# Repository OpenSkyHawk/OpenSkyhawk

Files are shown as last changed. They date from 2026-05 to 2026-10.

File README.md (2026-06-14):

```
  ____                ______        __ __            __  
 / __ \___  ___ ___  / __/ /____ __/ // /__ __    __/ /__
/ /_/ / _ \/ -_) _ \_\ \/  '_/ // / _  / _ `/ |/|/ /  '_/
\____/ .__/\__/_//_/___/_/\_\\_, /_//_/\_,_/|__,__/_/\_\ 
    /_/                     /___/                        
          ── DCS A-4E Skyhawk Home Cockpit ──
```

Physical DCS A-4E Skyhawk home cockpit — 3D-printed panels, custom PCBs, and STM32 firmware for the [DCS A-4E Community Mod](https://github.com/Community-A-4E/community-a4e-c). Controllers communicate over CAN bus.

## Repository Structure

```
OpenSkyhawk/
├── CAD/                        # Fusion 360 source files (.f3d); STLs gitignored
│   ├── Center_Console/
│   ├── Left_Console/
│   ├── Right_Console/
│   └── Shared/                 # Common brackets, mounting fixtures
│
├── PCB/                        # KiCad projects, one folder per board
│   ├── Center_Console/
│   │   └── Center_Armament/
│   │       ├── Armament_MCU/   # Main STM32 board
│   │       ├── AWRS_Panel/     # Breakout board
│   │       └── Misc_Switch_Panel/
│   ├── Left_Console/
│   ├── Right_Console/
│   └── Libraries/              # Shared KiCad symbols and footprints
│
├── Firmware/                   # PlatformIO projects, one folder per STM32 controller
│   ├── Center_Armament/
│   └── Libraries/              # Shared firmware code
│
└── docs/
    ├── References/             # Cockpit photos, manuals, screenshots
    ├── Datasheets/             # Component datasheets
    └── claude/                 # AI-readable architecture and standards docs
```

## Architecture

Each physical panel group is driven by one **STM32F103CBT6** MCU board. Boards communicate over **CAN bus** via Molex Mini-Fit Jr connectors. Panel breakout boards connect to their MCU board via 6- or 8-pin JST-XH harnesses. Firmware is built with **PlatformIO**.

DCS communication: DCS-BIOS cockpit state flows PC → USB CDC → RP2040 bridge (Tiny2040) → UART → STM32 CAN master → CAN bus → all avionics nodes. STM32 native USB CDC is not used — it crashes under sustained DCS-BIOS load.

## Console Layout

| Console | Panels |
|---|---|
| Center Console | Armament, AWRS, Misc Switches, main flight instruments |
| Left Console | ECM, fuel, electrical systems |
| Right Console | Radios, nav |

## Hardware Notes

### Screw Standards

| Size | Use |
|---|-----|
| M2 | PCB mounts, small standoffs |
| M3 | Placards, light rings, small brackets |
| M4 | Instrument bezels, gauge mounting — clearance Ø4.3–4.5 mm |
| M5 | Panel-to-subpanel, corner mounts — clearance Ø5.3–5.5 mm |

### Switch Sizing

- Toggle switches: 12 mm (standard panels), ~6 mm (ECM modules)

### Gauges

- LOX gauge: 2-5/8″ (~67 mm total)
- Radar Altimeter: 3-1/8″ (~100 mm total with bezel)

## Licensing

Copyright (c) 2026 OpenSkyHawk.

| Layer | License |
|---|---|
| CAD, PCB, Docs | CC BY-NC-SA 4.0 — root [LICENSE](./LICENSE) |
| Firmware | GPL v2 (DCS-BIOS dependency) — [Firmware/LICENSE](./Firmware/LICENSE) |

GitHub's repo-level badge reflects the root `LICENSE` (CC BY-NC-SA 4.0); the
firmware is GPL v2 under `Firmware/LICENSE`.

## References

- [Open Hornet Hardware](https://github.com/jrsteensen/OpenHornet)
- [Open Hornet Software](https://github.com/jrsteensen/OpenHornet-Software)
- [The Warthog Project](https://thewarthogproject.com/)
- [Viperpits](https://www.viperpits.org/smf/index.php)
- [The Skyhawk Association — Cockpit](https://skyhawk.org/page/skyhawk-cockpit)

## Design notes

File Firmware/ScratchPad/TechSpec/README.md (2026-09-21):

# TechSpec — Technical Specifications

## Purpose

This directory contains per-library and per-class technical specifications for the OpenSkyhawk
firmware. Each file defines the *how* — public API, class structure, method signatures, file
layout, and implementation notes.

**FirmwarePlan/** defines the *what* (contracts, data flows, design decisions).
**TechSpec/** defines the *how* (concrete code structure, ready for implementation).

---

## Relationship to FirmwarePlan

Every TechSpec file references one or more FirmwarePlan documents. The FirmwarePlan is the
authority on behaviour — if there is a conflict between a TechSpec and FirmwarePlan, the
FirmwarePlan wins and the TechSpec must be updated.

FirmwarePlan files live at:
`Firmware/ScratchPad/FirmwarePlan/`

---

## How to Write a TechSpec

Each file follows this structure:

```markdown
# <ClassName> — Technical Specification

**Status:** Not started | In progress | Ready for implementation | Done
**FirmwarePlan ref:** <path to relevant FirmwarePlan file(s) and section>
**Depends on:** <list of other TechSpec files that must be implemented first>

---

## Responsibility
One paragraph — what this class does and what it does NOT do.

## File Layout
Header and source file names, directory location in the repo.

## Public API
Full class declaration with all public methods, constructors, and constants.
Include parameter types, return types, and a one-line description per method.

## Key Data Structures
Any structs, enums, or typedefs owned by this class.

## Implementation Notes
Non-obvious details: timing, ISR constraints, register sequences, library quirks.

## Dependencies
External libraries, other OpenSkyhawk classes, platform requirements.
```

Testing is continuous throughout implementation — not a separate phase or document.
Each class should be exercisable in isolation before integration. Build test sketches
alongside the library as you go.

---

## Timing Standard

Each class that needs timing calls `millis()` directly and maintains its own `uint32_t`
timestamp. There is no shared clock or centralized `now` on STM32Board.

`millis()` on STM32 reads a 32-bit hardware counter — effectively free. Multiple calls
within one loop iteration return values microseconds apart, which is irrelevant at the
timing granularity used here (debounce ~20 ms, blink 250 ms+, heartbeat 500 ms).

This keeps each class fully self-contained. A Switch2Pos has no dependency on STM32Board
just to debounce a pin.

---

## Code Documentation — Docblock Standard

All header files use **Doxygen-style docblocks**. This applies to every public class, method,
enum, and non-obvious constant. Private members use plain `//` comments.

### Format

```cpp
/**
 * @brief One-line summary of what this does.
 *
 * Optional longer description for non-obvious behaviour, constraints, or side effects.
 * Omit if the brief is sufficient.
 *
 * @param name     Description of the parameter.
 * @param other    Description of another parameter.
 * @return         What the function returns, and what values mean.
 * @note           Non-obvious constraint or timing requirement.
 */
```

### Rules

- **Every public method gets a `@brief`** — even if it seems obvious.
- **`@param` for every parameter** — include units where relevant (ms, Hz, steps).
- **`@return` when the return value is non-trivial** — omit for `void`.
- **`@note` for ISR/timing/threading constraints** — e.g. "must not be called from ISR".
- **Enums:** document the enum with a `/** @brief */` block; document each value with `///< inline`.
- **Constants:** one-line `///` or `///<` inline comment is sufficient.

### Example

```cpp
/** @brief CAN bus health states reported to STM32Board via onCanStatus(). */
enum class CanStatus {
    STARTING,   ///< CAN peripheral configured but not yet started
    NORMAL,     ///< Bus active, no errors
    TX_ERROR,   ///< TEC > 0 — transmit errors accumulating
    BUS_OFF,    ///< CAN controller halted — bus-off condition
};

class CANProtocol {
public:
    /**
     * @brief Start the CAN peripheral and enable receive filters.
     *
     * Must be called after STM32Board::begin(). Sets status to NORMAL on success
     * and fires the registered onStatusChange callback.
     */
    static void start();

    /**
     * @brief Register a callback invoked whenever CAN bus status changes.
     * @param cb Function pointer called with the new CanStatus value.
     * @note Callback is called from the CAN RX interrupt — keep it short.
     */
    static void onStatusChange(void (*cb)(CanStatus));
};
```

---

## Status Tracking

Each file has a **Status** field in its header. Valid values:

| Status | Meaning |
|---|---|
| `Not started` | Placeholder only — spec not yet written |
| `In progress` | Spec being written |
| `Ready for implementation` | Spec complete — can be handed off for coding |
| `Implementing` | Code being written |
| `Done` | Implemented and tested |

---

## Implementation Order

Dependencies flow downward — implement in this order:

```
HIDControls         (no dependencies — platform-agnostic header; shared by STM32 and RP2040)
A4EC                (no dependencies — generated by running tools/gen_a4ec/gen_a4ec.py)
CANProtocol         (depends on HIDControls — includes HIDControls.h)
STM32Board          (depends on CANProtocol for the CanStatus event type)
  ↑ implement HIDControls first; then A4EC and CANProtocol (either order); then STM32Board
PanelBridge         (depends on CANProtocol, STM32Board, A4EC)
SimGateway          (depends on HIDControls — CTRL_* constants used in sketch declarations)
  ↑ build the bridge/gateway backbone before the large PanelGroup surface
  └── PanelGroup/
        ├── PinRef              (no dependencies)
        ├── PanelGroup          (depends on PinRef, CANProtocol, STM32Board;
        │                         owns MCP23017 integration via external library)
        ├── Inputs/
        │     ├── Switch2Pos              (depends on PinRef, PanelGroup)
        │     ├── Switch3Pos              (depends on PinRef, PanelGroup)
        │     ├── SwitchMultiPos          (depends on PinRef, PanelGroup)
        │     ├── AnalogMultiPos          (depends on PinRef, PanelGroup)
        │     ├── ActionButton            (depends on PinRef, PanelGroup)
        │     ├── SwitchWithCover2Pos     (depends on Switch2Pos — protected emit() hook)
        │     ├── RotaryEncoder           (depends on PinRef, PanelGroup)
        │     ├── RotaryAcceleratedEncoder (depends on RotaryEncoder — family member, D16)
        │     ├── AnalogInput             (depends on PinRef, PanelGroup)
        │     └── AngleSensorInput        (depends on AnalogInput, PinRef)
        │         (AngleSensor = future PinRef backend for a digital I²C read — see AngleSensor.md)
        │     (RotarySwitch dropped — D16)
        ├── Drivers/
              │     ├── MotorDriver       (abstract base — depends on PanelGroup)
              │     └── StepperMotor      (depends on MotorDriver, PinRef, PanelGroup)
        └── Outputs/
              ├── LED                     (depends on PinRef, PanelGroup)
              ├── AnalogOutput            (abstract family base — depends on PanelGroup; D16)
              │     ├── Dimmer            (depends on AnalogOutput, PinRef — PWM backlight)
              │     └── IntegerOutput     (depends on AnalogOutput — user callback)
              └── NeedleGauge             (depends on PanelGroup, Drivers/MotorDriver + StepperMotor;
                                           supersedes SwitecX25Output / AccelStepperOutput / ServoOutput)

Note: PanelGroup sketches (per-panel main.cpp files) depend on both the PanelGroup
library and A4EC (for DCSIN_* constants). The PanelGroup library itself does not.
```

---

## Library and Test Project Structure

### Library layout

Every STM32 library lives under `Firmware/Libraries/<LibraryName>/` and must include
a `library.json` so PlatformIO can resolve it as a local dependency:

```
Firmware/Libraries/<LibraryName>/
├── <LibraryName>.h
├── <LibraryName>.cpp
└── library.json
```

Minimal `library.json`:
```json
{
  "name": "<LibraryName>",
  "version": "0.1.0",
  "frameworks": "arduino",
  "platforms": "ststm32"
}
```

### Test project layout

Each library has a companion test project at `Firmware/Tests/<LibraryName>/`. The test
project is a standalone PlatformIO project that references the library as a local dependency.
Each test scenario is a separate `.cpp` file in its own subdirectory under `tests/`:

```
Firmware/Tests/<LibraryName>/
├── platformio.ini
└── tests/
    ├── <scenario_a>/
    │   └── <scenario_a>.cpp
    ├── <scenario_b>/
    │   └── <scenario_b>.cpp
    └── <scenario_c>/
        └── <scenario_c>.cpp
```

### `platformio.ini` template

`src_dir` is a project-level setting — it goes in `[platformio]`, not `[env:]`.
`build_src_filter` patterns are relative to `src_dir`. `[env_base]` is a custom section;
environments inherit from it via `extends = env_base`.

```ini
[platformio]
src_dir = tests

[env_base]
platform = ststm32@^20.0.0
board = genericSTM32F103C8
framework = arduino
build_flags = -DNODE_ID=1
lib_extra_dirs = ${PROJECT_DIR}/../../Libraries
lib_deps = <LibraryName>

[env:test_<scenario_a>]
extends = env_base
build_src_filter = -<*> +<<scenario_a>/<scenario_a>.cpp>

[env:test_<scenario_b>]
extends = env_base
build_src_filter = -<*> +<<scenario_b>/<scenario_b>.cpp>
```

`-<*>` drops the default `src/` folder; `+<tests/foo.cpp>` adds only that file as the
entry point. Switch environments from the VSCode status bar or with
`pio run -e test_<scenario> -t upload` on the CLI.

---

## Referencing FirmwarePlan

When writing a TechSpec, always link to the specific FirmwarePlan section that defines the
behaviour. Use this format in the **FirmwarePlan ref** field:

```
FirmwarePlan/05-panelgroup-api.md#switch2pos
FirmwarePlan/02-can-protocol.md#controlpacket-wire-format
```

If the spec contradicts FirmwarePlan, raise it as a conflict — do not silently diverge.

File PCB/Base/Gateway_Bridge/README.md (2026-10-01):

# Gateway_Bridge — Gateway/Bridge board (SimGateway + PanelBridge)

**Status: In progress** — not released yet.

A board is released only once it has been built, brought up, and verified: it is then listed in `PCB/manifest.yaml` and ships in the next hardware release (`hardware-vX.Y.Z`, see the repository's Releases). The model is design decision D10; the release standard is the *Releases* section of `docs/_source/hardware-standards.md`.

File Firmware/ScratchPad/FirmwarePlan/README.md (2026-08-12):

# OpenSkyhawk Firmware Plan

This directory contains the firmware specification for the OpenSkyhawk physical DCS A-4E
Skyhawk cockpit. Documents are split by contract boundary — each file owns one stable interface
and references others rather than repeating them.

## System Topology

```
PC
 ↕ USB HID          (joystick axes + buttons — flight controls only)
 ↕ USB CDC @ 250000 (DCS-BIOS full-state stream, raw bytes both directions)
RP2040 — SimGateway  [one per cockpit]
 ↕ UART @ 250000   (DCS-BIOS stream + HID frames, bidirectional)
STM32F103 — PanelBridge  [one per cockpit — runs DCS-BIOS library]
 ↕ CAN bus @ 500 kbps
 ├── PanelGroup #1   (e.g. Center_Armament)
 ├── PanelGroup #2   (e.g. Left_ECM)
 └── PanelGroup #N   (up to ~20 nodes)
```

## Document Map

| File | Owns |
|---|---|
| `00-decisions.md` | Architecture decision records — *why* each choice was made |
| `01-system-overview.md` | Project goal, topology, library roles, data flow narrative |
| `02-can-protocol.md` | CAN frame IDs, `NODE_ID`, `ControlPacket` struct, TX queue policy |
| `03-uart-usb-hid-protocol.md` | UART multiplexing, HID frame wire format, parser resync, USB identity, CDC calibration protocol |
| `04-dcs-bios-integration.md` | `controlId` address space, `DCSIN_*` rationale, `DcsBiosInputEntry` struct, generator rules |
| `05-panelgroup-api.md` | `PinRef`, MCP23017 management, all input classes, all output classes |
| `06-panelbridge-api.md` | Node tracking, `ExportStreamListener`, input dispatch, SYNC_REQ triggers |
| `07-simgateway-api.md` | `HIDAxis`, `HIDButton`, relay contract, HID dispatch logic |
| `08-hardware-firmware-contracts.md` | STM32 pin assignments, DRV8833 ~SLEEP contract, ADS1115 assumptions |
| `09-startup-resync-diagnostics.md` | Boot sequences (all three nodes), SYNC_REQ/READY handshake, DIAG frames |
| `10-implementation-plan.md` | Phased task list (Phases 1–6) |
| `11-open-issues.md` | Deferred decisions, conditional revisit items, cross-document discrepancies |
| `examples/panelgroup-center-armament.md` | Full PanelGroup sketch with data flow |
| `examples/panelbridge.md` | Full PanelBridge sketch |
| `examples/simgateway.md` | Full SimGateway sketch with data flow |

## How to Use These Documents

**Reading order for new contributors:**
1. `00-decisions.md` — understand the *why* before the *what*
2. `01-system-overview.md` — get the big picture
3. The contract file for the layer you are working on (02–09)
4. Relevant example in `examples/`

**When adding a feature:**
- Identify which contract file owns the interface you are changing.
- Update that file first; update cross-references in other files if the interface changes.
- Do not duplicate constants or behaviour — add a "See `xx-filename.md#section`" cross-reference.

**CAN IDs are defined only in `02-can-protocol.md`.** Other files reference them with
"See `02-can-protocol.md#frame-type-table`" rather than restating values.

## Source of Truth

This directory is the authoritative firmware specification. `CLAUDE.md` and
`docs/_source/architecture.md` link here and defer to this directory for all firmware
decisions. If there is ever a conflict between a `docs/_source/` file and a FirmwarePlan
document, the FirmwarePlan wins.

`Firmware/ScratchPad/REQUIREMENTS.md` is the original monolithic PRD this directory was split
from. It is superseded by the files here.

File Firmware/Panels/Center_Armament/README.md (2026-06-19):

# Center_Armament Firmware

STM32F103CBT6 CAN avionics controller for the Armament Panel (host) + AWRS
Panel and Misc Switch Panel (breakouts). Communicates with the rest of the
cockpit exclusively over CAN bus — it does not run DCS-BIOS and has no direct
connection to the PC or the RP2040 gateway.

For pinout, I²C addresses, and DCS-BIOS mappings see
`docs/_source/controllers/Center_Armament.md`.

## Development Notes

When prototyping with a **Chinese Blue Pill clone** (STM32F103C8T6), ST-Link
may refuse to connect because the clone reports JTAG ID `0x2ba01477` instead
of the standard `0x1ba01477`. Override it in `platformio.ini`:

```ini
upload_flags =
    -c
    set CPUTAPID 0x2ba01477
debug_extra_cmds = set CPUTAPID 0x2ba01477
```

Full debug session notes (DCS-BIOS, USB CDC issues, UART bridge) are in
`docs/_source/dcsbios-stm32-debug.md` — those findings apply to the STM32 CAN
master node, not to this panel node.

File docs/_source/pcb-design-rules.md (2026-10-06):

# PCB Design Rules

Fabricator: **JLCPCB**, standard 2-layer service.

All KiCad projects are scaffolded with these constraints pre-loaded via `/new-kicad-project`.
The custom DRC rule file is at `PCB/Libraries/design-rules/jlcpcb-standard.kicad_dru`.

---

## Minimum Design Rules (JLCPCB Standard 2-Layer)

| Constraint | Value | Notes |
|---|---|---|
| Min trace width | **0.2 mm** | JLCPCB floor is 0.127mm; bumped to match Default class — DRC violations are always meaningful |
| Min trace spacing / clearance | **0.2 mm** | JLCPCB floor is 0.127mm; bumped — all IC packages in this build are compatible (see note below) |
| Min via drill | **0.3 mm** | Smaller (0.2mm) requires advanced service |
| Min via annular ring | **0.13 mm** | Pad = drill + 2 × ring → 0.3 + 0.26 = **0.56 mm** min pad |
| Min PTH drill-to-copper | **0.254 mm** | Clearance from PTH edge to nearest copper |
| Min hole-to-hole (edge to edge) | **0.5 mm** | Between any two drilled holes |
| Min copper-to-board-edge | **0.3 mm** | Copper must stay ≥ 0.3mm inside board outline |
| Min silkscreen stroke | **0.153 mm** | Use 0.15mm in KiCad (rounds up at fabrication) |
| Min silkscreen text height | **0.8 mm** | 1.0mm recommended for legibility |
| Board outline line width | **0.05 mm** | Edge.Cuts layer — thinner = more accurate |
| Copper weight | **1 oz** | Standard; heavier copper adds cost |

---

## Predefined Sizes in KiCad Template

These are pre-loaded in `template.kicad_pro` and appear in the "Interactive Router Settings" dropdowns.

### Track widths

| Width | Use |
|---|---|
| 0.2 mm | Signal traces (default) — comfortably above 0.127mm minimum |
| 0.3 mm | LED string feeds — required per hardware-standards.md; ~0.75A capacity |
| 0.5 mm | 5V / 3.3V power traces — ~1.2A capacity |
| 1.0 mm | 12V main power — ~2.5A capacity; covers full 1.8A LED load with margin |

Current capacity estimates at 1oz copper, 10°C temperature rise (IPC-2221B).

**Package compatibility note:** LQFP48 (STM32) and HTSSOP-16 (DRV8833PW) have pad gaps of 0.28mm and 0.35mm respectively — too narrow to route between pads at 0.2mm clearance regardless. Use pad-end escape routing for both (best practice anyway). SOIC-8/28 (1.27mm pitch, 0.67mm gap) routes comfortably between pads at 0.2mm clearance.

### Via sizes

| Drill | Pad | Use |
|---|---|---|
| 0.3 mm | 0.6 mm | Standard via — signal and low-current power; minimum JLCPCB spec |
| 0.4 mm | 0.8 mm | Power / stitching vias — 12V and GND planes |

---

## Default KiCad Text Settings (Silkscreen)

| Setting | Value |
|---|---|
| Text height | 1.0 mm |
| Text stroke | 0.15 mm |
| Fab / copper text height | 1.0 mm |
| Fab / copper text stroke | 0.15 mm |

---

## JLCPCB Ordering Settings (Cost-Optimised)

These settings minimise cost on every order. Select them in the JLCPCB order page under **High-Spec Options**.

| Option | Setting | Notes |
|---|---|---|
| Outer Copper Weight | **1 oz** | Standard; sufficient for all current loads in this build |
| Via Covering | **Tented** | Soldermask over via pads; cheapest; no "via-in-pad" issues |
| Via Plating Method | **Not Specified** | No preference — cheapest default |
| Min Via Hole / Diameter | **0.3mm / (0.4/0.45mm)** | Matches template minimum; standard tier |
| Board Outline Tolerance | **±0.2mm (Regular)** | Sufficient for panel fit; precision adds cost |
| Confirm Production File | **No** | Skip manual review; reduces lead time |
| Mark on PCB | **Remove Mark** | No JLCPCB branding mark on board |
| Electrical Test | **Flying Probe Fully Test** | Included at standard tier; catches open/short faults |
| Gold Fingers | **No** | |
| Castellated Holes | **No** | |
| Edge Plating | **No** | |
| Blind Slots | **No** | |
| UL Marking | **No** | |
| Humidity Indicator Card | **No** | |

---

## KiCad Layer Stackup

Standard 2-layer assignment:

| Layer | Use |
|---|---|
| F.Cu | Component-side copper |
| B.Cu | Back copper |
| F.Paste | Front solder paste (SMD) |
| B.Paste | Back solder paste (SMD) |
| F.Silkscreen | Component labels, reference designators |
| B.Silkscreen | Revision line only (`REVISION x.y.z \| BOARD NAME` — `hardware-standards.md`, *Silkscreen*); otherwise keep clear for inspection |
| F.Courtyard | Component keep-out areas |
| B.Courtyard | Component keep-out areas (back) |
| Edge.Cuts | Board outline — 0.05mm line width |

---

## Component Placement Rules

- **Front face:** LEDs only
- **Back face:** all other components (ICs, passives, connectors, MOSFETs)
- Connectors: through-hole, vertical — accessible from the panel side
- PTH components extend through to front face — ensure no silk or copper conflict with LED pads

---

## Net Classes

Four net classes are pre-loaded in `template.kicad_pro`. Pattern-matched nets are assigned automatically; `LED_String` requires manual assignment in the PCB editor.

| Class | Track | Clearance | Via drill/pad | Assignment |
|---|---|---|---|---|
| `Default` | 0.2 mm | 0.127 mm | 0.3/0.6 mm | All nets not listed below |
| `LED_Trunk` | 0.5 mm | 0.127 mm | 0.4/0.8 mm | Auto: `+12V_BACKLIGHT`, `BACKLIGHT_SW_RETURN` |
| `LED_String` | 0.3 mm | 0.127 mm | 0.3/0.6 mm | Manual — per-string traces (resistor → 5× LEDs) |
| `CAN` | 0.2 mm | 0.2 mm | 0.3/0.6 mm | Auto: `CANH`, `CANL`; route as diff pair (0.2 mm gap) |

**LED_Trunk sizing rationale:** zone trunk carries all strings in parallel. At 18 mA/string, 0.5 mm handles up to 30 strings (540 mA) with 2.2× margin at 1oz copper.

**LED_String manual assignment:** per-string nets between resistor and LED chain are unnamed in KiCad (auto-named `Net-(Rx-Pad2)`); pattern matching cannot reach them. Select 0.3 mm from the predefined widths dropdown when routing these traces.

### Deferred — Power net classes

Power net classes (`Power_12V`, `Power_LV`) are **not yet defined**. They depend on actuator architecture (servos, solenoids, large steppers) that is not yet finalised. Revisit when the first actuator board is designed.

**Established boundary:** logic + LED boards must stay ≤ 500 mA total 12V input. Actuator boards are sized to their specific loads with no general limit — those boards require separate design review (see Actuator Boards section below).

---

## Board Power Budget

### Logic + LED boards (MCU and breakout)

Target: **≤ 500 mA at 12V input per board.**

| Rail | Typical load | Max expected |
|---|---|---|
| 12V → LEDs | 54–180 mA (3–10 strings) | ~360 mA (20 strings, large panel) |
| 12V → AP63205 input | ~100 mA | ~150 mA |
| **Total 12V per board** | ~160–280 mA | ~510 mA (large panel edge case) |
| 5V (DRV8833 stepper VM) | 15–30 mA | 50 mA |
| 3.3V (STM32 + MCP23017 + CAN) | ~125 mA | ~175 mA |

**System total (full cockpit ~20 boards):** ~2.3 A at 12V. PC ATX 500–600W supply provides 35–40A on 12V — <7% utilisation.

### Actuator boards (solenoids, servos, large steppers)

**Not yet designed.** Each actuator board requires its own power budget analysis before PCB work begins. Minimum considerations:

- [ ] Solenoid / electromagnetic switch: confirm coil resistance, voltage, duty cycle, and whether flyback protection is needed (it almost certainly is — add TVS or flyback diode)
- [ ] Servo: confirm supply voltage (5V or dedicated), stall current, and whether a separate high-current supply rail is needed
- [ ] Large stepper (NEMA 14/17): confirm driver IC (the DRV8833 gauge driver is **not** suitable — max ~1.5A/phase; use DRV8825, TMC2209, or similar), current per phase, and microstepping requirements
- [ ] Decide: high-current actuator load on same board as logic, or dedicated driver board with separate power connector?

---

## Custom DRC Rules

`PCB/Libraries/design-rules/jlcpcb-standard.kicad_dru` is copied into each new project by `/new-kicad-project`.

To activate in an existing project: open the PCB editor → **File → Board Setup → Design Rules → Custom Rules** → paste the file contents (or browse to the file).

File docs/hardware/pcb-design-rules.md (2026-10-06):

# PCB Design Rules

Every OpenSkyhawk board is fabbed at **JLCPCB, standard 2-layer service**. These rules are
pre-loaded into each new KiCad project by the `/new-kicad-project` scaffold — you shouldn't have
to set them by hand. This page is the reference.

## Minimum design rules

| Constraint | Value | Notes |
|---|---|---|
| Min trace width | **0.2 mm** | JLCPCB floor is 0.127 mm; bumped so DRC violations are meaningful |
| Min spacing / clearance | **0.2 mm** | all IC packages in this build route fine at 0.2 mm |
| Min via drill | **0.3 mm** | smaller needs advanced service |
| Min via annular ring | **0.13 mm** | → 0.56 mm min pad |
| Min PTH drill-to-copper | **0.254 mm** | |
| Min hole-to-hole | **0.5 mm** | edge to edge |
| Min copper-to-edge | **0.3 mm** | |
| Min silk stroke | **0.153 mm** | use 0.15 mm in KiCad |
| Min silk text height | **0.8 mm** | 1.0 mm recommended |
| Board outline width | **0.05 mm** | Edge.Cuts |
| Copper weight | **1 oz** | standard |

!!! note "Routing between IC pads"
    LQFP48 and HTSSOP pad gaps are too narrow to route between at 0.2 mm clearance regardless —
    use pad-end escape routing (best practice anyway). SOIC-8/28 (1.27 mm pitch) routes
    comfortably between pads.

## Net classes

Four classes are pre-loaded; pattern-matched nets are assigned automatically.

| Class | Track | Via | Assignment |
|---|---|-----|---|
| `Default` | 0.2 mm | 0.3/0.6 mm | everything not below |
| `LED_Trunk` | 0.5 mm | 0.4/0.8 mm | auto: `+12V_BACKLIGHT`, `BACKLIGHT_SW_RETURN` |
| `LED_String` | 0.3 mm | 0.3/0.6 mm | **manual** — per-string traces (resistor → 5 LEDs) |
| `CAN` | 0.2 mm | 0.3/0.6 mm | auto: `CANH`, `CANL` — route as a diff pair (0.2 mm gap) |

`LED_String` nets are auto-named by KiCad, so pattern matching can't reach them — pick 0.3 mm
from the predefined widths when routing those traces.

## Predefined track widths

| Width | Use |
|---|-----|
| 0.2 mm | signal (default) |
| 0.3 mm | LED string feeds (~0.75 A) |
| 0.5 mm | 5 V / 3.3 V power (~1.2 A) |
| 1.0 mm | 12 V main power (~2.5 A) |

## Placement

- **Front face: LEDs only.** Back face: ICs, passives, connectors, MOSFETs.
- Connectors: through-hole, vertical, accessible from the panel side.
- PTH parts extend through to the front — keep silk and copper clear of LED pads.

## Layer stackup

Standard 2-layer: F.Cu / B.Cu, F/B.Paste, F.Silkscreen, F/B.Courtyard, Edge.Cuts at 0.05 mm.
B.Silkscreen carries only the revision line (`REVISION x.y.z | BOARD NAME`) and is otherwise
kept clear for inspection — see [Silkscreen](standards.md#silkscreen).

## Board power budget

Logic + LED boards target **≤ 500 mA at 12 V input**. Full breakdown, plus the actuator-board
caveat, is on the [Power Architecture](../architecture/power.md) page.

## JLCPCB ordering (cost-optimised)

1 oz outer copper, tented vias, 0.3 mm min via, ±0.2 mm outline tolerance, flying-probe test,
remove JLCPCB mark, no gold fingers / castellation / edge plating. Skip manual file
confirmation to cut lead time.

## Custom DRC file

`PCB/Libraries/design-rules/jlcpcb-standard.kicad_dru` holds these as enforceable rules; it's
copied into each new project by the scaffold. To add to an existing project: **Board Setup →
Design Rules → Custom Rules** and paste it in.

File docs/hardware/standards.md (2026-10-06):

# Hardware Standards

The rules every OpenSkyhawk board follows. These aren't preferences — they're the constraints
that keep boards buildable, inspectable, and interchangeable across the cockpit. This page is
the hub; the detail lives on the pages it links.

## Component packages — must be inspectable

**Every package must be visually inspectable after reflow.** A T962 reflow oven handles the
soldering; the limit is *inspection*, not soldering. So bottom-terminated parts are out.

| Acceptable | Not acceptable |
|---|---|
| SOIC, SSOP, TSSOP, HTSSOP | QFN, DFN, WSON |
| LQFP | BGA, LGA |
| SOT-23, SOT-223 | any fully bottom-terminated package |
| Through-hole | |

HTSSOP is fine — its side leads are the critical joints; the exposed thermal pad is verified by
continuity check.

## MCU

- **CAN nodes: STM32F103** (LQFP48). All boards default to the **`STM32F103C8`** (64 KB) —
  both PanelGroup nodes and **PanelBridge** (which carries the DCS-BIOS input map but still
  compiles to ~26 KB flash). The **`STM32F103CB`** (128 KB) is a drop-in fallback on the same
  footprint, needed by no board currently.
- Requires an **external 8 MHz crystal** — the internal RC oscillator isn't accurate enough for
  500 kbps CAN.
- **PA11/PA12** are shared between USB and CAN; pick one at init (CAN, in production).
- **HID controls: RP2040** off-the-shelf modules (flight stick, throttle, pedals, button boxes).
  No custom PCB.

## Power

A PC ATX supply distributes **12 V and 5 V** on the main bus; **each board makes its own 3.3 V**
locally with an AMS1117-3.3. Local decoupling (100 nF + 10 µF per rail) is required on every
board. Full detail — rails, budgets, the switching buck for high-current boards — is on the
[Power Architecture](../architecture/power.md) page.

## CAN transceiver

**SN65HVD230** (SOIC-8, 3.3 V), one per STM32 board, on PA11 (RX) / PA12 (TX). 120 Ω
termination across CANH/CANL at the **two end nodes only**. See
[CAN Bus Protocol](../architecture/can-bus.md) for the protocol side.

## LED backlighting

Confirmed by bench testing: **5-LED series strings**, MOSFET-switched per zone, one
current-limiting resistor per string.

- 5 × 5050 red LEDs in series per string (~10 V at 12 V supply, ~2 V resistor headroom)
- One resistor per string — **120 Ω default** (≈18 mA); 100 Ω for bright panels, 180 Ω for
  dim/night zones. (47 Ω was rejected — the resistor overheated.)
- One **AO3400A** N-channel MOSFET per zone (SOT-23, 30 V — needed for margin over the 19.9 V
  SMBJ12A clamp on the 12 V rail; IRLML2502's 20 V sits too close), low-side, gate driven directly
  by STM32 3.3 V PWM (no gate driver). PWM duty sets average brightness.
- **LEDs on the front face; resistors, MOSFETs, and everything else on the back.**

## Shift-register I/O — 74HC165 / 74HC595 (ShiftBus)

The SPI shift-register backend for sub-panel I/O, bench-decided against the MCP23017
(see [D9](../architecture/design-decisions.md)). Panels are **I²C-class or SPI-class by
their connector**, chosen by physics: rotary encoders or fast gauges (≳150 °/s) → SPI-class;
everything else is fine on I²C-class. Key rules:

- **74HC165 inputs:** bussed 10 k resistor array to 3V3 on **all 8 inputs of every chip**,
  used or not; switch/encoder commons to GND (active-low).
- **74HC595 outputs:** indicator LEDs ≤4 mA drive directly with a series resistor; anything
  above ~6 mA, any 5 V/12 V rail load, or a chip total nearing 70 mA gets a 2N7002 MOSFET.
- **DRV8833 motor supply is 5 V — never the 12 V rail** (10.8 V absolute maximum).
  Servos take 12 V through a panel-local buck, never a 5 V rail.
- **The SPI bus is dedicated** — a '165's data output never tristates, so the bus is the
  shift chains' alone. Chains daisy without limit; capacity never needs a second bus.
- **Standard pins:** SCK=PB3 · MISO=PB4 · MOSI=PB5 · LOAD=PB8 · LATCH=PB9 — one contiguous
  header run with I²C1. I²C interrupt pins are assigned around it; see the reference below.

Full rules, the measured numbers, and chip-placement guidance:
`docs/_source/hardware-standards.md` (Shift-Register I/O section). Harness pinouts:
the [Connector & Harness Guide](connectors.md).

## Silkscreen

Checked on every board **before gerber export** — a silk error is only found after fab. Key rules:

- **Every power and bus connector pin is labelled with its signal** — `12V`, `5V`, `CANH`,
  `CANL`, `GND` beside each pad of the Mini-Fit Jr bus connectors. A reversed harness destroys
  the board, so here silk is a safety feature. Off-board headers (I²C, ShiftBus, SWD) get the
  same treatment.
- **Label the signal, not the net** — a pin behind a series resistor is `SDA`, not its
  auto-generated `Net-(J2-Pin_1)` name.
- **Legends are free silk text, never a footprint `Value` override** — an override breaks
  schematic parity and is silently deleted by the next *Update PCB from Schematic*.
- **Revision line on the back silk:** `REVISION 0.2.0 | BOARD NAME`, bumped in the same change
  as the board revision. Identify a board revision as `0.2.0` everywhere — "Rev 2" names a round
  of work, never the hardware.

Full rules, the text format, and the four-point pre-gerber gate:
`docs/_source/hardware-standards.md` (*Silkscreen*).

## Releases

Hardware releases work like firmware's: commits under `PCB/` keep a draft **release hardware
X.Y.Z** pull request up to date, and **merging it is the release** (`hardware-vX.Y.Z`). A release
means **the boards in it are ready** — built, brought up, and verified — and which boards those are
is listed in `PCB/manifest.yaml`. The release notes list each board and what changed in it. Every
board folder's `README.md` says whether it is **Released**, **In progress**, or **Deprecated**.
The model is [design decision D10](../architecture/design-decisions.md#d10-versioning-firmware-and-hardware-release-separately);
the standard and release checklist are in `docs/_source/hardware-standards.md` (*Releases*).

## The other reference pages

- **[Mechanical Standards](mechanical-standards.md)** — screws, gauges, switch sizes, panel dims
- **[PCB Design Rules](pcb-design-rules.md)** — JLCPCB constraints, net classes, stackup
- **[Connector & Harness Guide](connectors.md)** — Molex Mini-Fit Jr, JST-XH, wire gauge
- **[Component Library](components.md)** — the selected parts and their KiCad symbols
- **[KiCad Workflow](kicad-workflow.md)** — shared libraries, design rules, the CLI

!!! warning "MCP23017 GPA7 / GPB7 — output only"
    A confirmed silicon bug means **GPA7 and GPB7 must never be configured as inputs** — the SDA
    signal can be corrupted if the pin voltage changes mid-transmission. That leaves **14 input
    pins per chip** (GPA0–GPA6, GPB0–GPB6). GPA7/GPB7 may drive LEDs or other outputs freely.

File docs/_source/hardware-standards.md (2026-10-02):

# Hardware Standards

## Component Package Rules

**Constraint: all packages must be visually inspectable after reflow.** T962 reflow oven is available; the limitation is inspection, not soldering.

| Acceptable | Not acceptable |
|---|---|
| SOIC, SSOP, TSSOP, HTSSOP | DFN, WSON (true no-lead) |
| LQFP | BGA, LGA |
| SOT-23, SOT-223 | Any *fully* bottom-terminated package |
| Through-hole, QFN *(case-by-case — see below)* | |

HTSSOP (exposed thermal pad on underside) is acceptable — side leads are the critical joints; the GND pad is verified by continuity check.

**QFN — case-by-case, not a blanket ban.** A QFN whose perimeter leads are side-accessible (a solder fillet climbs the castellated edge) with only a GND center pad — e.g. the **RP2040 QFN-56** — is judged like HTSSOP: the side fillets are the inspectable critical joints; the center pad is GND (continuity-checked). It reflows on the T962 with a stencil, a reduced center-pad aperture (~50–70 %), and a proper profile. Only *fully* bottom-terminated packages — BGA, LGA, true no-lead DFN/WSON — are out, because there is no side joint to inspect.

## MCU

**Selected: STM32F103C8T6** — LQFP48, 64 KB flash, 20 KB RAM. Default for every board (PanelGroup and PanelBridge alike; PanelBridge's DCS-BIOS input map still compiles to ~26 KB). The **STM32F103CBT6** (128 KB flash) is a drop-in fallback on the identical LQFP48 footprint for any future build that exceeds 64 KB — no board currently needs it.

- Requires **external 8 MHz crystal** for reliable CAN bus timing (internal RC oscillator is not accurate enough for CAN bit-rate lock)
- **PA11/PA12** are shared between USB and CAN — the two peripherals cannot be used simultaneously; pick one at firmware init
- CAN bus is the primary inter-board protocol; USB used only for initial flashing/debug
- Use the bare die (not Blue Pill module) on MCU boards — fewer passive conflicts, smaller footprint

### Internal die-temperature telemetry (firmware-only)

Every STM32 CAN node reports its own MCU **internal die temperature** (ADC ch16) as cheap
health telemetry. This is a **firmware convention with no schematic or BOM impact** — the sensor
is on-die, needs no external parts, and applies to every existing and future STM32 board
unchanged. (Vrefint, ch17, is read on-node to reference the reading to Vdd, but Vdd itself is
not transmitted — per-node rail voltage is the PDU's job, not generic node health.)

- Sent on a dedicated **HEALTH_n CAN frame** (`0x140+n`), 1 s cadence, default-on. PanelBridge
  caches each node's value and forwards it to the host client. Firmware detail lives in the
  `firmware` skill / FirmwarePlan `02-can-protocol.md`.
- **The reading is UNCALIBRATED.** The STM32F103 temperature sensor has no factory trim, so
  absolute accuracy is only ~±few °C. It measures **die** temperature (not ambient) and carries
  a self-heat offset. Use it for **relative trend and a per-node overheat flag**, never as a
  precise ambient or hot-spot measurement.
- **Boards that need accurate hot-spot temperatures still use external NTCs** — e.g. the PDU's
  shunt/fuse zones. The internal sensor complements, does not replace, dedicated sensing.
- One reading per STM32 node. On a board that carries both an STM32 and an RP2040 (the shared
  Bridge/Gateway PCB), the STM32's HEALTH frame represents that board's thermal zone; the RP2040
  is not separately instrumented.

## RP2040 HID Controllers

**Role:** USB HID devices connecting directly to the PC — flight stick, throttle, rudder pedals, button boxes. No custom PCB; use off-the-shelf modules.

### Module Selection

| Module | Notes |
|---|---|
| Raspberry Pi Pico 2 | RP2350; preferred for new builds |
| Raspberry Pi Pico | RP2040; proven, widely available |
| Tiny2040 (Pimoroni) | Compact; USB-C; good for tight enclosures |
| RP2040 Zero (Waveshare) | Smallest footprint |

Choose by mechanical fit. All are equivalent for HID use.

### ADC Inputs

- 4 usable ADC channels (GPIO26–29); GPIO29 is used for VSYS monitoring on Pico modules — prefer GPIO26–28 for axes
- 12-bit ADC, 0–3.3V range
- Apply same RC input filter as STM32: 1 kΩ series + 100 nF to GND per axis input

**Analog expansion via ADS1115 (worth prototyping):** When more than 3 axes are needed, add ADS1115 breakout(s) over I²C — the same part already used on STM32 breakout boards.

**Selected: ADS1115IDGSR (TI)** — 16-bit ADC, VSSOP-10. **LCSC: C37593** _(note: LCSC description erroneously says QFN-10; IDGSR suffix = VSSOP-10 with gull-wing leads — inspectable)_

- 4 channels per chip, 16-bit, I²C
- Up to 4 chips per bus (addresses 0x48–0x4B via ADDR pin) = 16 channels per I²C bus
- RP2040 has two I²C buses; effectively unlimited axes in practice
- Library: Adafruit ADS1X15 (same as STM32 side — no new dependency)
- Use same RC filter (1 kΩ + 100 nF) on each ADS1115 input
- Prototype note: verify latency vs. onboard ADC for axis polling at HID report rate (~1 ms)

### UART (Gateway Role Only)

The RP2040 in the flight stick also bridges USB CDC serial to the CAN gateway STM32 via UART. See "Dual-MCU Architecture" in `architecture.md` for pin assignments and packet format. Non-gateway RP2040 boards (throttle, rudder, button boxes) do not use UART.

### Power

Bus-powered from USB. No 12V supply needed. If co-located with STM32 CAN hardware, share GND only — do not share 3.3V rails between the RP2040 module and STM32 board.

### Toolchain

PlatformIO with `earlephilhower/arduino-pico` platform (preferred) or Arduino IDE with Arduino-Pico core. TinyUSB is bundled with Arduino-Pico; use it for USB HID + CDC composite.

## Power Supply

**Architecture: PC ATX PSU distributes 12 V and 5 V on the main bus. Each board generates 3.3 V locally.**

| Stage | Part | Package | Notes |
|---|---|---|---|
| Main bus | PC ATX PSU | — | 12 V and 5 V distributed via Molex Mini-Fit Jr bus connectors |
| 5 V → 3.3 V | AMS1117-3.3 | SOT-223 | LDO on every MCU and breakout board; 5→3.3 V drop (1.7 V) acceptable at ≤175 mA load |
| 5 V rail | also feeds | — | DRV8833 VM (stepper driver motor supply) |
| 12 V → 5 V | AP63205WU | SOT-23-6 | **Only on high-5V-current boards** (future actuator/high-power boards). Not used on standard MCU or breakout boards. Typical BOM: C_in 10 µF, C_bypass 100 nF, L 4.7 µH, C_out 2×22 µF |

Local decoupling required on every board: 100 nF + 10 µF per rail, placed close to each IC. Never use a linear regulator for 12 V → 5 V conversion.

### Input-Rail Transient Protection (TVS)

**Fleet standard: every CAN-node board carries a unidirectional TVS from each input power rail to GND, at the input connector.** Cheap (~$0.10 ea) insurance against PSU power-on overshoot and hot-plug transients on the distributed 12 V / 5 V bus. Not strictly required indoors on a clean ATX PSU, but adopted fleet-wide because the transceiver's bus ESD does nothing for the power rails.

| Rail | Part | Package | LCSC | Symbol | Standoff | Clamp @ Ipp |
|---|---|---|---|---|---|---|
| +12 V input | **SMBJ12A** (unidir.) | SMB / DO-214AA | C42368008 | `OpenSkyhawk:SMBJ12A` | 12 V | 19.9 V @ 30.2 A |
| +5 V input | **SMBJ6.0A** (unidir.) | SMB / DO-214AA | C5331096 | `OpenSkyhawk:SMBJ6.0A` | 6.0 V | 10.3 V @ 58.3 A |

- **Placement:** at the input / injection connector, **cathode → rail, anode → GND**, before the fuse and bulk caps. Short, wide anode→GND path (low-inductance clamp reference). Reference designators are per-board (e.g. PDU: D1 = 12 V, D2 = 5 V).
- **Standoff sits above the rail (no knee operation):** the standoff (max continuous) voltage must exceed the rail's +5 % worst case — 12.6 V on the 12 V rail, 5.25 V on the 5 V rail. SMBJ12A (12 V standoff) leaks only 5 µA at the knee → fine as-is. On the 5 V rail, **SMBJ6.0A (6.0 V standoff) is chosen over SMBJ5.0A**: 5.0 V standoff sits *at* nominal and leaks up to 800 µA near the +5 % corner, whereas 6.0 V clears 5.25 V cleanly → leakage ~0 in normal operation. The 6.0 V part costs only ~1 V more clamp (10.3 V vs 9.2 V), still well under downstream limits.
- **Clamp headroom:** 12 V clamp 19.9 V < AP63205 abs-max 40 V and 25 V bulk caps; 5 V clamp 10.3 V < AMS1117 abs-max 15 V and DRV8833 VM abs-max 11.8 V.
- **12 V rail bulk cap ≥ 25 V.** The clamp voltage passes through the fuse onto the downstream bulk cap during a transient, so the cap must be rated above the clamp — a 16 V part would be over-stressed by the 19.9 V clamp on a hot-plug. (This is also why the 12 V rail stays on **SMBJ12A**, not SMBJ13A: 13A's 21.5 V clamp squeezes the margin for no leakage benefit.) **Fleet standard: use a 35 V part** (10 µF 0805 35V, LCSC `C49010152`) — 25 V is the hard minimum; 35 V gives comfortable derating over the 19.9 V clamp at negligible cost.

**CAN-bus TVS is deliberately excluded.** The SN65HVD230 transceiver already carries ±16 kV HBM built-in bus ESD, which covers the realistic indoor threat (handling ESD). An external CAN TVS (e.g. PESD1CAN) only buys industrial surge / EFT margin that an indoor cockpit with short CAN runs will never see. Do not populate CAN-bus TVS — optionally leave a DNP footprint on the CAN pair only.

> **Status: adopted.** Part selection is a paper decision (catalog TVS, spec-guaranteed clamp) — the SMBJ6.0A choice designs out the 5 V leakage concern, so no dedicated bench campaign is required. First fabricated on the PDU board (#202); confirm at the PDU's normal power-on (rails read normal, TVS parts cool). Roll-in to `PanelGroup_Base` / `Gateway_Bridge` (drop-in — identical DO-214AA footprint) and extraction into the #201 `Power` design block ride the boards' next revision.

## Stepper Driver

**Selected: DRV8833PWPR (TI)** — dual H-bridge, TSSOP-16-EP. **LCSC: C50506**

DRV8835 was considered but is only available in WSON-12 (fully bottom-terminated, not inspectable after reflow). DRV8833PW is the same electrical capability in an inspectable HTSSOP-16 package.

- Drives one X27.589 Switec stepper (bipolar, **~945 partial steps/315°** = 1/3°/step, 1080 steps/full-rev; 180–300 Ω coils, ~15–30 mA at 5 V)
- VM supply: 2–10.8 V (use 5 V); VINT: 3.3 V output (bypass with 100 nF to GND — do not drive with external supply)
- VCP (charge pump): 100 nF cap to VM — required for internal charge pump
- **~SLEEP pin (active LOW) — sim-gated, not held HIGH.** The driver **sleeps** (~SLEEP LOW) until the sim connects; on connect the firmware drives ~SLEEP HIGH, runs the homing sequence, then **syncs the gauge to the current DCS value**; on disconnect it returns ~SLEEP LOW. This de-energises the coils when idle (no holding current / heat — important for the heavier servos) and gives free power-up anti-twitch (coils off until there is something to display). ~SLEEP must be a **controlled GPIO** — STM32 GPIO on host boards, an **MCP23017 output on sub-panels** — with a **10 kΩ pull-down to GND** so it defaults LOW (asleep) before the MCU/MCP configures it. **Never tie ~SLEEP to +3V3.**
- AISEN / BISEN: current sense inputs — tie to GND (no current regulation needed; X27.589 coil resistance limits current naturally at 5 V)
- ~FAULT: open-drain fault output — leave NC in this revision
- No current-regulation passives needed; X27.589 coil resistance limits current naturally at 5 V
- Firmware: **`StepperMotor`** (SwitecX25 accel ported in-tree; STALL & SENSOR homing) — see *Stepper drive* below
- KiCad symbol: `Driver_Motor:DRV8833PW` (built-in)

### Stepper drive — resolution, homing, and I²C-expander limits

**Resolution (X27.589 / VID-29 / BKA-30 air-core family).** `StepperMotor` drives the datasheet **partial step = 1/3°/step** (1080 steps/full-rev) via the 6-state air-core sequence. Full step = 1°; micro step = 1/12° (PWM current control) is **not used** — the DRV8833 has no indexer and the firmware drives plain digital coil states. 1/3° (~960 positions over a 320° gauge) is ample; microstepping is a deferred option (see #122).

**Homing (STALL).** `StepperConfig.rangeSteps` is the **mechanical stop-to-stop travel** (~945 for an X27.589 315°, ~960 for a 320° BKA-30) — distinct from `stepsPerRev` (the full 360° revolution, used for degree↔step and `wrap`). STALL home drives `rangeSteps` (+ a 1/8 margin), **not** a full revolution: over-driving a stop-limited gauge by the rev−range difference grinds the seated rotor and desyncs it, so the zero wanders between homes. The seek runs at `homeStepUs` (default 2000 µs ≈ 500 steps/s), which **must stay under the air-core start-stop speed** (~774 steps/s ≈ 1290 µs/step) — the former 800 µs (1250 steps/s) sat at that edge and caused the "home left, then home right" band-swap.

**Coil drive path & speed envelope** (bench-measured 2026-06-21, BKA-30 on DRV8833 @ 5 V):

| Path | Step rate | ≈ °/s | Notes |
|---|---|---|---|
| Native STM32 GPIO | ~1667 steps/s | ~600 | motor-limited (datasheet max with accel) |
| MCP23017 @ 400 kHz | ~490 steps/s | ~163 | batched port write; I²C-overhead-limited |
| MCP23017 @ 100 kHz | ~260 steps/s | ~87 | for long / loaded buses |

- **STM32F103 I²C ceiling = 400 kHz** (no fast-mode-plus on the F1 peripheral).
- **Batched port write:** `StepperMotor` writes all four coils in **one** `writePort()` per step (`PanelGroup::flushExpanderWrites()`), not four per-pin read-modify-writes — fewer I²C transactions, lower bus occupancy, and an **atomic coil transition** (no mixed-coil intermediate state). **Caveat: the batched write rewrites the whole 8-bit port from cache, so stepper coils must OWN their MCP23017 port** — do not place unrelated I/O on the other pins of that port. `StepperMotor::configure()` enforces the placement half of this: four coils split across two ports, or two chips, are refused and logged, and the motor stays idle rather than stepping on a half-applied pattern.
- **Rule of thumb:** a gauge needing fast slews → coils on **native GPIO**; a slow / remote gauge → MCP expander (≈163 °/s, fine for gradual gauges like APN-153 DRIFT). The expander is a *reach* tool, not a speed tool.

**12-inch remote I²C bus.** At ~12" the bus capacitance (cable + device pins, ~150–250 pF) limits speed:

- **400 kHz** needs SCL rise < 300 ns → use **~1.5 kΩ pull-ups** (sink ~2.2 mA, within MCP23017 / STM32 limits). 4.7 kΩ at that capacitance rises in ~1 µs and **fails** 400 kHz.
- **100 kHz** tolerates **4.7 kΩ** at 12" (1 µs rise is within spec) — reliable but slower.
- Or an **active I²C buffer** (P82B715 / PCA9600 / LTC4311) to hold 400 kHz over 12–18".
- Verify on a scope (SCL rise time) with the **fully populated** bus (MCP + OLED + ADS) for realistic capacitance.

## Shift-Register I/O — 74HC165 / 74HC595 (ShiftBus)

The SPI shift-register backend (#197/#133, bench-decided 2026-07-02; firmware
`ShiftBus` — TechSpec `Firmware/ScratchPad/TechSpec/PanelGroup/Helpers/ShiftBus.md`).
One shared SPI bus per node: a '165 chain (inputs, MISO) + a '595 chain (outputs, MOSI)
on one SCK, coordinated by full-duplex full-frame transfers bounded by the LOAD ('165
SH/LD̄) and LATCH ('595 STCP) strobes.

### Interface-class selection (which backend a panel gets)

The standard lives at the **connector, not the chip**: sub-panels are I²C-class or
SPI-class devices, chosen by physics:

| Panel profile | Backend | Basis (bench, #197 gates) |
|---|---|---|
| Rotary encoders, any count | **SPI-class** ('165 + `SHIFTBUS_ISR_HZ=1000`) | loop-poll captured ~34 % of fast-spin detents under a 25 ms loop stall; 1 kHz ISR captured 100 % |
| Fast gauges (≳150 °/s slew demand) | **SPI-class** ('595 → DRV8833) | '595 path measured 1,137 steps/s sweep-avg (motor-limited) vs 490 on MCP@400 kHz (bus-limited) |
| Mixed I/O + steppers | SPI-class only if a row above applies | slow needles (≈163 °/s on MCP) are fine on I²C-class |
| Switches / lamps / slow needle / OLED | **I²C-class** (MCP23017 / direct) | no fidelity or speed pressure; MCP stays fully supported |

An I²C-class panel with same-address devices (multiple 0x3C OLEDs) muxes them behind a
**panel-local TCA9548A**; same-address devices may never sit on a trunk that also carries
them behind a mux (address shadowing while a channel is open).

### Design rules

| Rule | Detail |
|---|---|
| **'165 input bias — bussed 10 k array on ALL 8 inputs, every chip** | Common pin → 3V3, used or not. Zero static cost on unpopulated inputs, uniform layout, and every spare stays wire-and-go (no respin for a hard-grounded spare). Switch/encoder commons → GND (active-low). |
| **'595 output drive** | ≤4 mA indicator LED → direct drive + series R (push-pull, ~6 mA/pin recommended, 70 mA/chip total). >6 mA, any 5 V/12 V rail load, or chip total nearing 70 mA → 2N7002 + 100 k gate pulldown. DRV8833 inputs are µA logic — never count against the budget. |
| **DRV8833 VM ≤ 10.8 V — steppers NEVER on 12 V** | Absolute maximum. Stepper supply = 5 V (bench-validated). Servos = 12 V + panel-local buck (never a 5 V rail). |
| **SPI bus is dedicated** | The '165 QH output never tristates — MISO cannot be shared with any other SPI reader. Chains daisy without limit; capacity never forces a second bus. |
| **Standard pins** | SCK=PB3 · MISO=PB4 · MOSI=PB5 (SPI1-remap; firmware releases JTAG, SWD unaffected) · LOAD=PB8 · LATCH=PB9. With I2C1 that is one contiguous header run PB9..PB3. **I²C interrupts:** I2C1 INT_A/INT_B on **PB12/PB13**, I2C2 INT_A/INT_B on **PA8/PA15** (PanelGroup base 0.2.0). Pick INT pins whose EXTI line (the pin *number*, shared across ports) is not already an interrupt elsewhere. |
| **Remote legs** | 33 Ω series on SCK/LOAD/LATCH; ~1 MHz SPI tolerates ~12" harness. |

### Chip placement (guidance, per-controller call at B2)

- *Hot-swappable / serviceable peripherals* (gauge clusters): chips on the **hub board**,
  star wiring — unplugging a peripheral leaves the chain intact, inputs held by their bias.
- *Fixed remote sub-panels* (ARC-51-style): chips on the **sub-panel**, bus wiring via the
  J_SR leg.
- Chips-on-peripheral chains break when a link is unplugged (downstream latches noise) —
  fine for planned reconfiguration, wrong for casual unplugging.

### Co-residency note (bench-simulated, #197)

A blocked loop stalls same-node stepper slews **regardless of coil backend** (step timing
runs in `update()`): a simulated 25 ms display flush stretched a slew +35 % with visible
jitter. Real-flush arithmetic: 128×64 OLED ≈ 23 ms @400 kHz, ≈90 ms @100 kHz. Weigh
OLED + fast-gauge co-residency at grouping time; slow rare slews (APN-153 DRIFT) are
accepted. Real measurement lands with E2E (#137).

## Screws

| Screw | Use |
|---|---|
| M2 | PCB mounts, small standoffs |
| M3 | Placards, light rings, small brackets |
| M4 | Instrument bezels, gauge mounts — clearance Ø4.3–4.5 mm |
| M5 | Panel-to-subpanel, corner mounts — clearance Ø5.3–5.5 mm |

## Connectors

| Series | Pitch | Use | Tooling |
|---|---|---|---|
| Molex Mini-Fit Jr | 4.2 mm | Main bus (CAN + power between controller groups) **and** LED power connectors on all boards | JRready ST6490-ACT |
| JST-XH | 2.54 mm | Signal/logic harnesses — MCU ↔ breakout (I²C, interrupts, analog) and switch wiring | Engineer PA-09 |

**Minimum pitch: 2.54 mm.** Nothing smaller is used anywhere in the build.
**Two families only — no new connector families / crimp toolsets are ever introduced**
(Micro-Fit et al. rejected on tooling grounds).

### Harness interface classes (the connector IS the standard)

Every **inter-board harness** belongs to one class; unique pin count per family =
mechanical mis-mate protection **among interface-class connectors** (generic intra-panel
switch harnesses are excluded from the guarantee — they stay on 4/6-pin JST-XH, leaving
7/8-pin reserved for the interface legs; both ends of a switch harness live on one
assembly, so location disambiguates them). **Wires are not color-coded — pin position is the only identification**;
build-time reference = the connector diagrams on the published Connector & Harness Guide.
Pinouts below are the fabbed 0.1.0 truth (J_BUS / J_BL / J_I2C), the 0.2.0 design truth
(`J_SR` — pin order and footprint verified against the JST B7B-XH-A drawing, boards not yet
fabricated), or the adopted proposal (dual-BL).

| Class | Pins | Pinout | Family |
|---|---|---|---|
| CAN trunk + power (`J_BUS_IN/OUT`, hosts only, daisy) | 8 (2×4) | 1,2=+12V · 3=+5V · 4,7,8=GND · 5=CANH · 6=CANL | Mini-Fit Jr |
| Backlight single-zone (`J_BL`) | 2 (1×2) | 1=+12V · 2=SW_RETURN | Mini-Fit Jr |
| Backlight dual-zone + utility 5 V (gauge panels) | 4 (2×2) | 1=BL1_RET · 2=+12V · 3=BL2_RET · 4=+5V | Mini-Fit Jr |
| I²C leg (`J_I2C1/2`) | 8 | 1=SDA · 2=SCL · 3,4=GND · 5=+3V3 · 6=INT_A · 7=INT_B · **8=flex** (+5V / analog / spare) — **1–5 fixed, 6–8 repurposable per panel** (swap-in-place) | JST-XH |
| SPI leg (`J_SR`, end-of-chain, one per host chain) | 7 | 1=SCK · 2=MOSI · 3=MISO · 4=GND · 5=+3V3 · 6=LOAD · 7=LATCH | JST-XH |

- **Backlight pin-1 convention differs by connector type** (matches the fabbed boards): single-zone `J_BL` = **+12V on pin 1** (per PanelGroup_Base `J_BL1/2`); the 2×2 dual-zone = **RET on pin 1**. Not interchangeable — keep the two keyed/labeled distinct so a cable can't cross-plug.
- **Layer scope:** trunk terminates at host boards only; a sub-panel's full interface =
  one signal leg + a backlight cable. Hosts may carry multiple parallel connectors of a
  class (several `J_BL` on a zone, several `J_I2C` on a bus) — sized at B2. Exception:
  SPI chains are series — one end-node leg per host chain (chain-through connectors =
  future class, specified with the first gauge-cluster controller).
- **Dual-zone rule:** gauge-bearing panels carry two dimming zones (legend + instrument,
  the aircraft's dimmer split). Utility +5 V on that cable = small loads only (≲50 mA,
  return via the signal-cable GND); **servos never** — 12 V + panel-local buck.
- **SPI chain-role principle (adopted):** connector classes map to chain roles
  (chain-through vs end-node), not device types; one host chain composes them freely.

**Wire gauge:** 16–18 AWG silicone on the **main bus** (power + CAN daisy-chain); 24 AWG on
signal/logic harnesses (I²C, interrupts, switches). Match the Mini-Fit Jr crimp terminal to the
bus wire: 18 AWG → standard 5556 (18–24 AWG); 16 AWG → HCS / 16 AWG-rated terminal (5556 won't crimp 16 AWG).

### Molex Mini-Fit Jr (main bus + LED power)

- **PCB footprint:** Through-hole, single-row vertical for LED connectors (1×2); dual-row vertical for main bus
- Main bus: CAN bus signals and power distribution between controller groups
- LED power: 2-pin (1×2) per lighting zone on every MCU and breakout board — carries `+12V_BACKLIGHT` and `BACKLIGHT_SW_RETURN`
- Polarized housing — one insertion orientation only
- Rated up to **9 A/pin** (gauge/terminal-dependent; derate when all pins energized). Power split across pins (2×+12V, 3×GND) gives large margin over the ~2.3 A system load — current is never the limit, pour continuity at the pads is

**Main bus connector: 2×4 (8-pin), `Connector_Molex:Molex_Mini-Fit_Jr_5566-08A2_2x04_P4.20mm_Vertical`** (5566 = vertical PCB header; 5557 is the mating wire-side receptacle housing)

Two identical connectors per MCU board (J_BUS_IN + J_BUS_OUT) — same nets, bus passes through.

| Pin | Signal | Notes |
|---|---|---|
| 1 | +12V | Always-on 12V from PSU |
| 2 | +12V | Parallel — reduces connector resistance for LED backlight current |
| 3 | +5V | From PSU — 3.3V generated locally via AMS1117 |
| 4 | GND | |
| 5 | CANH | Differential pair with pin 6 |
| 6 | CANL | Differential pair with pin 5 |
| 7 | GND | |
| 8 | GND | |

Pins 1/2 both connect to +12V net. Pins 4/7/8 all connect to GND plane. CANH/CANL on pins 5/6 (same row) for clean differential pair routing.

#### Mini-Fit Jr — ordering parts (internal)

Spec is genuine **Molex**: `5566` header, `5557` cable housing, `5556` terminal (18–24 AWG).
The fleet *buys* chxunda's XD clones of the same series — they mate the genuine parts and
share the pin geometry, but a substitute is not automatically equivalent.

| Role | Spec (Molex) | Fleet part | LCSC |
|---|---|---|---|
| Board header 2×4 (`J_BUS_IN`/`J_BUS_OUT`) | 5566, 8 circuit, THT vertical | `XD-5566-2*4A` | `C20608116` |
| Board header 2×2 (dual-zone backlight) | 5566, 4 circuit | `XD-5566-2*2A` | `C20608114` |
| Board header 2×1 (`J_BL`) | 5566, 2 circuit | `XD-5566-2*1A` | `C20608113` |
| Cable housing 2×4 | 5557, 8 circuit | `XD-5557-2*4Y` | `C19193339` |
| Cable housing 2×2 | 5557, 4 circuit | `XD-5557-2*2Y` | `C19193337` |
| Cable housing 2×1 | 5557, 2 circuit | `XD-5557-2*1Y` | `C19193336` |
| Crimp terminal, female | **5556, 18–24 AWG** | `XD-5557-T` (**20–28 AWG**) | `C19193346` |

**Known deviation — crimp terminal gauge.** The spec is 18–24 AWG, which covers the 18 AWG
trunk. The `XD-5557-T` we stock is **20–28 AWG** and will not accept 18 AWG. Either fit a
genuine 5556 on the trunk, or build that harness in 20 AWG. Check the datasheet of the
terminal actually in hand before crimping.

Cable-side parts sit on no PCB BOM, so a BOM-driven shortfall cannot see them — the same
blind spot that let `CONN-XHP-7P` reach zero unnoticed. Count them by hand when ordering.

### JST-XH (intra-group harnesses + switch wiring)

- **PCB footprint:** Through-hole, single-row, vertical
- **Standard sizes:** 4-pin, 6-pin for generic intra-panel switch harnesses; **7-pin and
  8-pin are reserved for the interface-class legs** (J_SR = 7, J_I2C = 8) so a generic
  harness can never mate an interface socket. Choose by pin count, leave no pins empty.
- Rated 3A per pin — sufficient for 12V LED lines and all signal/power within a controller group
- **J_I2C pin order is fixed fleet-wide (swap-in-place):** `1 SDA · 2 SCL · 3 GND · 4 GND · 5 +3V3 · 6 INT_A · 7 INT_B · 8 [+5V or analog]`. Per panel, **swap only the unused pin in place, never reorder** — every J_I2C crimp map stays identical. **Pin 8 is the flex slot:** `+5V` for a board that needs it (e.g. a stepper's DRV8833 VM), `analog` (pot/ladder wiper) for one that doesn't. A single-MCP panel can **wire-OR INTA/INTB** (IOCON MIRROR + open-drain) → one INT on pin 6, freeing pin 7 for a 2nd analog. Series R on the leg: 33Ω on SDA/SCL, 100Ω on INT.
- Polarized housing — one insertion orientation only
- Switches share a common GND within each connector group; one GND pin per connector

Standard intra-group signal harness (6-pin JST-XH):

| Pin | Signal |
|---|---|
| 1 | SDA |
| 2 | SCL |
| 3 | GND |
| 4 | GND |
| 5 | 3.3 V (chip power) |
| 6 | spare |

Breakout boards with analog outputs or interrupts use an 8-pin variant with additional signals on pins 6–8.

LED power is carried on a **separate 2-pin Mini-Fit Jr connector** (not the signal harness):

| Pin | Signal |
|---|---|
| 1 | +12V_BACKLIGHT (always-on 12V supply to LED string tops) |
| 2 | BACKLIGHT_SW_RETURN (MOSFET drain — near GND when LEDs on) |

## Silkscreen

Checked on every board **before gerber export** — a silk error is only discoverable after fab,
and a mislabelled power connector destroys hardware.

### Connector pin labels

Every connector gets a label per pin, naming the **signal**, placed beside its own pad:

- **Power and bus connectors are mandatory.** `12V`, `5V`, `CANH`, `CANL`, `GND` on the Mini-Fit
  Jr bus connectors. These are unkeyed in practice and often sit side by side, so a reversed
  harness is a destroyed board — this is the one place silk is a safety feature, not a courtesy.
- **Label the signal, not the net.** A pin whose net is auto-named because it passes through a
  series resistor (`Net-(J2-Pin_1)`) is labelled by what it *is* — trace through the resistor and
  use `SDA`, not the generated name.
- **Match the connector's own function.** A UART debug header is `RX` / `TX` / `GND`, never an
  I²C label set copied from a neighbouring connector.
- Off-board-facing headers (I²C, ShiftBus, SWD, diagnostics) get the same treatment.

### Function legends — free text, never the Value field

A jumper or block legend (`CAN TERM`, `POWER`, `PANEL`, `STATUS`) is a **free silk text item**.

**Do not create one by overriding the footprint's `Value` field on the board.** It looks
identical on the rendered silk and is wrong twice over: it raises a `footprint_symbol_mismatch`
schematic-parity error, and the next *Update PCB from Schematic* resets the field and silently
deletes the legend. It also pollutes the BOM's Value column with a legend string instead of the
part's value.

### Revision text

Back silk, uppercase, one line:

```
REVISION <x.y.z> | <BOARD NAME>
```

`layer B.SilkS` · `size 1 x 1` · `thickness 0.15` · `justify left bottom mirror` · `rotation 0`

**Write a board revision as `0.2.0` everywhere** — silkscreen, InvenTree, BOM, docs and commit messages. It is the identifier a reader matches against the board in their hand. "Rev 2" is acceptable only for a *round of work* ("the Rev 2 order", "Rev 1 bench checks"), never to identify hardware.

**Bump it in the same change that bumps the board revision.** A board fabbed carrying the
previous revision's text is indistinguishable from the older batch on the bench.

### The gate

Before exporting gerbers, confirm:

1. ERC 0, DRC 0 violations, 0 unconnected, **0 schematic parity**
2. Every connector pin has its signal label within a few mm of the pad
3. Revision text present, correct revision, correct format and stroke
4. No legend implemented via a footprint `Value` override

## Releases

A hardware release means **the boards in it are ready** — built, brought up, and verified. It
works like a firmware release: **merging the release PR is the release**. Tags are created only
for releases, by release-please — never by hand, never per board. The model and its reasons are
design decision D10 ([Design Decisions](../architecture/design-decisions.md)).

### How it works

- release-please watches **commits under `PCB/`** and keeps a draft **`release hardware X.Y.Z`**
  pull request up to date: the next version, `PCB/CHANGELOG.md`, and `release:` in
  `PCB/manifest.yaml`. A commit that also touches `Firmware/` counts for both releases.
- The commit **type** decides the effect: `feat` → Features, `fix` → Bug Fixes, **`!`** → ⚠ Breaking
  changes. Mark a hardware break with `!` — a connector pinout, harness, mounting, or minimum-firmware
  change, e.g. `feat(pcb)!: move CAN to pins 3/4`. `docs`, `chore`, `ci`, `test` neither appear nor
  bump. Before 1.0 a break bumps the minor version, anything else the patch.
- Merging the release PR tags **`hardware-vX.Y.Z`** and publishes the GitHub Release. A follow-up job
  adds the **boards**: minimum firmware, a table of every board (new / unchanged / moved since the
  previous release), and per board its order ID, errata, the commit it was made from, and what
  changed in it.
- In-progress boards' commits appear in the changelog too; the board table says what is released.

### The manifest — `PCB/manifest.yaml`

Lists the boards a release contains. release-please owns `release:`; the rest is edited by hand.
A board is listed **only once bring-up passes**:

```yaml
min_firmware: firmware-v0.1.0
boards:
  - board: PanelGroup_Base            # KiCad project folder name
    path: PCB/Base/PanelGroup_Base
    version: 0.2.0                    # matches its title block at `fabricated`
    fabricated: a4e75ff9              # commit the boards were made from
    order: JLC W2026093021050394
    errata: ""                        # rework needed to pass bring-up, if any
```

- **`fabricated`** is the commit whose files were sent to fab; the board's title-block revision there
  must equal `version`, or the notes job fails. If the design has moved on since, the notes say so
  and point to `fabricated` for this revision's files.
- **Passed only with rework** (a cut trace, a bodge wire): list it anyway and describe the rework in
  `errata`. The next revision folds the fix in.
- A revision that fails bring-up is never listed — the next revision supersedes it.

### Board status

Every board folder carries a short `README.md` stating its status: **Released**, **In progress**, or
**Deprecated**. A release captures the whole repository, in-progress boards included, so the README
is how a reader browsing a release tells them apart; the manifest is the authoritative list of what a
release contains. Name the status only, never a version — the README then changes only when the
status does.

### Release checklist

1. Bring-up passes for every board going into the release.
2. One PR: list the boards in `PCB/manifest.yaml` (and set `min_firmware`), flip their READMEs to
   **Released**. Preview the notes with `python tools/hardware-release/release_notes.py --preview`.
   Merge it.
3. On the draft **`release hardware X.Y.Z`** PR: mark it ready, check the version and changelog,
   merge it. The release publishes itself; the board table follows a minute later.
4. Check the release notes, and that **Latest** still points at the firmware release.
5. **After the first hardware release only:** remove `"release-as": "0.1.0"` from the `PCB` package in
   `release-please-config.json`, or every later release stays at 0.1.0.

## Switches & Controls

- Toggle switches: 12 mm (standard), ~6 mm (ECM modules)

### Rotary switches (multi-position selectors)

- Three standard variants, distinguished by **detent angle**: **12-position (30°)**, **8-position (45°)**,
  **6-position (60°)** — positions in 360° = 360° ÷ angle. Pick the variant whose detent angle matches
  the real selector.
- Use **fewer positions** than the variant's max where needed, and limit travel with a **CAD turn-limiter
  in the bezel** (preferred — repeatable across prints) rather than the switch's adjustable stop washer.
  Example: a 5-position selector at 30° detent = the **12-position variant, CAD-limited to 5** (≈120° throw).
- Wire as `SwitchMultiPos`: **one GPIO per used position**, common → **GND** (MCP23017 or STM32 breakout).
  Prefer this over a resistor-ladder (`AnalogMultiPos`) when GPIO is plentiful — no ladder tolerance or
  ADC-threshold calibration; reserve the ladder for when GPIO/ADC-routing is tight.
- **Selector vs encoder is decided by whether the knob has a marked position**, not by its count. A
  selector with a pointer reports its absolute position, so the sim syncs to it at startup:
  `SwitchMultiPos` up to 12 positions, a resistor-ladder **`AnalogMultiPos`** on one analog pin above
  that. A knob with no marked position can only report up/down steps — nothing to sync at startup —
  so it uses a **`RotaryEncoder`** (DIR mode).
- **Resistor-ladder wiring (`AnalogMultiPos`):** equal **1 kΩ 1 %** resistors between adjacent position
  contacts, ladder ends to 3V3 and GND, wiper (common) to one analog pin, plus a **100 nF** capacitor
  from that pin to GND — the wiper connects nothing for an instant between detents, and the cap holds
  the reading steady across the gap (the base board has no ADC filter).

### Rotary encoders (EC11 / bare quadrature)

- A and B → two GPIO, each with a **10 kΩ pull-up to 3V3**. The `RotaryEncoder` class sets a plain
  `INPUT` (no internal pull-up), so an open contact floats without the external resistor. Common → GND.
- The integral push-switch on a 5-pin EC11 is a separate SPST — wire it as its own `Switch2Pos`, or
  leave the two switch pins unconnected if out of scope.
- Reverse the sensed direction by swapping the A/B pins — no firmware change.

### Potentiometers (analog)

- A pot is already a divider: wiper → an **ADC pin**, the two ends → `+3V3` and `GND`. No added
  resistors.
- **High end → 3V3, never 5 V.** The STM32F103 ADC pins (PA0–PA7, PB0, PB1) are **not 5 V-tolerant**;
  5 V damages them. Reverse the travel by swapping the end terminals.

### Freeing the JTAG pins for breakout GPIO

`PA15` (JTDI), `PB3` (JTDO), `PB4` (NJTRST) power up as the JTAG-DP. On the **PanelGroup base** they
are exposed as breakout pins. `STM32Board::begin()` remaps SWJ to SWD-only at boot (#299), so they
are ordinary GPIO with no sketch code; SWD (PA13/PA14) stays live and ST-Link still flashes.

The Gateway/Bridge base leaves these NC — it has enough clean breakout pins not to bother (see
[base boards](base-boards.md)).

## CAN Transceiver

**Selected: SN65HVD230** — SOIC-8, 3.3V logic.

- One per MCU board; connects STM32F103 CAN controller (PA11/PA12) to the physical bus
- Runs directly from 3.3V rail — no level shifter required
- CANH/CANL route to Molex Mini-Fit Jr main bus connector
- **Bus termination:** 120Ω resistor across CANH/CANL on each end node; omit on intermediate nodes
- Compatible 3.3V clones (e.g. VP230) acceptable for JLCPCB assembly

## LED Backlighting

**Architecture: 5-LED series strings, MOSFET-switched per zone, resistor current limiting.**

Confirmed from bench testing. Estimated ~500 LEDs total across full cockpit (~100 strings of 5).

### String design

- 5 × 5050 SMD red LEDs in series per string
- Measured Vf: 1.95–2.1 V per LED → ~10 V total per string at 12 V supply → ~2 V headroom for resistor
- One current-limiting resistor per string (back face of PCB)

### Resistor values (bench-tested)

| Resistor | Measured current | Use |
|---|---|---|
| 47Ω | 34–42 mA | **Rejected** — resistor overheated |
| 100Ω | 19–23 mA | Bright panels / gauges |
| 120Ω | ~17–20 mA | **Balanced default** |
| 150Ω | 14–17 mA | Standard |
| 180Ω | ~11–13 mA | Low brightness / night-friendly |
| 200Ω | 10–12 mA | Dimmest |

**Default: 120Ω.** Choose at assembly time per zone; 100Ω for bright panels, 180Ω for dimmer zones.

**Resistor package:** 0805 minimum, 1206 preferred where board space allows. Dissipation ≈ 39 mW at 120Ω/18 mA — either package is thermally fine; 1206 is easier to hand-solder and rework.

### Zone dimming (MOSFET)

- One **AO3400A** N-channel MOSFET per panel/lighting zone (SOT-23, **30V**, 5.7A, Vgs(th) 0.65–1.45V) — **low-side switch**. **AO3400A (30V) is required over IRLML2502 (20V):** the LED strings run on the **12V rail**, whose **SMBJ12A TVS clamps at 19.9V** on a hot-plug transient — the FET drain sees that clamp, and 19.9V is far too close to IRLML2502's 20V V(DS)max. The 30V AO3400A gives proper margin; 3.3V PWM still fully drives it for the sub-amp backlight load.
- Gate driven directly by STM32 3.3V PWM — no gate driver required (Vgs = 3.3V, well within ±12V Vgs(max))
- Drain → BACKLIGHT_SW_RETURN (Mini-Fit Jr pin 2); source → GND
- LED strings: +12V_BACKLIGHT (Mini-Fit Jr pin 1) → resistor → 5× LEDs → BACKLIGHT_SW_RETURN
- Resistors set per-string current at full on; PWM duty cycle controls average brightness across the zone

### Other

- Placement: LEDs on PCB front face; resistors, MOSFETs, and all other components on back face
- PCB trace width: 0.3 mm minimum for LED string feeds
- 5-LED strings preferred over 3-LED: fewer parallel paths, lower wiring current (1.8A total at 120Ω vs ~3A for 3-LED strings across same ~500 LEDs)

## Gauges

- LOX gauge: 2-5/8″ (~67 mm total)
- Radar Altimeter gauge: 3-1/8″ (~100 mm with bezel)
- Cabin Pressure gauge: driven by X27.589 Switec stepper (shaft-through-PCB mount)

---

## Component Pin Assignment Rules

Hard design rules that apply at schematic capture time. These are not layout preferences —
violating them causes functional failures that cannot be fixed after fabrication.

| Chip | Affected pins | Rule | Reason |
|---|---|---|---|
| MCP23017 | GPA7, GPB7 | **Output only — never configure as inputs** | Silicon bug confirmed by Microchip (datasheet Rev D, June 2022): SDA signal is corrupted if pin voltage changes during an I2C bit transmission, causing bus malfunction. The IODIR register physically allows input mode but it is unsafe. |
| 74HC165 | all 8 D inputs | **Bussed 10 k array to 3V3 on all 8, used or not** | CMOS inputs float otherwise (noise, oscillation, phantom reads); array costs nothing on unpopulated inputs and keeps spares wire-and-go. |
| 74HC165/595 | VCC | **3V3 only when signaled by a 3V3 host** | Plain 74HC at VCC=5 V sets VIH=3.5 V — above the STM32's 3.3 V drive (marginal, lot/temperature-dependent). Remote modules without 3V3: local SOT-23 LDO from 5 V. |
| DRV8833 | VM | **≤ 10.8 V absolute — never the 12 V rail** | Datasheet absolute maximum; stepper supply is 5 V (bench-validated). |

**MCP23017 input capacity: 14 pins per chip** (GPA0–GPA6 + GPB0–GPB6).  
GPA7 and GPB7 may drive LEDs, enables, or any other output load without restriction.  
Source: Microchip support article *"GPA7 & GPB7 Cannot Be Used as Inputs In MCP23017"*

**Firmware consequence — GPINTEN must exclude bit 7 on both ports.**
`chip.interrupt(port, CHANGE)` (blemasle library) enables GPINTEN for all 8 bits. Do not use it directly. Instead, read IODIR after `configure()` and write it masked (`& 0x7F`) to GPINTEN:
```cpp
uint8_t gpintenA = chip.readRegister(MCP23017Register::IODIR_A) & 0x7Fu;
uint8_t gpintenB = chip.readRegister(MCP23017Register::IODIR_B) & 0x7Fu;
chip.writeRegister(MCP23017Register::GPINTEN_A, gpintenA);
chip.writeRegister(MCP23017Register::GPINTEN_B, gpintenB);
```
This also ensures interrupts are never enabled on output pins — redundant per datasheet (output pins cannot fire GPINTEN), but explicit.

---

## Standard Circuit Blocks (Design Library)

These subcircuits repeat on every MCU board and are candidates for KiCad hierarchical sheet templates (`PCB/Libraries/sheets/`).

### LED Zone Switch (per lighting zone)

```
+12V_BACKLIGHT ── R (120 Ω) ──┬── LED1 A
                               └── LED2 A  (one resistor per string, each string 5 LEDs in series)
                                   ...
                               LED_n K → BACKLIGHT_SW_RETURN
                                              │
                                        AO3400A drain
                                        AO3400A source → GND
                                        AO3400A gate ← STM32 PWM (3.3V direct)
```

- Default off (gate at 0V, Vgs = 0V → MOSFET off)
- STM32 HIGH (3.3V) → Vgs = 3.3V → N-ch fully enhanced → BACKLIGHT_SW_RETURN pulled to GND → LED strings conduct
- STM32 LOW → Vgs = 0V → MOSFET off → no current path → LEDs off
- No gate pull-up or driver required: AO3400A Vgs(th) = 0.65–1.45V (on by ~2.5V); 3.3V is well within Vgs(max) = ±12V
- LED power arrives on a **separate 2-pin Mini-Fit Jr connector** — not the signal harness

### MCP23017 Instance

**Selected: MCP23017-E/SS (Microchip)** — 16-bit I/O expander, SSOP-28. **LCSC: C506653**

> **Silicon bug — GPA7 and GPB7 must not be used as inputs.**  
> Confirmed by Microchip in datasheet Revision D (June 2022) and support article
> "GPA7 & GPB7 Cannot Be Used as Inputs In MCP23017": the SDA signal can be corrupted
> if the pin voltage changes during an I2C bit transmission, potentially causing bus host
> malfunction. The register bits allow direction to be changed to input, but doing so is
> unsafe. **Route switches and other inputs to GPA0–GPA6 and GPB0–GPB6 only (14 input
> pins per chip). GPA7 and GPB7 may be used as outputs (LEDs, enables, etc.).**

Per chip on each MCU board:

| Component | Value | Notes |
|---|---|---|
| C_decoupling | 100 nF, 0805 | VDD → GND, placed adjacent to chip |
| C_bulk | 10 µF, 0805 | VDD → GND, one per board |
| R_RESET | 10 kΩ, 1206 | RESET → +3V3 pull-up |
| R_A1 (if addr bit = HIGH) | 10 kΩ, 1206 | Address pin → +3V3 |
| R_SDA, R_SCL | 33 Ω, 0805 | Series on SDA/SCL between harness and chip — damps ringing on off-board wiring |
| R_INTA, R_INTB | 100 Ω, 0805 | Series on interrupt outputs before harness connector — ESD/transient protection |

I2C pull-ups (4.7 kΩ) placed **on MCU board only** — one set per bus, not on breakout boards.

Switch inputs are active-low by project convention: the net is held HIGH and the switch
closes to GND. Prefer a 10 kΩ external pull-up to +3V3 on the board that owns the switch
net. MCP23017 GPPU pull-ups are weak (~100 kΩ) and available only in the pull-up direction;
do not use them as the standard bias for OpenSkyhawk switch nets unless a specific schematic
intentionally documents that choice.

### ADC Input Filter (per analog input)

Placed on MCU board, close to STM32 ADC pin:

```
pot wiper (via harness) → 1 kΩ → STM32 ADC pin → 100 nF → GND
```

- 1 kΩ: protects ADC pin during faults/transients, forms RC with 100 nF
- 100 nF: low-pass filter, reduces noise/jitter on ADC reading
- RC corner frequency: ~1.6 kHz — well above polling rate, no signal distortion

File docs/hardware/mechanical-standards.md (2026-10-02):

# Mechanical Standards

The mechanical conventions for panels and mounts. Some of this is settled (screws, gauge sizes);
panel-level dimensions are still being worked out and are marked TBD — don't invent them.

## Screws

| Screw | Use | Clearance |
|---|-----|---|
| M2 | PCB mounts, small standoffs | — |
| M3 | Placards, light rings, small brackets | — |
| M4 | Instrument bezels, gauge mounts | Ø4.3–4.5 mm |
| M5 | Panel-to-subpanel, corner mounts | Ø5.3–5.5 mm |

## Gauges

| Gauge | Size | Drive |
|---|---|---|
| LOX gauge | 2-5/8″ (~67 mm) | — |
| Radar altimeter | 3-1/8″ (~100 mm with bezel) | — |
| Cabin pressure | — | X27.589 Switec stepper, shaft-through-PCB mount |

## Switches & controls

- Toggle switches: **12 mm** standard; **~6 mm** on the ECM modules.

## Panel dimensions, cutouts, bezels, light rings

### Dzus rail mounting — MIL-F-25173A

Left/right console panels mount on standard **Dzus rails** (MIL-F-25173A — see
[`docs/References/`](../References/index.md)). The width and mounting pattern are now settled:

| Dimension | Value |
|---|---|
| **Panel width** — global default for L/R console panels | **146.05 mm** (5¾″) |
| **Mounting-stud centers**, left ↔ right | **136.525 mm** (5⅜″) — 4.7625 mm (3⁄16″) inboard of each edge |
| **Vertical fastener pitch** (rail receptacle grid) | **9.525 mm** (3⁄8″); ≥ 2 studs/side |
| **Panel height** | N × 9.525 mm ("Dzus units"), per panel |
| **Stud rows**, from the panel's own top edge | outermost at **1.5 × pitch**; every row at a **half-integer** multiple |
| **Panel thickness** | 1.59 mm (1⁄16″) aluminum |

Work from the exact inch fractions, not the rounded millimetres: the inset is exactly half a
pitch, so the stud span is `panel width − pitch` = 146.05 − 9.525 = **136.525 mm**. Rounding the
inset to 4.76 does not close against a 146.05 panel.

### Where the stud rows go

The outermost stud sits **1.5 pitch units** from each end of the panel (`e = 1.5`) — the
convention these panels are built to, verified against the A-4's Doppler panel, which has an
independent height. So a panel of N units carries its outer studs `(N − 3) × 9.525 mm` apart.

Because `e` is a half-integer and panel heights are whole units, **every stud in a stack lands at
`(k + 0.5) × 9.525 mm` from the top of the stack**. Any additional row must therefore also be at a
half-integer position (2.5, 4.5, 6.5 …); a row at a whole unit misses the rail by half a pitch.
Across a joint the spacing is always `(N − 1.5) → (N + 1.5)` = **3 pitch = 28.575 mm**, whatever
the two panels' heights, and panels butt with no gap.

Worked example — a 6-unit panel (57.15 mm): rows at 1.5 and 4.5, i.e. **14.2875** and
**42.8625 mm** from the top edge, both rails at x = **4.7625** and **141.2875 mm**. That is the
`136.525 × 28.575 mm` pattern the APN-153 panel uses.

**Fastener** — quarter-turn stud + receptacle strip:

- **Stud:** head Ø **.375″ (9.53 mm)** · body Ø **.257″ (6.53 mm)** · panel hole **~.26″ (6.6 mm)** ·
  .050″ screwdriver slot · 1⁄16″-panel grip · quarter-turn lock (85–135°). Detail design per
  MIL-F-25173A Fig 2 — **no single mandated stud P/N**; use any conforming quarter-turn stud
  (Dzus / Southco / Skybolt), chosen by head style + grip.
- **Receptacle strip (the rail):** Dzus **`PR 3½-L`** (or equal), cut to length · .051″ music-wire
  spring · aluminum · cadmium plated.

**Exceptions** (non-standard width — measured individually): throttle quadrant, lighting panel, and
any panel not on the standard Dzus rail.

### Per-panel cutouts / bezels / light rings

!!! note "TBD — driven by the CAD models"
    Switch/gauge cutout templates, bezel profiles, and light-ring geometry come from the
    Fusion/FreeCAD panel models, which are early-stage. These are documented per panel as they
    are modelled. CAD tooling is still under evaluation — see [CAD Workflow](cad-workflow.md).

## Board-level placement

Mechanical placement on the PCB itself — LEDs on the front face, everything else on the back,
through-hole connectors accessible from the panel side — is part of the
[PCB Design Rules](pcb-design-rules.md).

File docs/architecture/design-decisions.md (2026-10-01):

# Design Decisions

The OpenSkyhawk architecture is the way it is for concrete reasons — most of them learned
the hard way on the bench. This page records those decisions with their failure modes and
the data behind them, so they don't get re-litigated. If you're about to argue "why not just
use the STM32's USB directly?" or "why is auto-retransmission off?", the answer is here.

Each decision lists the call that was made and the reasoning. Where a decision came from a
specific bench test, the empirical data is included.

---

## D1 — SimGateway exists because STM32 USB can't take the load

**Decision:** A dedicated RP2040 (the **SimGateway**) owns the USB connection to the PC and
acts as a pure byte relay. PanelBridge (STM32) runs the DCS-BIOS library but never touches
USB at runtime.

**The original approach:** Drive USB CDC directly from the STM32 — one MCU, DCS-BIOS library
and USB on the same chip. Simpler on paper.

**The failure mode:** Under sustained DCS-BIOS traffic the STM32 native USB CDC stack
**overflowed and crashed**. The port became unusable until a physical replug (`socat` exits
with "Permission denied"; the device falls off the bus). This is not a tuning problem — the
STM32F103 USB peripheral cannot reliably carry the full-state DCS-BIOS stream.

**Why RP2040 solves it:** The RP2040 has a native USB stack that handles the 250 kbps
DCS-BIOS stream without issue, and — critically — it has **no shared-peripheral conflict**.
On the STM32F103, USB and CAN share pins PA11/PA12 and cannot both be active. Moving USB to a
separate RP2040 frees the STM32 to dedicate its CAN peripheral to the bus, and keeps the
DCS-BIOS processing on a chip that never runs USB.

**The tradeoff:** One extra board and one UART hop between SimGateway and PanelBridge. That
hop is cheap (see [D2](#d2-uart-not-usb-cdc-for-the-simgateway-panelbridge-link)) and worth
it for a USB path that doesn't fall over.

!!! warning "Do not revert this"
    "Just use the STM32's USB" is the single most likely thing a new contributor will
    propose. It was tried. It crashes under real load. The SimGateway is not incidental
    complexity — it's the fix.

---

## D2 — UART, not USB CDC, for the SimGateway ↔ PanelBridge link

**Decision:** SimGateway and PanelBridge talk over a plain hardware **UART at 250 kbps**,
not over a second USB link.

**Reasoning:** The hardware UART showed **no throughput bottleneck** at any tested DCS-BIOS
load. The failure in [D1](#d1-simgateway-exists-because-stm32-usb-cant-take-the-load) was
specifically the STM32's USB peripheral, not its serial throughput. A UART is simple,
deterministic, has no enumeration or driver surface, and lets SimGateway stay a dumb byte
relay: any byte ≤ 0x7F is forwarded straight to USB CDC; HID frames are tagged with
high-bit magic bytes so they're structurally impossible to confuse with DCS-BIOS ASCII.

---

## D3 — CAN bus, not I²C, between boards

**Decision:** Inter-board communication uses a **CAN bus at 500 kbps**, not I²C. (I²C is used
only *within* a panel group, from a PanelGroup node out to its local breakout boards.)

**Reasoning:** CAN is built for exactly this job — a multi-drop network of nodes spread across
a physical structure:

- **Deterministic, prioritised arbitration** — frames don't collide and corrupt; the bus
  arbitrates by ID.
- **Hardware error detection and fault confinement** — CRC, ACK, and automatic error
  counters built into the controller, with graceful degradation to Error Passive rather than
  a hard failure.
- **Long, daisy-chained cable runs** — a differential pair tolerates the distances and noise
  of a full cockpit; I²C does not.
- **True multi-node topology** — nodes drop on and off the same two wires without a hub.

I²C has none of these properties over cockpit-scale wiring. It stays where it belongs:
short hops from an STM32 to an MCP23017 or ADS1115 on the same panel group.

---

## D4 — AutoRetransmission = DISABLE (this one will catch you out)

**Decision:** The STM32 bxCAN peripheral is configured with **`AutoRetransmission = DISABLE`**
and **`AutoBusOff = ENABLE`**. Both are correctness requirements, not preferences.

**The failure mode if you leave AutoRetransmission on (the default):** A single frame that
goes unacknowledged — one node briefly offline, one noisy moment — is retried forever by the
hardware. That one stuck frame **occupies a TX mailbox and never releases it**. With all
three TX mailboxes jammed this way, the transmit path deadlocks: the software TX queue can
never drain, and the node drives itself straight to bus-off. The whole node goes dark over a
single missed ACK.

**With AutoRetransmission disabled:** A failed send increments the Transmit Error Counter by
8 and the frame is dropped (the software queue applies its own bounded retry policy — see
[D6](#d6-controlid-routing-one-format-split-at-the-gateway) and the
[CAN Bus Protocol](can-bus.md) page). At TEC = 128 the node enters **Error Passive** and
limps along — CAN's intended graceful degradation — then self-heals when the fault clears.
No deadlock, no manual recovery.

**Why AutoBusOff = ENABLE matters too:** When a node does hit bus-off, hardware
auto-recovery brings it back in **~3 ms** (after 1408 recessive bits). With it disabled,
firmware would have to detect bus-off and restart the controller by hand.

Both settings were validated in the 2026-05-20 prototype soak and fault-injection tests.

| Setting | Required value | Consequence if wrong |
|---|---|---|
| `AutoRetransmission` | **DISABLE** | One unACKed frame jams all 3 TX mailboxes → immediate bus-off; TX queue never drains |
| `AutoBusOff` | **ENABLE** | Hardware recovers in ~3 ms; with DISABLE firmware must restart the controller manually |

---

## D5 — SJW = 4TQ, empirically determined

**Decision:** CAN bit timing is **Prescaler = 4, BS1 = 13TQ, BS2 = 4TQ, SJW = 4TQ** at
500 kbps. The synchronization jump width (SJW) of **4TQ** is the non-obvious part.

**The failure mode:** At SJW = 1TQ, a two-node bus produced **intermittent CRC errors**. The
Transmit Error Counter climbed on both nodes within minutes of starting traffic. The root
cause is crystal-to-crystal frequency tolerance between Blue Pill clones — small enough to be
in spec, large enough to break CAN sampling when the jump width is too narrow to absorb it.
Raising SJW to 4TQ widens the resynchronization window and absorbs the skew.

**The data (2026-05-20, two-node bench test, SJW = 4TQ):**

| Metric | Value |
|---|---|
| Soak duration | 21 minutes |
| Packets injected | 1257 @ 1 pkt/sec |
| Average RTT | 1 ms |
| Min / Max RTT | 1 ms / 1 ms |
| Packets lost | 0 |
| TEC / REC | 0 / 0 |
| Bus-off events | 0 |

The errors at SJW = 1TQ cleared **immediately** when SJW was raised to 4TQ, with no other
change made.

**Design rule:** All production `platformio.ini` files set SJW = 4TQ; the `CANProtocol`
library initialises CAN this way. Keep it permanently — it costs nothing even on production
PCBs with specified crystals.

!!! note "External crystal is mandatory"
    The STM32F103's internal RC oscillator (HSI, ±1%) is **not** accurate enough for 500 kbps
    CAN. Every MCU board must use an external **8 MHz crystal**, and firmware must actively
    select it: `STM32Board`'s strong `SystemClock_Config` selects HSE → PLL ×9 → 72 MHz
    (APB1 36 MHz → CAN 500 kbps). `-DHSE_VALUE=8000000` in `build_flags` only *declares* the
    crystal frequency to HAL — it does **not** select HSE; without the `SystemClock_Config`
    override a node boots on the core-default HSI-PLL 64 MHz → APB1 32 MHz → CAN 444 kbps
    (issue #245). The crystal tolerance is the very skew SJW = 4TQ absorbs.

---

## D6 — controlId routing: one format, split at the gateway

**Decision:** Every control on the bus uses the same `ControlPacket` format. The
**`controlId` value alone determines the routing path**, with no extra lookup:

| controlId range | Type | Routed by |
|---|---|---|
| `0x0010`–`0x001F` | HID axes | SimGateway → HIDAxis |
| `0x0020`–`0x002F` | HID hat switches | SimGateway → HIDHatSwitch |
| `0x0030`–`0x00AF` | HID buttons | SimGateway → HIDButton |
| `0x00B0`–`0x00FF` | Reserved HID expansion | — |
| `0x8000`–`0x86FF` | DCS-BIOS compact command IDs | PanelBridge → `sendDcsBiosMessage()` |
| `0xFFFF` | Reserved / invalid sentinel | dropped |

Anything `< 0x8000` is HID and is handled entirely at the **SimGateway** layer — PanelBridge
never sees it. Anything in `0x8000`–`0x86FF` is a DCS-BIOS input routed by **PanelBridge**.
Reserved values such as `0xFFFF` are invalid for routing and must never reach the generated
input map.

**Why this design:** The A-4E-C mod has no axis exports — stick and rudder are HID-only — so
the two ranges never overlap, and a single numeric range check is enough to route any packet.
That keeps **PanelGroup nodes dumb**: a node just fires a `controlId` and doesn't care whether
it ends up as a DCS-BIOS command or a joystick axis. **All routing logic lives in one place.**
Add a control type and you change the gateway, not every node.

The practical guidance that falls out of this — when to use DCS-BIOS and when to use HID — is
on the [DCS-BIOS vs HID](dcsbios-vs-hid.md) page.

---

## D7 — STM32F103 for the CAN nodes

**Decision:** The CAN nodes — PanelBridge and every PanelGroup node — use the **STM32F103**
family (LQFP48, 20 KB RAM). The **STM32F103C8** (64 KB flash) is the default for every board;
the **STM32F103CB** (128 KB flash) is a drop-in fallback on the identical footprint, reserved
for any future build that ever exceeds 64 KB.
**PanelBridge** runs the DCS-BIOS library plus the full generated input map (~300 entries), yet
compiles to ~26 KB flash (~40% of the C8's 64 KB) — so it fits the STM32F103C8. PanelGroup
nodes carry only the `DCSIN_*` constants they use, so they fit easily too. No board currently
needs the CB.

**Reasoning:**

- **Native bxCAN peripheral** — CAN is the backbone of the whole system; a built-in
  controller means no external CAN MCU or SPI-CAN bridge.
- **3.3 V logic** — pairs directly with the SN65HVD230 transceiver, no level shifting.
- **Mature toolchain** — well supported under PlatformIO with the STM32duino Arduino-compatible
  framework, which the firmware is built on.
- **Right-sized and inspectable** — an LQFP48 package the project can hand-assemble and
  visually inspect after reflow.

**The one constraint to know:** USB and CAN share PA11/PA12 and **cannot run at the same
time**. That's exactly why USB lives on the separate RP2040 SimGateway
([D1](#d1-simgateway-exists-because-stm32-usb-cant-take-the-load)) — it lets the STM32
dedicate those pins to CAN. Each board also needs an external 8 MHz crystal for CAN timing
([D5](#d5-sjw-4tq-empirically-determined)).

---

## D8 — CAD tooling: Fusion 360 vs FreeCAD (pending)

**Decision:** *Pending.* Currently evaluating both tools. **FreeCAD** is preferred for
alignment with the open source nature of the project, and it has a KiCad StepUp plugin for a
direct PCB → CAD fit-check workflow. The decision will be documented here once finalised.

The file-management policy holds regardless of tool choice: CAD **source** files are committed
to the repo, while **STL/STEP exports** are gitignored and published via GitHub Releases.

---

## D9 — Sub-panel I/O: 74HC shift registers over SPI, chosen by physics

**Decision:** panels with rotary encoders or fast gauges use **74HC165/74HC595 shift-register
chains over SPI** (the `ShiftBus` backend); everything else may stay on **MCP23017/I²C**. The
standard lives at the **connector, not the chip**: a sub-panel is an *I²C-class* or *SPI-class*
device by its interface, and its internals are its own business.

Both backends were bench-raced (2026-07, issues #197/#133). The numbers made the call:

- **Encoder fidelity** is the disqualifier for I²C: with the loop blocked 25 ms per 100 ms
  (an OLED display flush), loop-rate polling captured only **~34 %** of fast-spin encoder
  detents. The shift-register chain sampled from a 1 kHz timer interrupt captured **100 %**,
  both directions — SPI reads are interrupt-safe in a way blocking I²C never is.
- **Stepper coil drive** through a '595 chain measured **1,137 steps/s** (motor-limited —
  the bus stopped being the bottleneck) vs ~490 steps/s through an MCP23017 at 400 kHz
  (bus-limited).
- Shift chains also scale differently: data is **regenerated at every chip**, so chain length
  doesn't accumulate bus capacitance the way I²C does, and unlimited chips ride one 5-pin bus.

The MCP23017 remains fully supported and is still the right choice for switch-and-lamp panels
that already sit on an I²C leg — no encoders, no speed pressure, fewer wires.

Full rules and the harness interface-class table: the
[Hardware Standards](../hardware/standards.md) Shift-Register I/O section and the
[Connector & Harness Guide](../hardware/connectors.md).

---

## D10 — Versioning: firmware and hardware release separately

**Decision:** firmware and hardware each carry their **own version** and release on their own
clock from this one repository, both through
[release-please](https://github.com/googleapis/release-please): **merging a release PR is the
release.** Docs follow `main` and are not versioned. **Tags are only for releases** — created by
release-please when a release PR merges, never by hand.

| Track | Tag | Counts commits under | Release PR updates |
|---|---|---|---|
| **Firmware** | `firmware-vX.Y.Z` | `Firmware/` | `Firmware/CHANGELOG.md`, every `library.json` |
| **Hardware** | `hardware-vX.Y.Z` | `PCB/` | `PCB/CHANGELOG.md`, `release:` in `PCB/manifest.yaml` |

Why not the alternatives:

- **One repo-wide version** — a silkscreen fix would bump the firmware version, and a firmware
  fix would imply new boards.
- **Firmware in its own repo** — the cleanest release story, but it loses the cross-layer PRs
  (spec + firmware + docs in one change) the project relies on.
- **A tag per board** — tried first, dropped: a tag should mean a release, and boards are released
  together, through the manifest.

Both tracks read the same Conventional Commits. **Path** decides which release a commit counts
toward — one touching `Firmware/` and `PCB/` counts for both. **Type** decides the effect: `feat`
and `fix` are listed and bump the version, **`!`** marks a breaking change and is listed first;
`docs`, `chore`, `ci`, `test` are neither listed nor bump. Release PRs open as drafts so neither
can be merged by accident.

### Firmware

- **One version for the whole library set.** The libraries ship together and share the CAN
  wire format, so a mixed set has no meaning. Every `Firmware/Libraries/*/library.json` carries
  the same version.
- Commits that touch only `Firmware/ScratchPad/` (the spec) don't count toward a release.
- **Before 1.0, a breaking change bumps the minor** version; 1.0 freezes the sketch API and the
  wire format.
- Third-party libraries stay declared as version ranges; each release records the versions it
  resolved to as a `dependencies.txt` release asset, rather than pinning them.

### Hardware

- **A hardware release means the boards in it are ready** — built, brought up, and verified. Which
  boards, at which version, is the **manifest** `PCB/manifest.yaml`: a board is listed only once
  it passes bring-up, with the commit it was made from, its fab order ID, and any rework it needed
  (errata). A revision that fails bring-up is never listed.
- Each board keeps the semver in its KiCad title block and back-silk `REVISION x.y.z` text
  ([Hardware Standards](../hardware/standards.md)); it must match the manifest at the commit the
  board was made from. Commits never bump a board — a revision is a human decision.
- **Release notes list each board and what changed in it**: after release-please publishes the
  release, a job adds a table of the boards (new / unchanged / moved) and, per board,
  [git-cliff](https://git-cliff.org)'s list of the commits that touched its folder. Mark a hardware
  break — a pinout, harness, mounting or minimum-firmware change — with `!`: `feat(pcb)!: …`.
  Hardware commits use the scope `pcb` (later `cad`).
- **Bumps while in 0.x:** a break bumps the minor version, anything else the patch.
- **A release captures the whole repository**, in-progress boards included. Each board folder
  carries a `README.md` stating its status (Released / In progress / Deprecated); the manifest is
  the authoritative list of what a release contains. CAD folders get the same READMEs once CAD
  joins the hardware release.
- **"Latest" on GitHub stays on firmware** — the release job hands the badge back after a hardware
  release.
- The first hardware release counts commits from `ff065bd4` (2026-07-10, release-please's
  `bootstrap-sha`) — `main`'s history starts 2026-07-06, after the 0.1.0 boards were made.

The release standard and checklist are in [Hardware Standards](../hardware/standards.md#releases);
the per-board fab bundle is tracked in [#314](https://github.com/OpenSkyHawk/OpenSkyhawk/issues/314).

---

## Related reading

- [CAN Bus Protocol](can-bus.md) — the full frame ID table, `ControlPacket` wire format,
  batching contract, and startup handshake.
- [DCS-BIOS vs HID](dcsbios-vs-hid.md) — the panel-author decision rule and worked examples.
- [Firmware Tiers](firmware-tiers.md) — what each tier does and the contracts between them.

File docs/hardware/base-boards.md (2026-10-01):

# Base Boards — Gateway/Bridge & PanelGroup

Two **reusable base boards** anchor every OpenSkyhawk controller. Instead of designing each
controller from scratch, every panel builds on one of these shared foundations: they carry the
common circuitry — power, CAN, the microcontroller, status LEDs — and break out the spare pins on
headers, so a new panel only adds the parts that make it special.

- **Gateway/Bridge** — the cockpit's single head node: the one board that talks to the PC.
- **PanelGroup base** — the workhorse sub-node that most panels start from.

Both share the same microcontroller footprint, the same CAN transceiver, the same 3.3 V regulator,
and the same status-LED scheme, so once you know one board you know the foundation of every board
in the cockpit.

## What every base board gives you
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

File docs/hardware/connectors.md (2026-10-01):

# Connector & Harness Guide

Two connector families cover the whole cockpit: **Molex Mini-Fit Jr** for power-class
harnesses (main bus, backlight), **JST-XH** for signal-class legs (I²C, SPI, switches).
Nothing smaller than **2.54 mm pitch** is used anywhere, and no third family is ever
introduced — every harness in the aircraft crimps with two tools
(Mini-Fit Jr: JRready ST6490-ACT · JST-XH: Engineer PA-09).
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

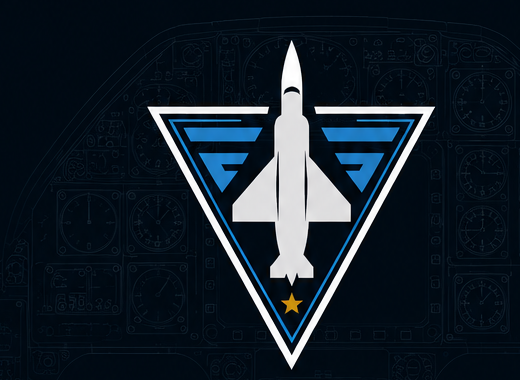
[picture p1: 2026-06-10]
docs/assets/images/brand/hero-art.png

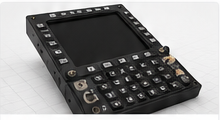
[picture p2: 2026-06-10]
docs/assets/images/brand/project-cdu.png

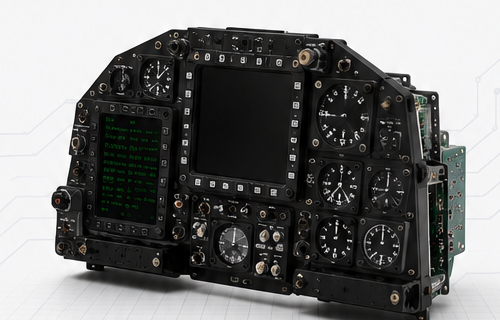
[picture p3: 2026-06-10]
docs/assets/images/brand/about-cockpit.png

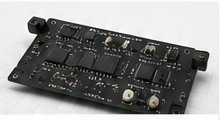
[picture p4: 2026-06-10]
docs/assets/images/brand/project-led-driver.png

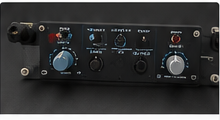
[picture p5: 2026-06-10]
docs/assets/images/brand/project-ufcp.png

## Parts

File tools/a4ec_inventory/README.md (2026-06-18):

# a4ec_inventory — A-4E-C master control inventory

Python 3 script that builds a single **row-per-control inventory** of the A-4E-C
cockpit by joining the Community Mod Lua with the DCS-BIOS control definitions.
It is the front-of-pipeline data source for the `panel-pipeline` skill (stage A1):
every controllable element classified by physical type, control method, routing,
and the OpenSkyhawk firmware class it maps to.

Unlike `gen_a4ec` (which emits committed build headers), this tool produces a
**reference CSV** — it is not a compile-time dependency.

## Output columns

| Column | Contents |
|---|---|
| `kind` | `input` (clickable control) · `output` (gauge/LED) · `hotas` (HID flight control) |
| `dcs_category` | DCS-BIOS category (⚠️ **not** the physical panel — e.g. AWRS controls sit under "Armament Panel"). Multi-element gauges carry a `[group]` tag |
| `native_id` | model-viewer / clickabledata ID = the join key |
| `identifier` | DCS-BIOS identifier (e.g. `ARM_EMERG_SEL`) |
| `name` | human description |
| `phys_type` | clickabledata constructor (`default_2_position_tumb`, `multiposition_switch_limited`, `default_axis_limited`, …) |
| `positions` | rotary position count |
| `routing` | `DCS-BIOS` · `HID` · `HID/keybind` |
| `address` | DCS-BIOS output address |
| `value_range` | gauge `max_value` (output range → stepper steps) |
| `ifaces` | DCS-BIOS input interfaces = the **method palette** (`set_state`, `fixed_step`, `variable_step`, `action`) |
| `fw_class` | mapped OpenSkyhawk firmware class |

## Sources & the join

All three live under the A4EC mod + DCS-BIOS (kept in `Firmware/ScratchPad/`, which
is **git-ignored** — these are third-party files, not committed). Pass `--mod` /
`--dcsbios` to point elsewhere.

| File | Provides |
|---|---|
| `<mod>/Cockpit/Scripts/clickabledata.lua` | physical control type (constructor) + native ID |
| `<dcsbios>/lib/modules/aircraft_modules/A-4E-C.lua` | `define<Type>("ID", dev, cmd, ARG, …)` — `ARG` = native ID |
| `<dcsbios>/doc/json/A-4E-C.json` | address + control_type + input interfaces; gauges + LEDs (outputs) |

**Join key = the native model-viewer ID** (clickabledata `PNT_<id>` == module `ARG`).
A clickable control with no module entry is HID/keybind-routed.

## Running

From the repo root (defaults assume the mod + DCS-BIOS are unpacked under
`Firmware/ScratchPad/`):

```bash
python tools/a4ec_inventory/a4ec_inventory.py --out inventory.csv --summary
```

Explicit source paths:

```bash
python tools/a4ec_inventory/a4ec_inventory.py \
  --mod "/path/to/A-4E-C" \
  --dcsbios "/path/to/DCS-BIOS" \
  --out inventory.csv --summary
```

`--out -` (default) writes the CSV to stdout; `--summary` prints counts to stderr.

## Classification notes & caveats

- **Rotaries are not auto-locked to one class.** DCS-BIOS exposes both `fixed_step`
  (encoder) and `set_state` (absolute) on every selector, so a multi-position
  control can be built as a switch (`SwitchMultiPos`), encoder (`RotaryEncoder`), or
  resistor ladder (`AnalogMultiPos`). `fw_class` shows the default; **>7 positions →
  ladder**, ≤7 is a per-panel judgment call. The pick is made at schematic time.
- **One control = a method palette.** The `ifaces` column lists every DCS-BIOS method
  the control supports; the hardware picks one, which determines both the firmware
  class and the command the firmware sends.
- **Gauges are composites.** Multi-element instruments (ADI = 6, altimeter ≈ 7,
  nav digit-drums = 5–6 each) are grouped by the `[group]` tag — each member is one
  stepper (`SwitecX25Output`).
- **`dcs_category` ≠ physical panel.** Use it only as a proxy; the real
  panel assignment comes from the DCS Model Viewer (panel-pipeline A2/B1).
- **HOTAS rows are curated.** Stick / throttle / rudder controls are keybinds in
  `Input/joystick/default.lua` (HID, not clickable), listed here by hand.
- **Confirm-in-sim set.** Push-to-set knobs (`default_button_axis`) and the exact
  rotary method warrant a Model Viewer / in-sim check before the build commits.

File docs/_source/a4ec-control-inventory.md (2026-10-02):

# A-4E-C control inventory (reference)

`a4ec-control-inventory.csv` (this directory) is the **curated master list of every controllable
element in the A-4E-C cockpit** — one row per control. It is the front-of-pipeline reference data
for panel research and controller building; **git holds this CSV, the GitHub Projects hold the
per-panel assignment + build state.**

## When to use it

Read this CSV whenever you need the ground truth for a control — building a panel's I/O, picking a
firmware class, wiring a schematic, or estimating a controller's budget. It answers, per control:
*what it is, how it's driven, where it routes, and which OpenSkyhawk building block it maps to.*

## Columns

| Column | Meaning |
|---|---|
| `kind` | `input` (clickable cockpit control) · `output` (gauge / LED) · `hotas` (HID flight control) |
| `dcs_category` | **curated** system/panel grouping (e.g. `Main Flight Instruments`, `Engine Instruments`, `Warning Lamps`, `T Handles`, `Radar Scope`). Authoritative — use as the grouping seed; **not** the raw DCS-BIOS category. |
| `native_id` | model-viewer / clickabledata ID (the join key to the mod files) |
| `identifier` | DCS-BIOS identifier, e.g. `ARM_EMERG_SEL` |
| `name` | human description |
| `phys_type` | clickabledata constructor (`default_2_position_tumb`, `multiposition_switch_limited`, `default_axis_limited`, `gauge`, `LED`, …) |
| `positions` | rotary position count |
| `routing` | `DCS-BIOS` (record `address`) · `HID` / `HID/keybind` (consumes GPIO/ADC, different firmware path) |
| `address` | DCS-BIOS address (DCSIN ≥ 0x8000 → PanelBridge) |
| `value_range` | gauge `max_value` (output range → stepper steps) |
| `ifaces` | DCS-BIOS input interface palette (`set_state` / `fixed_step` / `variable_step` / `action`) — the methods a control supports; hardware picks one at schematic time |
| `fw_class` | the OpenSkyhawk firmware class it maps to (`Switch2Pos`, `SwitchMultiPos`, `AnalogInput`, `SwitecX25Output`, `LED`, …) |

## Caveats

- **Identifier prefix ≠ physical panel.** A control's panel/console comes from the **GitHub Project**
  (Console field), not from the identifier or `dcs_category`. Some controls sit on a different panel
  than their prefix implies (e.g. `BDHI_MODE`, `RADAR_PROFILE/RANGE` are on the Misc Switch Panel).
- **Rotaries aren't locked to one class** — `fw_class` shows the default; the pick is made at
  schematic time by the selector rule in `hardware-standards.md`: a knob with a **marked position**
  reports it absolutely (`SwitchMultiPos` up to 12 positions, resistor-ladder `AnalogMultiPos`
  above); a knob with **no marked position** is a `RotaryEncoder`. Older `fw_class` hints such as
  `AnalogMultiPos(>7)` predate that rule.
- **Gauges are composites** — multi-element instruments (ADI, altimeter, nav drums) are several
  `SwitecX25Output` steppers grouped by identifier prefix.

## Regenerating

`tools/a4ec_inventory/a4ec_inventory.py` produces a **first cut** from the A-4E-C mod Lua + DCS-BIOS
(see its README). This CSV is that output **after human curation** (better `dcs_category` groups,
external-model rows dropped). Re-run the generator for a fresh first cut, then re-curate — don't
hand-edit blindly.

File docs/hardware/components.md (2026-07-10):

# Component Library

The standard parts that recur across OpenSkyhawk boards, with their KiCad symbols. Most are
KiCad built-ins; a few are in the shared `OpenSkyhawk` library. For how the library is wired up,
see [KiCad Workflow](kicad-workflow.md).

## Active parts

| Part | Package | Role | KiCad symbol |
|---|---|---|---|
| STM32F103C8 / CB | LQFP48 | CAN node MCU (C8 default all boards; CB drop-in fallback) | `MCU_ST_STM32F1:STM32F103CBTx` |
| SN65HVD230 | SOIC-8 | CAN transceiver, 3.3 V | `Interface_CAN_LIN:SN65HVD230` |
| MCP23017 | SOIC-28 | I²C digital I/O expander (16-bit) | `Interface_Expansion:MCP23017x-x-SO` |
| ADS1115 | — | I²C 16-bit ADC, 4 channels | `Analog_ADC:ADS1115` |
| AMS1117-3.3 | SOT-223 | 5 V → 3.3 V LDO (every board) | `Regulator_Linear:AMS1117-3.3_SOT223` |
| AO3400A | SOT-23 | LED zone MOSFET (low-side, logic-level, 30 V) | `OpenSkyhawk:Q_NMOS_GSD` |
| 8 MHz crystal | — | HSE for CAN timing | `Device:Crystal` |
| LED 5050 (red) | 6-pad 5050 | Panel backlight (5-in-series strings) | `OpenSkyhawk:LED_5050_Red` |

## Gauge steppers

| Part | Role | KiCad symbol |
|---|---|---|
| X27.589 | Gauge needle stepper (e.g. cabin pressure) | `OpenSkyhawk:X27.589_Stepper` |
| X27.168 | Gauge needle stepper (single-mount variant) | `OpenSkyhawk:X27.168_Stepper` |

!!! note "Stepper driver: DRV8833"
    The gauge needle steppers are driven by a **DRV8833** dual H-bridge — four logic inputs per
    motor (two coils), motor supply (VM) on the **5 V** rail. Drive the X27 air-core at 5 V.

## High-current boards only

| Part | Package | Role | KiCad symbol |
|---|---|---|---|
| AP63205WU | SOT-23-6 | 12 V → 5 V switching buck | `OpenSkyhawk:AP63205WU` *(pending — add when first needed)* |

Standard MCU and breakout boards do **not** carry this — they draw 5 V from the bus. It's only
for future high-5V-current boards. See [Power Architecture](../architecture/power.md).

## Notes

- The custom `OpenSkyhawk` symbols (LED 5050, the `Q_NMOS_GSD` N-FET, the steppers) live in
  `PCB/Libraries/OpenSkyhawk.kicad_sym` + `OpenSkyhawk.pretty/`. Everything else is a KiCad
  built-in — no custom entry needed.
- SN65HVD230 3.3 V clones (e.g. VP230) are acceptable for JLCPCB assembly.
- The **MCP23017 GPA7/GPB7 input restriction** (silicon bug — output only) is covered in
  [Hardware Standards](standards.md).

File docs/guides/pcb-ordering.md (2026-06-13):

# PCB Ordering (JLCPCB)

OpenSkyhawk boards are designed for **JLCPCB's standard 2-layer service**. The design rules are
already tuned for it ([PCB Design Rules](../hardware/pcb-design-rules.md)); this guide is how to
get from a finished layout to an order.

## 1. Export the fab files

From a clean, DRC-passing layout, export Gerbers and drill data with the KiCad CLI:

```bash
KICAD=/Applications/KiCad/KiCad.app/Contents/MacOS/kicad-cli

$KICAD pcb export gerbers --output ./gerbers/ <board.kicad_pcb>
$KICAD pcb export drill   --output ./gerbers/ <board.kicad_pcb>
```

Run DRC first — fix everything before ordering:

```bash
$KICAD pcb drc --output drc.json <board.kicad_pcb>
```

Zip the `gerbers/` directory. (Gerbers and drill files are generated output — **gitignored**,
not committed.)

## 2. Upload and configure

Upload the zip to JLCPCB. The cost-optimised settings, all under **High-Spec Options**:

| Option | Setting |
|---|---|
| Layers | 2 |
| Outer copper weight | 1 oz |
| Via covering | Tented |
| Min via | 0.3 mm |
| Outline tolerance | ±0.2 mm (Regular) |
| Electrical test | Flying-probe (included) |
| Mark on PCB | Remove mark |
| Confirm production file | No (faster lead time) |
| Gold fingers / castellation / edge plating | No |

These match the constraints the boards are designed to, so the order should pass review without
back-and-forth.

## 3. Assembly

Most OpenSkyhawk boards are hand-/reflow-assembled rather than ordered with JLCPCB SMT
assembly — the package choices are all reflow-and-inspect friendly by design. See
[Assembly & Soldering](assembly.md).

!!! note "Panel cutout template"
    Need a panel cutout to match the board outline? Export a DXF:
    `kicad-cli pcb export dxf --output cutout.dxf <board.kicad_pcb>`.

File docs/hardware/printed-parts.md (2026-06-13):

---
status: stub
---

# Printed Parts Library

!!! warning "Work in Progress"
    This page is being written. Check back soon or
    [contribute to the docs](../contributing/index.md).

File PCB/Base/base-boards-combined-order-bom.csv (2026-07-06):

Category | Item | Value | Package | Per Gateway | Per PanelGroup | Need (5 of each) | Order Qty (incl spares) | LCSC# | Spec / suggested MPN | Notes
Resistor | R | 3.3k | 0805 | 5 | 3 | 40 | 50 |  | 0805 1% 1/8W | LED + power-LED series
Resistor | R | 4.7k | 0805 | 4 | 4 | 40 | 50 |  | 0805 1% | I2C pull-ups (2 per bus)
Resistor | R | 10k | 0805 | 2 | 2 | 20 | 30 |  | 0805 1% | NRST + BOOT0 pulldown (R6 + R_BOOT1)
Resistor | R | 33 | 0805 | 7 | 5 | 60 | 75 |  | 0805 1% | I2C/SWDIO/UART series
Resistor | R | 100 | 0805 | 0 | 6 | 30 | 50 |  | 0805 1% | PanelGroup INT lines + MOSFET gate series
Resistor | R | 120 | 0805 | 1 | 1 | 10 | 20 |  | 0805 1% | CAN termination (behind J_CAN_TERM jumper)
Resistor | R | 100k | 0805 | 0 | 2 | 10 | 20 |  | 0805 1% | PanelGroup MOSFET gate pulldown
Capacitor | C | 100nF | 0805 | 8 | 8 | 80 | 100 |  | X7R 50V | Decoupling + bus-entry HF; normalize C1 "100nf" -> 100nF
Capacitor | C | 22pF | 0805 | 2 | 2 | 20 | 30 |  | C0G/NP0 50V | Crystal load caps - C0G dielectric only
Capacitor | C | 1uF | 0805 | 1 | 1 | 10 | 20 |  | X7R | VDDA filter
Capacitor | C | 10uF | 0805 | 1 | 1 | 10 | 20 |  | X5R 25V | Bus-entry bulk C14 (+5V). 25V fine on the 5V rail. X5R = cheaper/Basic
Capacitor | C | 10uF | 0805 | 1 | 1 | 10 | 20 | C49010152 | X5R 35V | Bus-entry bulk C15 (+12V). 35V for +12V DC-bias derating + headroom over the 19.9V SMBJ12A clamp
Capacitor (polarized) | C | 10uF | Elec 4x5.4 SMD | 1 | 1 | 10 | 15 |  | Alu electrolytic >=16V | AMS1117 input bulk - mind polarity
Capacitor (polarized) | C | 22uF | Elec 4x5.4 SMD | 1 | 1 | 10 | 15 |  | Alu electrolytic >=10V | AMS1117 output bulk (loop stability) - mind polarity
TVS | D | SMBJ12A | SMB/DO-214AA | 1 | 1 | 10 | 20 | C42368008 | SMBJ12A | Input-rail TVS +12V->GND at J_BUS_IN. Unidirectional, 19.9V clamp. Fleet standard (both boards)
TVS | D | SMBJ6.0A | SMB/DO-214AA | 1 | 1 | 10 | 20 | C5331096 | SMBJ6.0A (MSKSEMI) | Input-rail TVS +5V->GND at J_BUS_IN. Unidirectional, 10.3V clamp. Fleet standard (both boards). MOQ 20
LED | D | Green | 0805 | 3 | 2 | 25 | 35 |  | Yellow-green ~2.1V Vf | NOT pure-green (~3.1V wont light on 3.3V rail)
LED | D | Red | 0805 | 2 | 1 | 15 | 25 |  | Standard red 0805
IC | U1 | STM32F103C8T6 | LQFP-48 | 1 | 1 | 10 | 12 |  | STM32F103C8T6 | +2 spare (reflow risk). Often LCSC Extended
IC | U2 | SN65HVD230DR | SOIC-8 | 1 | 1 | 10 | 12 |  | SN65HVD230DR | CAN transceiver. Rs=GND high-speed
IC | U3 | AMS1117-3.3 | SOT-223 | 1 | 1 | 10 | 13 |  | AMS1117-3.3 | LDO. LCSC Basic
MOSFET | Q | AO3400A | SOT-23 | 0 | 2 | 10 | 15 | C49195711 | AO3400A | Logic-level N-ch backlight driver (PanelGroup only). 30V (was IRLML2502 20V) for headroom over the 19.9V TVS clamp; Vgs op @2.5V so 3.3V-driven
Module | U4 | RP2040-Zero | Waveshare module | 1 | 0 | 5 | 6 |  | Waveshare RP2040-Zero | May NOT be on LCSC - order Waveshare/Amazon. THT hand-solder
Crystal | Y1 | 8MHz | SMD 5.0x3.2mm 2-pad | 1 | 1 | 10 | 13 |  | 8MHz CL~18-20pF | Match load to the 22pF caps
Switch | SW1 | Tactile RESET | 6mm THT | 1 | 1 | 10 | 13 |  | 6mm THT tactile | THT - hand-solder
Connector | J | JST-XH 3-pin | B3B-XH-A vert | 1 | 1 | 10 | 13 |  | JST B3B-XH-A | J_DIAG. THT. Need mating housing + crimps (separate)
Connector | J | JST-XH 4-pin | B4B-XH-A vert | 2 | 0 | 10 | 13 |  | JST B4B-XH-A | Gateway I2C display headers. THT
Connector | J | JST-XH 8-pin | B8B-XH-A vert | 0 | 2 | 10 | 13 |  | JST B8B-XH-A | PanelGroup I2C+INT headers. THT
Connector | J | Pin header 1x2 | 2.54mm vert | 1 | 1 | 10 conn | from strips |  | 1x40 breakaway | J_CAN_TERM. Snap from 1x40 strip
Connector | J | Pin header 1x5 | 2.54mm vert | 1 | 1 | 10 conn | from strips |  | 1x40 breakaway | J_SWD. Snap from 1x40 strip
Connector | J | Pin header 1x20 | 2.54mm vert | 1 | 0 | 5 conn | from strips |  | 1x40 breakaway | Gateway STM32 breakout. Snap from 1x40 strip
Connector | J | Pin header 2x7 | 2.54mm vert | 0 | 1 | 5 conn | from strips |  | 2x40 dual breakaway | PanelGroup breakout. Snap from 2x40 strip
Connector | J | Molex Mini-Fit Jr 2x4 | 5566 vertical | 2 | 2 | 20 | 24 |  | Molex 5566-08A (or 08A2 w/ pegs) | Bus in/out. THT. Need mating receptacle + crimps (separate)
Connector | J | Molex Mini-Fit Jr 2x01 | 5566 vertical | 0 | 2 | 10 | 14 |  | Molex 5566-02A (or 02A2 w/ pegs) | PanelGroup backlight feed. THT. Need mating + crimps
Header strip | - | Pin header strip 1x40 | 2.54mm | - | - | - | 5 |  | 1x40 2.54mm breakaway | Covers all 1xN single-row headers (170 pins needed)
Header strip | - | Pin header strip 2x40 | 2.54mm | - | - | - | 2 |  | 2x40 2.54mm dual breakaway | Covers the 2x7 breakouts (70 pins needed)

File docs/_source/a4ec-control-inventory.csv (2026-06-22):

kind | dcs_category | native_id | identifier | name | phys_type | positions | routing | address | value_range | ifaces | fw_class
input | Start | 0 | THROTTLE_CLICK | Throttle Position Lock | default_3_position_tumb |  | DCS-BIOS | 0x850E |  | fixed_step,set_state | Switch3Pos
input | Mechanical Systems | 8 | GEAR_HANDLE | Landing Gear Handle | default_2_position_tumb |  | DCS-BIOS | 0x8508 |  | fixed_step,set_state,action | Switch2Pos
input | Mechanical Systems | 10 | HOOK_HANDLE | Arresting Hook Handle | default_2_position_tumb |  | DCS-BIOS | 0x8508 |  | fixed_step,set_state,action | Switch2Pos
input | Ejection Seat | 24 | HARNESS_REEL_CONTR | Shoulder Harness Control Handle | default_2_position_tumb |  | DCS-BIOS | 0x8544 |  | fixed_step,set_state,action | Switch2Pos
input | Ejection Seat | 25 | SEC_EJECT_HANDLE | Alternate Ejection Handle | default_2_position_tumb |  | DCS-BIOS | 0x8544 |  | fixed_step,set_state,action | Switch2Pos
input | Mechanical Systems | 82 | RUDDER_TRIM | Rudder Trim Switch | default_axis_limited |  | DCS-BIOS | 0x850C |  | set_state,variable_step | AnalogInput
input | OFF | 83 | LIGHT_EXT_MASTER | Master Exterior Lights Switch | multiposition_switch_limited |  | DCS-BIOS | 0x8522 |  | fixed_step,set_state | SwitchMultiPos/enc/ladder
input | Mechanical Systems | 84 | SPOILER_ARM | Spoiler Arm Switch | default_2_position_tumb |  | DCS-BIOS | 0x8508 |  | fixed_step,set_state,action | Switch2Pos
input | Mechanical Systems | 85 | SPEEDBRAKE | Speedbrake Switch | default_2_position_tumb |  | DCS-BIOS | 0x8508 |  | fixed_step,set_state,action | Switch2Pos
input | Mechanical Systems | 100 | STARTER_BTN | Engine Starter Switch | default_2_position_tumb |  | DCS-BIOS | 0x850E |  | fixed_step,set_state,action | Switch2Pos
input | Fuel Systems | 101 | DROP_PRESS_REFUEL | Drop Tank Pressurization Switch | default_3_position_tumb |  | DCS-BIOS | 0x850E |  | fixed_step,set_state | Switch3Pos
input | Fuel Systems | 103 | EMERG_TRANS_FUEL_DUMP | Fuel Dump Switch | default_3_position_tumb |  | DCS-BIOS | 0x850E |  | fixed_step,set_state | Switch3Pos
input | Fuel Systems | 104 | FUEL_CONTROL | Fuel Control Switch | default_2_position_tumb |  | DCS-BIOS | 0x850E |  | fixed_step,set_state,action | Switch2Pos
input | Lights | 106 | LIGHT_INT_INSTR | Instrument Lights Control | default_axis_limited |  | DCS-BIOS | 0x8534 |  | set_state,variable_step | AnalogInput
input | Lights | 107 | LIGHT_INT_CONSOLE | Console Lights Control | default_axis_limited |  | DCS-BIOS | 0x8536 |  | set_state,variable_step | AnalogInput
input | Lights | 108 | LIGHT_INT_BRIGHT | Instrument Lights Brightness | multiposition_switch_limited_inverted |  | DCS-BIOS | 0x8532 |  | fixed_step,set_state | SwitchMultiPos/enc/ladder
input | Lights | 110 | LIGHT_INT_FLOOD_WHT | White Floodlights Control | default_axis_limited |  | DCS-BIOS | 0x8538 |  | set_state,variable_step | AnalogInput
input | Radar Control Panel | 120 | RADAR_MODE | AN/APG-53A Radar Mode Switch | multiposition_switch_limited | 5 | DCS-BIOS | 0x84EA |  | fixed_step,set_state | SwitchMultiPos/enc/ladder
input | Radar Control Panel | 121 | RADAR_AOACOMP | Radar AoA Compensation Switch | default_2_position_tumb |  | DCS-BIOS | 0x84EA |  | fixed_step,set_state,action | Switch2Pos
input | Radar Control Panel | 122 | RADAR_ANGLE | Radar Antenna Tilt Switch | default_axis_limited |  | DCS-BIOS | 0x84EE |  | set_state,variable_step | AnalogInput
input | Radar Control Panel | 123 | RADAR_VOL | Radar Obstacle Tone Volume | default_axis_limited |  | DCS-BIOS | 0x84F0 |  | set_state,variable_step | AnalogInput
input | Avionics | 125 | OXY_SW | Oxygen Switch | default_2_position_tumb |  | DCS-BIOS | 0x850E |  | fixed_step,set_state,action | Switch2Pos
input | Mechanical Systems | 128 | SPEEDBRAKE_EMERG | Emergency Speedbrake Knob | default_3_position_tumb |  | DCS-BIOS | 0x8508 |  | fixed_step,set_state | Switch3Pos
input | Fuel Systems | 130 | MAN_FUEL_OFF_LV | Manual Fuel Shutoff Control Lever | default_2_position_tumb |  | DCS-BIOS | 0x850E |  | fixed_step,set_state,action | Switch2Pos
input | Fuel Systems | 131 | MAN_FUEL_OFF_CATCH | Manual Fuel Shutoff Control Catch | default_2_position_tumb |  | DCS-BIOS | 0x850E |  | fixed_step,set_state,action | Switch2Pos
input | Mechanical Systems | 132 | FLAPS | Flap Handle | multiposition_switch_limited |  | DCS-BIOS | 0x8508 |  | fixed_step,set_state | SwitchMultiPos/enc/ladder
input | Mechanical Systems | 133 | JATO_ARM | JATO Arming Switch | default_2_position_tumb |  | DCS-BIOS | 0x850E |  | fixed_step,set_state,action | Switch2Pos
input | Mechanical Systems | 134 | JATO_JETT_SAFE | JATO Jettison Switch | default_2_position_tumb |  | DCS-BIOS | 0x850E |  | fixed_step,set_state,action | Switch2Pos
input | Stby | 135 | APC_ENABLE | APC Power Switch | multiposition_switch_limited |  | DCS-BIOS | 0x8508 |  | fixed_step,set_state | SwitchMultiPos/enc/ladder
input | Std | 136 | APS_COLD_STD_HOT | APC Temperature Switch | multiposition_switch_limited |  | DCS-BIOS | 0x8508 |  | fixed_step,set_state | SwitchMultiPos/enc/ladder
input | Avionics | 139 | ACCEL_RESET | Accelerometer Reset | default_button |  | DCS-BIOS | 0x850E |  | fixed_step,set_state,action | Switch2Pos
input | Clock | 146 | STOPWATCH | Elapsed-Time Clock | default_button |  | DCS-BIOS | 0x850E |  | fixed_step,set_state,action | Switch2Pos
input | AFCS | 160 | AFCS_STBY | AFCS Standby Switch | default_2_position_tumb |  | DCS-BIOS | 0x8502 |  | fixed_step,set_state,action | Switch2Pos
input | AFCS | 161 | AFCS_ENGAGE | AFCS Engage Switch | default_2_position_tumb |  | DCS-BIOS | 0x8502 |  | fixed_step,set_state,action | Switch2Pos
input | AFCS | 162 | AFCS_HDG_SEL | AFCS Heading Select Switch | default_2_position_tumb |  | DCS-BIOS | 0x8502 |  | fixed_step,set_state,action | Switch2Pos
input | AFCS | 163 | AFCS_ALT | AFCS Altitude Switch | default_2_position_tumb |  | DCS-BIOS | 0x8508 |  | fixed_step,set_state,action | Switch2Pos
input | AFCS | 164 | AFCS_HDG_SET | AFCS Heading Select Pull-to-Set Knob | default_axis_limited |  | DCS-BIOS | 0x850A |  | variable_step | AnalogInput
input | AFCS | 165 | AFCS_STAB_AUG | AFCS Stability Augmentation Switch (Yaw Damper) | default_2_position_tumb |  | DCS-BIOS | 0x8508 |  | fixed_step,set_state,action | Switch2Pos
input | AFCS | 166 | AFCS_AIL_TRIM | AFCS Aileron Trim Switch (unimplemented) | default_2_position_tumb |  | DCS-BIOS | 0x8508 |  | fixed_step,set_state,action | Switch2Pos
input | Doppler Nav | 170 | DOPPLER_SEL | AN/APN-153 Doppler Navigation Radar Mode Switch | multiposition_switch_limited | 5 | DCS-BIOS | 0x8522 |  | fixed_step,set_state | AnalogMultiPos
input | Doppler Nav | 176 | NAV_SEL | AN/ASN-41 Function Selector Switch | multiposition_switch_limited | 5 | DCS-BIOS | 0x8522 |  | fixed_step,set_state | AnalogMultiPos
input | Lights | 217 | LIGHT_EXT_PROBE | Probe Light Switch | multiposition_switch_limited |  | DCS-BIOS | 0x8532 |  | fixed_step,set_state | SwitchMultiPos/enc/ladder
input | Lights | 218 | LIGHT_EXT_TAXI | Taxi Light Switch | default_2_position_tumb |  | DCS-BIOS | 0x8522 |  | fixed_step,set_state,action | Switch2Pos
input | Lights | 219 | LIGHT_EXT_ANTICOLL | Anti-Collision Light Switch | default_2_position_tumb |  | DCS-BIOS | 0x8532 |  | fixed_step,set_state,action | Switch2Pos
input | Lights | 220 | LIGHT_EXT_FUSELAGE | Fuselage Light Switch | multiposition_switch_limited |  | DCS-BIOS | 0x8532 |  | fixed_step,set_state | SwitchMultiPos/enc/ladder
input | Lights | 221 | LIGHT_EXT_FLASH_MODE | Lighting Flash/Steady Switch | default_2_position_tumb |  | DCS-BIOS | 0x8532 |  | fixed_step,set_state,action | Switch2Pos
input | Lights | 222 | LIGHT_EXT_NAV | Navigation Lights Switch | multiposition_switch_limited |  | DCS-BIOS | 0x8532 |  | fixed_step,set_state | SwitchMultiPos/enc/ladder
input | Lights | 223 | LIGHT_EXT_TAIL | Tail Light Switch | multiposition_switch_limited |  | DCS-BIOS | 0x8532 |  | fixed_step,set_state | SwitchMultiPos/enc/ladder
input | Air Condition | 224 | CABIN_PRESS | Cabin Pressure Switch | default_2_position_tumb |  | DCS-BIOS | 0x8544 |  | fixed_step,set_state,action | Switch2Pos
input | Air Condition | 225 | WINDSHLD_DEFROST | Windshield Defrost Switch | default_3_position_tumb |  | DCS-BIOS | 0x8544 |  | fixed_step,set_state | Switch3Pos
input | Air Condition | 226 | CABIN_TEMP | Cabin Temperature Knob | default_axis_limited |  | DCS-BIOS | 0x8546 |  | set_state,variable_step | AnalogInput
input | Doppler Nav | 236 | PPOS_LAT_BTN | Present Latitude Push-to-Set Knob | default_button_axis |  | DCS-BIOS | 0x8522 |  | fixed_step,set_state,action | Switch2Pos
input | Doppler Nav | 237 | PPOS_LON_BTN | Present Longitude Push-to-Set Knob | default_button_axis |  | DCS-BIOS | 0x8522 |  | fixed_step,set_state,action | Switch2Pos
input | Doppler Nav | 238 | DEST_LAT_BTN | Destination Latitude Push-to-Set Knob | default_button_axis |  | DCS-BIOS | 0x8522 |  | fixed_step,set_state,action | Switch2Pos
input | Doppler Nav | 239 | DEST_LON_BTN | Destination Longitude Push-to-Set Knob | default_button_axis |  | DCS-BIOS | 0x8522 |  | fixed_step,set_state,action | Switch2Pos
input | Doppler Nav | 240 | ASN41_MAGVAR_BTN | Magnetic Variation Push-to-Set Knob | default_button_axis |  | DCS-BIOS | 0x8522 |  | fixed_step,set_state,action | Switch2Pos
input | Doppler Nav | 241 | ASN41_WINDSPEED_BTN | Wind Speed Push-to-Set Knob | default_button_axis |  | DCS-BIOS | 0x8522 |  | fixed_step,set_state,action | Switch2Pos
input | Doppler Nav | 242 | ASN41_WINDDIR_BTN | Wind Direction Push-to-Set Knob | default_button_axis |  | DCS-BIOS | 0x8522 |  | fixed_step,set_state,action | Switch2Pos
input | Doppler Nav | 177 | PPOS_LAT_KNB | ASN-41 Present Position - Latitude Knob | analog_dial |  | DCS-BIOS | 0x8524 | 0-65535 | variable_step | RotaryEncoder
input | Doppler Nav | 183 | PPOS_LON_KNB | ASN-41 Present Position - Longitude Knob | analog_dial |  | DCS-BIOS | 0x8526 | 0-65535 | variable_step | RotaryEncoder
input | Doppler Nav | 190 | DEST_LAT_KNB | ASN-41 Destination - Latitude Knob | analog_dial |  | DCS-BIOS | 0x8528 | 0-65535 | variable_step | RotaryEncoder
input | Doppler Nav | 196 | DEST_LON_KNB | ASN-41 Destination - Longitude Knob | analog_dial |  | DCS-BIOS | 0x852a | 0-65535 | variable_step | RotaryEncoder
input | Doppler Nav | 203 | ASN41_MAGVAR_KNB | ASN-41 Magnetic Variation Knob | analog_dial |  | DCS-BIOS | 0x852c | 0-65535 | variable_step | RotaryEncoder
input | Doppler Nav | 209 | ASN41_WINDSPEED_KNB | ASN-41 Wind Speed Knob | analog_dial |  | DCS-BIOS | 0x852e | 0-65535 | variable_step | RotaryEncoder
input | Doppler Nav | 213 | ASN41_WINDDIR_KNB | ASN-41 Wind Direction Knob | analog_dial |  | DCS-BIOS | 0x8530 | 0-65535 | variable_step | RotaryEncoder
input | Doppler Nav | 247 | DOPPLER_MEM_TEST | AN/APN-153 Memory Light Test | default_button |  | DCS-BIOS | 0x8512 |  | fixed_step,set_state,action | Switch2Pos
input | Doppler Nav | 248 | ASN41_LAT_SLEW | Destination Latitude Slew Knob | springloaded_3_pos_tumb |  | DCS-BIOS | 0x8544 |  | fixed_step,set_state | Switch3Pos
input | Doppler Nav | 249 | ASN41_LON_SLEW | Destination Longitude Slew Knob | springloaded_3_pos_tumb |  | DCS-BIOS | 0x8544 |  | fixed_step,set_state | Switch3Pos
input | MCL | 250 | MCL_CHAN_SEL | MCL Channel Selector Switch | multiposition_switch_limited | 20 | DCS-BIOS | 0x854C |  | fixed_step,set_state | AnalogMultiPos(>7)
input | Mechanical Systems | 251 | SEAT_ADJ | Seat Adjustment Switch | springloaded_3_pos_tumb |  | DCS-BIOS | 0x854C |  | fixed_step,set_state | Switch3Pos
input | T Handles | 252 | EMERG_GEN_BYPASS | Emergency Generator Switch | default_2_position_tumb |  | DCS-BIOS | 0x853E |  | fixed_step,set_state,action | Switch2Pos
input | MCL | 253 | MCL_PWR | AN/ARA-63 MCL Power Switch | springloaded_forward_only_3_pos_tumb |  | DCS-BIOS | 0x854C |  | fixed_step,set_state | Switch3Pos
input | TACAN | 254 | TACAN_ANT_CONT | TACAN Antenna Control Switch (unimplemented) | inverted_3_position_tumb |  | DCS-BIOS | 0x854C |  | fixed_step,set_state | Switch3Pos
input | MCL | 255 | NAV_DEAD | Navigation Dead Reckoning/Doppler Switch (unimplemented) | default_2_position_tumb |  | DCS-BIOS | 0x8554 |  | fixed_step,set_state,action | Switch2Pos
input | Fuel Systems | 256 | FUEL_TRANS | Fuel Transfer Switch | default_2_position_tumb |  | DCS-BIOS | 0x8554 |  | fixed_step,set_state,action | Switch2Pos
input | Avionics | 257 | RAIN_REMOVE | Rain Removal Switch (unimplemented) | default_2_position_tumb |  | DCS-BIOS | 0x8554 |  | fixed_step,set_state,action | Switch2Pos
input | AFCS | 258 | AFCS_1N2_COVER | AFCS 1-N-2 Guard Switch | default_2_position_tumb |  | DCS-BIOS | 0x854C |  | fixed_step,set_state,action | Switch2Pos
input | AFCS | 259 | AFCS_1N2 | AFCS 1-N-2 Switch | springloaded_3_pos_tumb |  | DCS-BIOS | 0x854C |  | fixed_step,set_state | Switch3Pos
input | UHF Radio | 361 | ARC51_FREQ_PRE | Radio Preset Channel Selector | multiposition_switch_limited | 20 | DCS-BIOS | 0x853A |  | fixed_step,set_state | RotaryEncoder
input | UHF Radio | 365 | ARC51_VOL | Radio Volume | default_axis_limited |  | DCS-BIOS | 0x853C |  | set_state,variable_step | AnalogInput
input | UHF Radio | 366 | ARC51_XMIT_MODE | Radio Frequency Mode | multiposition_switch_limited |  | DCS-BIOS | 0x8532 |  | fixed_step,set_state | Switch3Pos
input | UHF Radio | 367 | ARC51_FREQ_10MHZ | Radio Frequency 10 MHz | multiposition_switch_limited | 18 | DCS-BIOS | 0x853A |  | fixed_step,set_state | RotaryEncoder
input | UHF Radio | 368 | ARC51_FREQ_1MHZ | Radio Frequency 1 MHz | multiposition_switch_limited | 10 | DCS-BIOS | 0x853A |  | fixed_step,set_state | RotaryEncoder
input | UHF Radio | 369 | ARC51_FREQ_50KHZ | Radio Frequency 50 kHz | multiposition_switch_limited | 20 | DCS-BIOS | 0x853E |  | fixed_step,set_state | RotaryEncoder
input | UHF Radio | 370 | ARC51_SQUELCH | Radio Squelch Disable | default_2_position_tumb |  | DCS-BIOS | 0x8532 |  | fixed_step,set_state,action | Switch2Pos
input | UHF Radio | 372 | ARC51_MODE | AN/ARC-51A UHF Radio Mode Switch | multiposition_switch_limited | 4 | DCS-BIOS | 0x853A |  | fixed_step,set_state | SwitchMultiPos
input | Off | 390 | GUNPOD_CLEAR | Gunpod Switch | multiposition_switch_limited |  | DCS-BIOS | 0x84EA |  | fixed_step,set_state | SwitchMultiPos/enc/ladder
input | Gunpods | 391 | GUNPOD_L | Gunpod Station LH Switch | default_2_position_tumb |  | DCS-BIOS | 0x84EA |  | fixed_step,set_state,action | Switch2Pos
input | Gunpods | 392 | GUNPOD_C | Gunpod Station CTR Switch | default_2_position_tumb |  | DCS-BIOS | 0x84EA |  | fixed_step,set_state,action | Switch2Pos
input | Gunpods | 393 | GUNPOD_R | Gunpod Station RH Switch | default_2_position_tumb |  | DCS-BIOS | 0x84EA |  | fixed_step,set_state,action | Switch2Pos
input | Radar Scope | 400 | RADAR_STORAGE | Radar Indicator Storage | default_axis_limited |  | DCS-BIOS | 0x84F2 |  | set_state,variable_step | AnalogInput
input | Radar Scope | 401 | RADAR_BRILLIANCE | Radar Indicator Brilliance | default_axis_limited |  | DCS-BIOS | 0x84F4 |  | set_state,variable_step | AnalogInput
input | Radar Scope | 402 | RADAR_DETAIL | Radar Indicator Detail | default_axis_limited |  | DCS-BIOS | 0x84F6 |  | set_state,variable_step | AnalogInput
input | Radar Scope | 403 | RADAR_GAIN | Radar Indicator Gain | default_axis_limited |  | DCS-BIOS | 0x84F8 |  | set_state,variable_step | AnalogInput
input | Radar Scope | 404 | RADAR_RETICLE | Radar Indicator Reticle | default_axis_limited |  | DCS-BIOS | 0x84FA |  | set_state,variable_step | AnalogInput
input | Radar Scope | 405 | RADAR_FILTER | Radar Indicator Filter Plate | default_2_position_tumb |  | DCS-BIOS | 0x84EA |  | fixed_step,set_state,action | Switch2Pos
input | ECM Panel | 501 | ECM_APR27_PW | APR-27 Switch | default_2_position_tumb |  | DCS-BIOS | 0x853E |  | fixed_step,set_state,action | Switch2Pos
input | ECM Panel | 502 | ECM_SEL | AN/APR-25 Function Selector Switch | multiposition_switch_limited | 4 | DCS-BIOS | 0x853E |  | fixed_step,set_state | SwitchMultiPos/enc/ladder
input | ECM Panel | 503 | ECM_AUDIO | Audio ALQ Switch | default_2_position_tumb |  | DCS-BIOS | 0x853E |  | fixed_step,set_state,action | Switch2Pos
input | ECM Panel | 504 | ECM_APR25_PW | APR-25 Switch | default_2_position_tumb |  | DCS-BIOS | 0x853E |  | fixed_step,set_state,action | Switch2Pos
input | ? | 505 | ECM_MSL_VOL | Missile Alert Volume | default_axis_limited |  | DCS-BIOS | 0x8542 |  | set_state,variable_step | AnalogInput
input | ? | 506 | ECM_PRF_VOL | PRF Volume | default_axis_limited |  | DCS-BIOS | 0x8540 |  | set_state,variable_step | AnalogInput
input | ECM Panel | 507 | ECM_APR27_TEST | APR-27 Test | default_button |  | DCS-BIOS | 0x853E |  | fixed_step,set_state,action | Switch2Pos
input |  | 509 |  | Compass Latitude Knob (unimplemented) | default_axis_limited |  | HID/keybind |  |  |  | AnalogInput
input | ECM Panel | 510 | ECM_APR27_LIGHT | APR-27 Light | default_button |  | DCS-BIOS | 0x853E |  | fixed_step,set_state,action | Switch2Pos
input |  | 511 |  | Compass Heading Set Knob (unimplemented) | springloaded_3_pos_tumb |  | HID/keybind |  |  |  | Switch3Pos
input |  | 512 |  | Compass Mode (unimplemented) | default_2_position_tumb |  | HID/keybind |  |  |  | Switch2Pos
input |  | 513 |  | Compass Push-to-Sync (unimplemented) | default_button |  | HID/keybind |  |  |  | Switch2Pos
input | Countermeasures | 522 | CM_BANK | Dispenser Select | multiposition_switch_limited |  | DCS-BIOS | 0x84EA |  | fixed_step,set_state | SwitchMultiPos/enc/ladder
input | Countermeasures | 523 | CM_AUTO | Chaff AUTO Pushbutton (ALE-29A Salvo) | default_button |  | DCS-BIOS | 0x84EA |  | fixed_step,set_state,action | Switch2Pos
input | Countermeasures | 524 | CM_ADJ1 | Dispenser 1 Counter | default_axis |  | DCS-BIOS | 0x84FC |  | variable_step | AnalogInput
input | Countermeasures | 525 | CM_ADJ2 | Dispenser 2 Counter | default_axis |  | DCS-BIOS | 0x84FE |  | variable_step | AnalogInput
input | Countermeasures | 530 | CM_PWR | Chaff Power Switch | default_2_position_tumb |  | DCS-BIOS | 0x84EA |  | fixed_step,set_state,action | Switch2Pos
input | Avionics | 603 | RADAR_ALT_SW | AN/APN-141 Radar Altimeter | default_button_axis |  | DCS-BIOS | 0x850E |  | fixed_step,set_state,action | PushSetKnob
input | Avionics | 663 | STBY_ATT_INDEX_BTN | Standby Attitude Horizon | default_button_axis |  | DCS-BIOS | 0x8512 |  | fixed_step,set_state,action | PushSetKnob
input | Armament Panel | 700 | ARM_EMERG_SEL | Emergency Release Selector | multiposition_switch_limited | 7 | DCS-BIOS | 0x8500 |  | fixed_step,set_state | AnalogMultiPos
input | Armament Panel | 701 | ARM_GUN | Guns Charging Switch | default_2_position_tumb |  | DCS-BIOS | 0x84EA |  | fixed_step,set_state,action | Switch2Pos
input | Armament Panel | 702 | ARM_BOMB | Bomb Arm Switch | default_3_position_tumb |  | DCS-BIOS | 0x8500 |  | fixed_step,set_state | Switch3Pos
input | Armament Panel | 703 | ARM_STATION1 | Station 1 Selector Switch | default_2_position_tumb |  | DCS-BIOS | 0x8500 |  | fixed_step,set_state,action | Switch2Pos
input | Armament Panel | 704 | ARM_STATION2 | Station 2 Selector Switch | default_2_position_tumb |  | DCS-BIOS | 0x8500 |  | fixed_step,set_state,action | Switch2Pos
input | Armament Panel | 705 | ARM_STATION3 | Station 3 Selector Switch | default_2_position_tumb |  | DCS-BIOS | 0x8500 |  | fixed_step,set_state,action | Switch2Pos
input | Armament Panel | 706 | ARM_STATION4 | Station 4 Selector Switch | default_2_position_tumb |  | DCS-BIOS | 0x8500 |  | fixed_step,set_state,action | Switch2Pos
input | Armament Panel | 707 | ARM_STATION5 | Station 5 Selector Switch | default_2_position_tumb |  | DCS-BIOS | 0x8500 |  | fixed_step,set_state,action | Switch2Pos
input | Armament Panel | 708 | ARM_FUNC_SEL | Weapon Function Selector Switch | multiposition_switch_limited | 7 | DCS-BIOS | 0x8500 |  | fixed_step,set_state | AnalogMultiPos
input | Armament Panel | 709 | ARM_MASTER | Master Armament Switch | default_2_position_tumb |  | DCS-BIOS | 0x8500 |  | fixed_step,set_state,action | Switch2Pos
input | Avionics | 720 | FUEL_EXT_BTN | Internal-External Fuel Switch | default_button |  | DCS-BIOS | 0x8512 |  | fixed_step,set_state,action | Switch2Pos
input | Radar Scope | 721 | RADAR_PROFILE | Radar Terrain Clearance Switch | default_2_position_tumb |  | DCS-BIOS | 0x8500 |  | fixed_step,set_state,action | Switch2Pos
input | Radar Scope | 722 | RADAR_RANGE | Radar Range Switch | default_2_position_tumb |  | DCS-BIOS | 0x8502 |  | fixed_step,set_state,action | Switch2Pos
input | Avionics | 723 | MASTER_TEST | Master Test Switch | default_button |  | DCS-BIOS | 0x8512 |  | fixed_step,set_state,action | Switch2Pos
input | BDHI | 724 | BDHI_MODE | BDHI Switch | multiposition_switch_limited |  | DCS-BIOS | 0x8502 |  | fixed_step,set_state | Switch3Pos
input | Armament Panel | 725 | SHRIKE_SEL_KNB | Shrike Selector Knob | multiposition_switch_limited | 5 | DCS-BIOS | 0x8502 |  | fixed_step,set_state | SwitchMultiPos
input | Armament Panel | 726 | MISSILE_VOL | Shrike/Sidewinder Volume Knob | default_axis_limited |  | DCS-BIOS | 0x8506 |  | set_state,variable_step | AnalogInput
input | Armament Panel | 740 | AWRS_QUANT | AWRS Quantity Selector Switch | multiposition_switch_limited | 12 | DCS-BIOS | 0x8502 |  | fixed_step,set_state | AnalogMultiPos
input | Armament Panel | 742 | AWRS_DROP_INT | AWRS Drop Interval Knob | default_axis_limited |  | DCS-BIOS | 0x8504 |  | set_state,variable_step | AnalogInput
input | Armament Panel | 743 | AWRS_MULTI | AWRS Multiplier Switch | default_2_position_tumb |  | DCS-BIOS | 0x8500 |  | fixed_step,set_state,action | Switch2Pos
input | Armament Panel | 744 | AWRS_MODE | AWRS Mode Selector Switch | multiposition_switch_limited | 6 | DCS-BIOS | 0x8502 |  | fixed_step,set_state | AnalogMultiPos
input | Avionics | 827 | ALT_PRESS_KNB | Altimeter Pressure | default_axis |  | DCS-BIOS | 0x8516 |  | variable_step | AnalogInput
input | Avionics | 853 | AOA_INDEX_DIM | AoA Indexer Dimming Wheel | default_axis_limited |  | DCS-BIOS | 0x851A |  | set_state,variable_step | AnalogInput
input | Avionics | 885 | IAS_INDEX_BTN | IAS Index | default_button_axis |  | DCS-BIOS | 0x8512 |  | fixed_step,set_state,action | PushSetKnob
input | Gunsight | 891 | GUNSIGHT_DAY_NIGHT | Gunsight Day-Night Switch | default_2_position_tumb |  | DCS-BIOS | 0x8512 |  | fixed_step,set_state,action | Switch2Pos
input | Gunsight | 892 | GUNSIGHT_KNB | Gunsight Elevation Control | default_movable_axis |  | DCS-BIOS | 0x851E |  | set_state,variable_step | AnalogInput
input | Gunsight | 895 | GUNSIGHT_BRIGHT | Gunsight Light Control | default_axis |  | DCS-BIOS | 0x851C |  | variable_step | AnalogInput
input | TACAN | 900 | TACAN_MODE | AN/ARN-52 TACAN Mode Switch | multiposition_switch_limited | 4 | DCS-BIOS | 0x8512 |  | fixed_step,set_state | SwitchMultiPos/enc/ladder
input | TACAN | 901 | TACAN_CHAN_MAJ | TACAN Channel 10s | multiposition_switch_limited | 13 | DCS-BIOS | 0x8512 |  | fixed_step,set_state | AnalogMultiPos(>7)
input | TACAN | 902 | TACAN_CHAN_MIN | TACAN Channel 1s | multiposition_switch_limited | 10 | DCS-BIOS | 0x8512 |  | fixed_step,set_state | AnalogMultiPos(>7)
input | TACAN | 903 | TACAN_VOL | TACAN Volume | default_axis_limited |  | DCS-BIOS | 0x8520 |  | set_state,variable_step | AnalogInput
input | T Handles | 1240 | EMERG_GEAR_REL | Emergency Landing Gear Release Handle | default_2_position_tumb |  | DCS-BIOS | 0x8532 |  | fixed_step,set_state,action | Switch2Pos
input | T Handles | 1241 | EMERG_BOMB_REL | Emergency Stores Release Handle | default_2_position_tumb |  | DCS-BIOS | 0x853E |  | fixed_step,set_state,action | Switch2Pos
input | T Handles | 1242 | MAN_FLIGHT_CONTROL | Manual Flight Control Handle | default_2_position_tumb |  | DCS-BIOS | 0x853E |  | fixed_step,set_state,action | Switch2Pos
input | T Handles | 1243 | EMERG_GEN_DEPLOY | Emergency Generator Release Handle | default_2_position_tumb |  | DCS-BIOS | 0x853E |  | fixed_step,set_state,action | Switch2Pos
output | AFCS [AFCS_HDG] |  | AFCS_HDG_100S | AFCS Heading 100's | gauge |  | DCS-BIOS | 0x8476 | 65535 |  | NeedleGauge
output | AFCS [AFCS_HDG] |  | AFCS_HDG_10S | AFCS Heading 10's | gauge |  | DCS-BIOS | 0x8478 | 65535 |  | NeedleGauge
output | AFCS [AFCS_HDG] |  | AFCS_HDG_1S | AFCS Heading 1's | gauge |  | DCS-BIOS | 0x847A | 65535 |  | NeedleGauge
output | AFCS |  | AFCS_PITCH | AFCS Pitch Gauge | gauge |  | DCS-BIOS | 0x8552 | 65535 |  | NeedleGauge
output | AFCS |  | AFCS_ROLL | AFCS Roll Gauge | gauge |  | DCS-BIOS | 0x854E | 65535 |  | NeedleGauge
output | AFCS |  | AFCS_YAW | AFCS Yaw Gauge | gauge |  | DCS-BIOS | 0x8550 | 65535 |  | NeedleGauge
output | AOA Indicator |  | AOA_GREEN | AOA Indexer (green) | LED |  | DCS-BIOS | 0x8470 | 1 |  | LED
output | AOA Indicator |  | AOA_RED | AOA Indexer (red) | LED |  | DCS-BIOS | 0x8470 | 1 |  | LED
output | AOA Indicator |  | AOA_YELLOW | AOA Indexer (yellow) | LED |  | DCS-BIOS | 0x8470 | 1 |  | LED
output | Advisory Lights |  | D_ADVISORY_DIVE | Dive Light (yellow) | LED |  | DCS-BIOS | 0x8470 | 1 |  | LED
output | Advisory Lights |  | D_ADVISORY_INRANGE | In Range Light (yellow) | LED |  | DCS-BIOS | 0x8470 | 1 |  | LED
output | Advisory Lights |  | D_ADVISORY_SETRANGE | Set Range Light (yellow) | LED |  | DCS-BIOS | 0x8470 | 1 |  | LED
output | ApproachPowerCompensator |  | APC_LIGHT | APC Indicator Light (red) | LED |  | DCS-BIOS | 0x8470 | 1 |  | LED
output | Armament Panel |  | AWRS_POWER | AWRS Power Indicator Light (yellow) | LED |  | DCS-BIOS | 0x8470 | 1 |  | LED
output | BDHI [BDHI] |  | BDHI_DME_00X | BDHI nnX | gauge |  | DCS-BIOS | 0x846A | 65535 |  | NeedleGauge
output | BDHI [BDHI] |  | BDHI_DME_0X0 | BDHI nXn | gauge |  | DCS-BIOS | 0x8468 | 65535 |  | NeedleGauge
output | BDHI [BDHI] |  | BDHI_DME_FLAG | BDHI Flag | gauge |  | DCS-BIOS | 0x8464 | 65535 |  | NeedleGauge
output | BDHI [BDHI] |  | BDHI_DME_X00 | BDHI Xnn | gauge |  | DCS-BIOS | 0x8466 | 65535 |  | NeedleGauge
output | BDHI [BDHI] |  | BDHI_HDG | BDHI Heading | gauge |  | DCS-BIOS | 0x845E | 65535 |  | NeedleGauge
output | BDHI [BDHI] |  | BDHI_ILS_GS | BDHI ILS GS | gauge |  | DCS-BIOS | 0x846C | 65535 |  | NeedleGauge
output | BDHI [BDHI] |  | BDHI_ILS_LOC | BDHI ILS LOC | gauge |  | DCS-BIOS | 0x846E | 65535 |  | NeedleGauge
output | BDHI [BDHI] |  | BDHI_NEEDLE1 | BDHI Needle 1 | gauge |  | DCS-BIOS | 0x8460 | 65535 |  | NeedleGauge
output | BDHI [BDHI] |  | BDHI_NEEDLE2 | BDHI Needle 2 | gauge |  | DCS-BIOS | 0x8462 | 65535 |  | NeedleGauge
output | Clock [CURRTIME] |  | CURRTIME_HOURS | Current Hours | gauge |  | DCS-BIOS | 0x84E0 | 65535 |  | NeedleGauge
output | Clock [CURRTIME] |  | CURRTIME_MINS | Current Minutes | gauge |  | DCS-BIOS | 0x84E2 | 65535 |  | NeedleGauge
output | Clock [CURRTIME] |  | CURRTIME_SECS | Current Seconds | gauge |  | DCS-BIOS | 0x84E4 | 65535 |  | NeedleGauge
output | Clock [STOPWATCH] |  | STOPWATCH_MINS | Stopwatch Minutes | gauge |  | DCS-BIOS | 0x84E6 | 65535 |  | NeedleGauge
output | Clock [STOPWATCH] |  | STOPWATCH_SECS | Stopwatch Seconds | gauge |  | DCS-BIOS | 0x84E8 | 65535 |  | NeedleGauge
output | Countermeasures [CM_BANK1] |  | CM_BANK1_0X | CM Bank 1 1's | gauge |  | DCS-BIOS | 0x84C8 | 65535 |  | NeedleGauge
output | Countermeasures [CM_BANK1] |  | CM_BANK1_X0 | CM Bank 1 10's | gauge |  | DCS-BIOS | 0x84C6 | 65535 |  | NeedleGauge
output | Countermeasures [CM_BANK2] |  | CM_BANK2_0X | CM Bank 2 1's | gauge |  | DCS-BIOS | 0x84CC | 65535 |  | NeedleGauge
output | Countermeasures [CM_BANK2] |  | CM_BANK2_X0 | CM Bank 2 10's | gauge |  | DCS-BIOS | 0x84CA | 65535 |  | NeedleGauge
output | Doppler Nav |  | APN153_DRIFT_GAUGE | Drift Gauge | gauge |  | DCS-BIOS | 0x847C | 65535 |  | NeedleGauge
output | Doppler Nav [APN153_SPEED] |  | APN153_SPEED_00X | Speed nnX | gauge |  | DCS-BIOS | 0x8482 | 65535 |  | DrumDisplay
output | Doppler Nav [APN153_SPEED] |  | APN153_SPEED_0X0 | Speed nXn | gauge |  | DCS-BIOS | 0x8480 | 65535 |  | DrumDisplay
output | Doppler Nav [APN153_SPEED] |  | APN153_SPEED_X00 | Speed Xnn | gauge |  | DCS-BIOS | 0x847E | 65535 |  | DrumDisplay
output | Doppler Nav [ASN41_MAGVAR] |  | ASN41_MAGVAR_0000X | MagVar nnnnX | gauge |  | DCS-BIOS | 0x84C4 | 65535 |  | NeedleGauge
output | Doppler Nav [ASN41_MAGVAR] |  | ASN41_MAGVAR_000X0 | MagVar nnnXn | gauge |  | DCS-BIOS | 0x84C2 | 65535 |  | NeedleGauge
output | Doppler Nav [ASN41_MAGVAR] |  | ASN41_MAGVAR_00X00 | MagVar nnXnn | gauge |  | DCS-BIOS | 0x84C0 | 65535 |  | NeedleGauge
output | Doppler Nav [ASN41_MAGVAR] |  | ASN41_MAGVAR_0X000 | MagVar nXnnn | gauge |  | DCS-BIOS | 0x84BE | 65535 |  | NeedleGauge
output | Doppler Nav [ASN41_MAGVAR] |  | ASN41_MAGVAR_X0000 | MagVar Xnnnn | gauge |  | DCS-BIOS | 0x84BC | 65535 |  | NeedleGauge
output | Doppler Nav [ASN41_WINDDIR] |  | ASN41_WINDDIR_00X | Wind Direction nnX | gauge |  | DCS-BIOS | 0x84BA | 65535 |  | NeedleGauge
output | Doppler Nav [ASN41_WINDDIR] |  | ASN41_WINDDIR_0X0 | Wind Direction nXn | gauge |  | DCS-BIOS | 0x84B8 | 65535 |  | NeedleGauge
output | Doppler Nav [ASN41_WINDDIR] |  | ASN41_WINDDIR_X00 | Wind Direction Xnn | gauge |  | DCS-BIOS | 0x84B6 | 65535 |  | NeedleGauge
output | Doppler Nav [ASN41_WINDSPEED] |  | ASN41_WINDSPEED_00X | Windspeed nnX | gauge |  | DCS-BIOS | 0x84B4 | 65535 |  | NeedleGauge
output | Doppler Nav [ASN41_WINDSPEED] |  | ASN41_WINDSPEED_0X0 | Windspeed nXn | gauge |  | DCS-BIOS | 0x84B2 | 65535 |  | NeedleGauge
output | Doppler Nav [ASN41_WINDSPEED] |  | ASN41_WINDSPEED_X00 | Windspeed Xnn | gauge |  | DCS-BIOS | 0x84B0 | 65535 |  | NeedleGauge
output | Doppler Nav Destination [NAV_DEST_LAT] |  | NAV_DEST_LAT_0000X | Destination Latitude nnnnX | gauge |  | DCS-BIOS | 0x84A2 | 65535 |  | NeedleGauge
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

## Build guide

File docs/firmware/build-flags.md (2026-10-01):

# Build Flags

Every OpenSkyhawk firmware project is configured by `-D` flags in its `platformio.ini`. There are
**32 of them**, and they come from three different places. That mixed provenance is the first
thing to understand, because it decides who you have to convince before you change one:

| Group | Count | Changing one is… |
|---|---|---|
| [**Ours — behavioural**](#ours-behavioural-13) | 13 | a local decision — we own the code that reads it |
| [**Third-party, set by us**](#third-party-set-by-us-7) | 7 | **not** a local decision — STM32duino, arduino-pico, and DCS-BIOS own these |
| [**Test seams**](#test-seams-12) | 12 | bench-only — never present in a shipped build |

This page is an inventory: what each flag defaults to, where it's set, and where it's read. Deep
per-flag semantics live in the library READMEs under `Firmware/Libraries/` and in
`Firmware/ScratchPad/TechSpec/`. When a table here and a header disagree, **the header wins** —
and the [grep recipe](#re-verifying-this-page) at the bottom will tell you which.

For a working `platformio.ini` with the common flags in context, see
[PlatformIO Setup](platformio-setup.md). If you are building a panel right now, start with the
next section instead — the tables below are reference, not a checklist.

## Starting a new panel

You copied `Firmware/Templates/PanelGroup/` and you're looking at its `build_flags`. Here is what
to do with each line. The [walkthrough](../guides/new-panel-group.md) covers the surrounding steps;
this is just the flags.

### Required — set these or the build fails

| Flag | What to set |
|---|---|
| `NODE_ID` | Your board's unique CAN address, 1–63, claimed from the registry in `Firmware/NODE_IDS.md` — see [NODE_ID & CAN Addressing](node-id.md). **No default.** Omitting it is a compile error, not a silent fallback. |
| `HAL_CAN_MODULE_ENABLED` | Nothing — keep it as-is. STM32duino does not enable the bxCAN HAL driver by default, so without this line there is no CAN driver to link against. |

### Already correct in the template — keep, don't tune

| Flag | Why to leave it alone |
|---|---|
| `HSE_VALUE=8000000` | Already matches both your board's crystal and the framework's own F1 default. Change it only if your board genuinely carries a different crystal — and if you do, get it right first time: a wrong value is **undetectable at runtime** (see the warning below). |
| `USB_NONE` | Inert. It documents that CAN owns PA11/PA12; it does not enforce it. Harmless to keep, harmless to drop. |

### Add only if your panel needs them

| Flag | Add when |
|---|---|
| `I2C_TIMEOUT_TICK=10` | Your panel has I²C devices (MCP23017, ADS1115, OLEDs) — shortens the stall when one is absent or miswired. |
| `SHIFTBUS_SCK` / `MISO` / `MOSI` / `LOAD` / `LATCH` | You are relocating the shift-register bus off its default pins. Otherwise leave all five out. |
| `SHIFTBUS_ISR_HZ` | You want timer-ISR sampling for encoder feel instead of polled sampling. |
| `SERIAL_RX_BUFFER_SIZE=256` | **PanelBridge only.** A PanelGroup has no use for it. |
| `NODE_HEALTH_TELEM=0` | You specifically want health telemetry **off**. It is on by default — omitting the line does not disable it. |

### Never in a panel

`FORCE_CLOCK_FALLBACK`, `PINREF_DEBUG`, `NODE_OVERHEAT_C`, and any `*_TEST` seam. These are bench
and debug instruments. If one appears in a panel's `platformio.ini`, it is a mistake — see
[Test seams](#test-seams-12) and [Deliberate non-defaults](#deliberate-non-defaults) for what each
actually does.

## Ours — behavioural (13)

| Flag | Default | Set where | Read at |
|---|---|---|---|
| `NODE_ID` | none — omitting it fails to compile | every STM32 env that links our libraries; `WiringCheck` omits it deliberately | `CANProtocol.cpp:200`, `PanelGroup.cpp:391`, `STM32Board.h:29` |
| `PANELBRIDGE_NODE_STATUS` | off | on in `Templates/PanelBridge` | `PanelBridge.cpp:42` + ~10 more |
| `NODE_HEALTH_TELEM` | **on** | never set | `PanelBridge.cpp:510`, `PanelGroup.cpp:399` |
| `NODE_OVERHEAT_C` | **unset — by design** | bench envs only | `CANProtocol.cpp:400`, `PanelGroup.cpp:409` |
| `FORCE_CLOCK_FALLBACK` | off | `Tests/STM32Board` env `test_adc_clock_fallback` | `STM32Board.cpp:179` |
| `PINREF_DEBUG` | off | never set | `PinRef.cpp:8` + ~9 more |
| `SHIFTBUS_SCK` | `PB3` | never set | `ShiftBus.cpp:13` |
| `SHIFTBUS_MISO` | `PB4` | never set | `ShiftBus.cpp:16` |
| `SHIFTBUS_MOSI` | `PB5` | never set | `ShiftBus.cpp:19` |
| `SHIFTBUS_LOAD` | `PB8` | never set | `ShiftBus.cpp:22` |
| `SHIFTBUS_LATCH` | `PB9` | never set | `ShiftBus.cpp:25` |
| `SHIFTBUS_ISR_HZ` | unset → polled sampling | `Tests/ShiftBus`, `=1000` | `PanelGroup.cpp:125,240` |
| `SHIFTBUS_ISR_TIM` | `TIM2` | never set | `PanelGroup.cpp:241` |

**What they do, briefly.** `NODE_ID` is the board's CAN address — see
[NODE_ID & CAN Addressing](node-id.md). `PANELBRIDGE_NODE_STATUS` makes PanelBridge report which
PanelGroup nodes it can see, up to the host over DCS-BIOS. `NODE_HEALTH_TELEM` is the periodic
health frame (die temperature, fault bitmap) at half the heartbeat rate.
`FORCE_CLOCK_FALLBACK` exercises the dead-crystal fault path without a dead crystal; the
`test_adc_clock_fallback` env uses it to prove `SystemClock_Config` sets the ADC prescaler on its
fault path as well as its verified-72 MHz path (#263).
`PINREF_DEBUG` adds assertions to the pin abstraction. The `SHIFTBUS_*` pin flags relocate the
shift-register bus off its default SPI1-remap pins; `SHIFTBUS_ISR_HZ` switches that bus from
polled to timer-ISR sampling (encoder feel) on the timer named by `SHIFTBUS_ISR_TIM`.

!!! warning "Set `NODE_ID` in `platformio.ini`, never in `main.cpp`"
    A `#define NODE_ID` in a sketch is invisible to library translation units — `CANProtocol` and
    `PanelGroup` are compiled separately. That mistake is caught at build time rather than
    shipped: those TUs include `STM32Board.h`, whose file-scope `static_assert` fails with
    `error: 'NODE_ID' was not declared in this scope`. There is no default and no silent
    fallback — the undefined-evaluates-to-zero rule applies inside `#if`, not in a
    `static_assert` expression.

    Sketches that link none of those libraries are the only exception: the standalone
    `Examples/E2E_DCS_Test/WiringCheck` env omits `-DNODE_ID` deliberately, because it is a raw
    GPIO/ADC diagnostic with no OpenSkyhawk libraries at all.

    Note that `0` is a legal value — it is PanelBridge's reserved address. It is just never
    correct for a PanelGroup node.

### Deliberate non-defaults

Three of the above look like oversights and are not. They are choices, and this is the record of
them:

!!! note "`NODE_OVERHEAT_C` is unset on purpose — OVERHEAT never raises in a shipped build"
    The STM32's internal die-temperature sensor is **uncalibrated**. Rather than ship a threshold
    nobody has field data for, the overheat bit is computed only when a build defines
    `NODE_OVERHEAT_C` — and **no shipped environment defines it**: not the templates, not
    `Panels/Center_Armament`, not the E2E examples. The `OVERHEAT` flag in the node-health frame is
    therefore never set on any real cockpit node.

    Two bench environments force it deliberately, and only to exercise the path:
    `Tests/CANProtocol` sets `=0` (any reading trips it, to test overheat and degraded coexisting)
    and `Tests/PanelGroup` sets `=20` (a room-temperature node reports overheat, to test the
    client's rendering). Enabling it for real is a one-line `-DNODE_OVERHEAT_C=N` once someone has
    calibration data. See `FirmwarePlan/00-decisions.md`.

!!! note "`NODE_HEALTH_TELEM` is ON by default — disable with `=0`, not by omission"
    It's the only flag in this group that's on when absent (`#if !defined(X) || (X)`). Leaving it
    out gets you health telemetry; you need an explicit `-DNODE_HEALTH_TELEM=0` to turn it off.

!!! note "`PANELBRIDGE_NODE_STATUS` is off in the library but on in every shipped PanelBridge"
    The library defaults it off, so the table above says "off" — but the PanelBridge template
    enables it, and so does the E2E example. Every build you would actually flash to a cockpit
    has it on. (Most of the 13 `Tests/PanelBridge` envs leave it off; they are testing other
    things.) The client half is already released, which is why the default flipped in the
    template rather than in the library.

## Third-party, set by us (7)

These belong to **STM32duino**, **arduino-pico**, and the **DCS-BIOS** library. We only set them —
we don't own the code that reads them, and a framework update can move a default out from under
us. Two of these have already cost real debugging time.

| Flag | Framework default | Set where | Read at |
|---|---|---|---|
| `HAL_CAN_MODULE_ENABLED` | **not** enabled | every STM32 env that links our libraries; `WiringCheck` omits it deliberately | `stm32f1xx_hal_conf_default.h:321` |
| `HSE_VALUE` | already `8000000U` on F1 | `=8000000` in all templates, panels and examples, plus the CAN/board tests; 13 library-test envs omit it — harmlessly, since it equals the default | `stm32f1xx_hal_conf_default.h:86` |
| `SERIAL_RX_BUFFER_SIZE` | `64` | PanelBridge envs, `=256` | `Serial.h:44` |
| `I2C_TIMEOUT_TICK` | `100` | one E2E PanelGroup env, `=10` | `Wire/src/utility/twi.c:51` |
| `USB_NONE` | *no such macro* | 10 `platformio.ini` files | **nowhere** — see below |
| `USE_TINYUSB` | off | every RP2040 env | arduino-pico `platformio-build.py:242,325` |
| `DCSBIOS_DEFAULT_SERIAL` | off | `#define` in the sketch, not `-D` | `PanelBridge.cpp:11` |

`HAL_CAN_MODULE_ENABLED` is genuinely required: CAN is absent from STM32duino's default-enabled
HAL module list, so without our `-D` there is no bxCAN driver to link against.
`SERIAL_RX_BUFFER_SIZE=256` gives PanelBridge room for DCS-BIOS export bursts on UART2.
`I2C_TIMEOUT_TICK=10` shortens the Wire library's stall when an I²C device is absent.
`DCSBIOS_DEFAULT_SERIAL` is the odd one out — it's `#define`d at the top of the sketch's
`main.cpp` rather than passed as `-D`, because `PanelBridge.cpp` has to include `DcsBios.h`
*without* it and then restore it, to avoid an ODR violation.

!!! warning "`HSE_VALUE` does not select HSE — and it already matches the framework default"
    `-DHSE_VALUE=8000000` tells HAL what the crystal is. It does **not** switch the clock tree to
    it, and `8000000U` is already what STM32duino defaults the F1 to, so the flag changes nothing
    on its own. What actually selects HSE is `STM32Board`'s strong override of
    `SystemClock_Config` (`STM32Board.cpp:164`), which every OpenSkyhawk STM32 node links.
    Without it, the variant runs HSI-PLL at 64 MHz → APB1 32 MHz → CAN at 444 kbps against a
    500 kbps bus.

    The corollary: a **wrong-value** crystal is undetectable at runtime. `HAL_RCC_Get*Freq()`
    derives from the compile-time `HSE_VALUE`, not from a measurement, so a 12 MHz part would
    compute as 72 MHz while really running 108. Correct crystal value is a BOM guarantee.

!!! warning "`USE_TINYUSB` is required for HID — omitting it silently builds the wrong USB stack"
    On RP2040 this selects TinyUSB in place of the default Pico stack. `Adafruit_TinyUSB.h` and
    SimGateway's whole HID backend depend on it. The arduino-pico builder branches on it in two
    places; without it the project still compiles, which is what makes it expensive to diagnose.

!!! note "`USB_NONE` is inert — nothing reads it"
    It appears on 25 lines across 10 `platformio.ini` files and has **no effect**. STM32duino has
    no such macro: its "USB support: None" board option sets nothing at all, and only the CDC and
    HID options add defines. Nothing in the framework, the PlatformIO builder, or our code reads
    `USB_NONE`.

    The intent behind it is real, though. On the F103, USB D+/D− are PA11/PA12 — exactly the pins
    the CAN transceiver uses, so CAN genuinely does own them and USB must stay off. **What keeps
    it off is that `USBCON` is never defined, and no build config or source under `Firmware/`
    defines it.** The flag documents the decision; it does not enforce it.

## Test seams (12)

Each of these widens a library's visibility so its on-target tests can assert against internal
state. **A seam never changes shipped behaviour, and no shipped environment defines one** — each
is set only by its own `Firmware/Tests/<Library>/platformio.ini`.

| Flag | Library it opens | First read at |
|---|---|---|
| `ANALOGINPUT_TEST` | AnalogInput | `Inputs/AnalogInput/AnalogInput.h:85` |
| `ANALOGMULTIPOS_TEST` | AnalogMultiPos | `Inputs/AnalogMultiPos/AnalogMultiPos.h:90` |
| `DRUMDISPLAY_TEST` | DrumDisplay | `DrumDisplay/DrumDisplay.h:279` |
| `LED_TEST` | LED | `Outputs/LED/LED.h:68` |
| `MULTIPOS_TEST` | MultiPosInput | `Inputs/MultiPosInput/MultiPosInput.h:60` |
| `NEEDLEGAUGE_TEST` | NeedleGauge | `Outputs/NeedleGauge/NeedleGauge.h:78` |
| `PANELBRIDGE_TEST` | PanelBridge | `PanelBridge/PanelBridge.h:84` |
| `ROTARYENCODER_TEST` | RotaryEncoder | `Inputs/RotaryEncoder/RotaryEncoder.h:108` |
| `SHIFTBUS_TEST` | ShiftBus | `Helpers/ShiftBus/ShiftBus.h:141` |
| `SIMGATEWAY_TEST` | SimGateway | `SimGateway/SimGateway.cpp:11` (no-op HID stubs) |
| `STEPPERMOTOR_TEST` | StepperMotor | `Drivers/StepperMotor/StepperMotor.h:158` |
| `STM32BOARD_TEST` | STM32Board | `STM32Board/STM32Board.h:32` |

Paths are relative to `Firmware/Libraries/`, and the PanelGroup ones to
`Firmware/Libraries/PanelGroup/`. Most seams are read in several places; the column gives the
first, which is where the guarded block starts.

Two test projects set a second library's seam because they drive it: `Tests/NeedleGauge` also sets
`STEPPERMOTOR_TEST`, and `Tests/AnalogMultiPos` also sets `MULTIPOS_TEST`. Five test projects have
no seam of their own at all — `Tests/PinRef`, `Tests/CANProtocol`, `Tests/NodeStatus`,
`Tests/Switch2Pos` and `Tests/PanelGroup` test through the public API.

`SIMGATEWAY_TEST` is the one that does more than widen visibility: it swaps the real HID backend
for no-op stubs so SimGateway logic can be tested without a USB host.

## Re-verifying this page

Rather than trust the tables, re-derive them. Run both blocks from the repo root — **their union
must be 32**. If it isn't, this page is stale.

Be clear about what that proves. Both lists come from greps of the same shape, so the union
check catches **drift** — a flag added, removed, or renamed after this page was written. It does
not prove the inventory is **complete**: a flag consumed in some way neither grep looks for would
be missed by the check exactly as it was missed by the page. Treat 32 as the current count, not a
guarantee.

```bash
grep -rhE '^[^;#]*-D[A-Za-z_]' --include=platformio.ini Firmware | sed -E 's/[;#].*//' | grep -oE '[[:space:]]-D[A-Za-z_][A-Za-z0-9_]*' | sed 's/.*-D//' | sort -u
```

That's every flag **set** by some environment — 22 of them.

```bash
grep -rhoE '#[[:space:]]*(ifdef|ifndef|if|elif)[^A-Za-z_]*defined[^A-Za-z_]*[A-Za-z_][A-Za-z0-9_]*|#[[:space:]]*(ifdef|ifndef)[[:space:]]+[A-Za-z_][A-Za-z0-9_]*' --include='*.h' --include='*.cpp' Firmware/Libraries | grep -oE '[A-Za-z_][A-Za-z0-9_]*$' | sort -u | grep -vE '^(ARDUINO_ARCH_|STM32F1xx$|ATEMP$|guard$|_)'
```

That's every flag **read** by a library conditional — 25 of them. The trailing filter drops
architecture macros, the `ATEMP` pin macro, and internal include guards; none are build flags.

The two lists deliberately don't match, and the differences are the interesting part:

- **Set but not read** — `NODE_ID` (used as a *value*, `canIdEvt(NODE_ID)`, never in a
  conditional) plus the six framework flags, which are read inside STM32duino and arduino-pico
  rather than in our tree.
- **Read but never set** — the nine flags whose defaults always apply in every committed
  environment (the five ShiftBus pins, `SHIFTBUS_ISR_TIM`, `NODE_HEALTH_TELEM`,
  `FORCE_CLOCK_FALLBACK`, `PINREF_DEBUG`), plus `DCSBIOS_DEFAULT_SERIAL`, which is `#define`d in
  sketch source instead of passed as `-D`.

To check the `USB_NONE` claim specifically, both of these must return nothing:

```bash
grep -rn 'USBCON\|USBD_USE_' Firmware
```

```bash
grep -rn 'USB_NONE' ~/.platformio/platforms ~/.platformio/packages/framework-arduinoststm32
```

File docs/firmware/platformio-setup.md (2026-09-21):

# PlatformIO Setup

OpenSkyhawk firmware builds with [PlatformIO](https://platformio.org/). Each board is its own
project. Start from the templates in `Firmware/Templates/` — **not** from an existing panel's
`platformio.ini`, which may carry stale dependencies.

## Start from a template

`Firmware/Templates/` has a ready project per tier: `PanelGroup/`, `PanelBridge/`, and
`SimGateway/`. Copy the one you need into place (a PanelGroup goes under
`Firmware/Panels/<YourPanel>/`) and edit its `platformio.ini`.

## A PanelGroup platformio.ini, annotated

```ini
[env:PanelGroup]
platform = ststm32@^20.0.0        ; major held on purpose — see note below
board = genericSTM32F103C8        ; STM32F103C8 for nodes (see board note below)
framework = arduino
board_build.f_cpu = 72000000L

build_flags =
    -DNODE_ID=1                   ; unique per board, 1–63 — set this!
    -DHAL_CAN_MODULE_ENABLED      ; enable the bxCAN peripheral
    -DUSB_NONE                    ; inert — USB is off because USBCON is never defined
    -DHSE_VALUE=8000000           ; external 8 MHz crystal, required for CAN timing

lib_extra_dirs = ${PROJECT_DIR}/../../Libraries
lib_ldf_mode = deep+              ; needed so Adafruit BusIO finds framework headers
lib_deps =
    HIDControls
    STM32Board
    PanelGroup
    CANProtocol
    A4EC
    blemasle/MCP23017@^2.0.0
    adafruit/Adafruit ADS1X15@^2.0.0

upload_protocol = stlink
monitor_speed = 115200
```

The two build flags people forget: **`-DNODE_ID`** (every board needs a unique value — see
[NODE_ID & CAN Addressing](node-id.md)) and **`-DHSE_VALUE=8000000`** (declares the 8 MHz
crystal frequency to HAL — needed for correct CAN timing, since the internal RC oscillator
isn't accurate enough for 500 kbps CAN). Note `-DHSE_VALUE` does *not* by itself select HSE;
`STM32Board`'s `SystemClock_Config` does that (see [Design Decisions](../architecture/design-decisions.md)).

`-DUSB_NONE` is a label, not a switch — nothing in STM32duino or PlatformIO reads it. USB really is
off, and CAN really does own PA11/PA12 (they're the F103's USB D+/D− pins), but what keeps USB off
is that `USBCON` is never defined. Leave the flag in place as documentation of the decision.

For every flag in this file — plus the ones that aren't, their defaults, and where each is read —
see [Build Flags](build-flags.md).

!!! warning "Keep the version constraint"
    The `@^20.0.0` is deliberate — don't drop it back to a bare `platform = ststm32`. An
    unconstrained platform resolves to whatever is newest at build time, so an upstream release
    lands in your build with no change on our side. That is exactly how the weekly firmware build
    went red for two weeks: `ststm32` 20.0.0 arrived with STM32 Arduino core **3.0.0**, which
    renamed the `HardwareSerial` class (see below), and every STM32 project stopped compiling.

    The caret accepts 20.x — new boards and Cube HAL patches still flow in — but blocks the next
    major, which is where a break of that kind comes from. Crossing a major is a deliberate change:
    do it in a PR, with a full build behind it.

!!! note "Declaring your own UART: use `Uart`, not `HardwareSerial`"
    Core 3.0.0 adopted ArduinoCore-API. The concrete STM32 serial class is now **`Uart`**, and the
    name `HardwareSerial` refers to the abstract `arduino::HardwareSerial` base — you cannot
    instantiate it. A second UART is declared `Uart Diag(PA10, PA9);`. Most sketches never need
    this: `STM32Board::diagSerial()` already hands you USART1 on the DiagSerial header.
    On the RP2040 side (SimGateway) the arduino-pico core is unaffected — `HardwareSerial` is
    still the concrete class there.

!!! note "Which STM32 variant"
    Per the [variant policy](../getting-started/prerequisites.md), **all** STM32 boards default to
    **`genericSTM32F103C8`** (64 KB) — both PanelGroup nodes and **PanelBridge**. PanelBridge
    carries the full DCS-BIOS input map yet still compiles to ~26 KB flash, so it fits the C8
    comfortably. **`genericSTM32F103CB`** (128 KB) is a drop-in fallback (identical LQFP48
    footprint) for any future build that ever exceeds 64 KB — no board currently needs it. Note:
    the in-tree `Templates/PanelGroup` should target `genericSTM32F103C8`.

## Flashing

STM32 boards flash over **SWD with an ST-Link** (`upload_protocol = stlink`). PlatformIO drives
the probe directly — `pio run -t upload`. SimGateway (RP2040) flashes over USB by UF2 or
straight from PlatformIO; no ST-Link.

If an upload fails — old ST-Link firmware, or a clone's non-standard tap ID — see
[Flashing → ST-Link troubleshooting](../guides/flashing.md#st-link-troubleshooting).

## Serial monitor

`monitor_speed = 115200` matches the **DiagSerial** debug stream (USART1, PA9/PA10). Attach a
USB-to-TTL adapter to the board's 3-pin debug header and `pio device monitor`. See
[Debugging on STM32](debugging.md).

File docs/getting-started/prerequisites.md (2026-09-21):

---
status: new
---

# What You'll Need

What you need depends on what you're here to do. Pick your path — you don't need the
build or firmware toolchain just to understand the project.

This page lists the tools and skills. It does **not** cover installation — setup steps live
in the [build guides](../guides/index.md).

## To understand the project

You can read the whole site and follow the architecture with nothing installed. To actually
*see* OpenSkyhawk drive a cockpit, you need:

- **[DCS World](https://www.digitalcombatsimulator.com/)** with the **A-4E-C Skyhawk
  Community Mod** installed. The A-4E-C is a free community module — OpenSkyhawk targets it
  specifically.
- **A DCS-BIOS relay** — something to bridge the sim and the SimGateway serial port.
  Two options:
    - **[OpenSkyhawk Client](client-app.md)** *(recommended)* — cross-platform GUI, auto-detects
      the SimGateway, adds live monitoring and replay. Download from
      [GitHub Releases](https://github.com/OpenSkyHawk/SkyHawkClient/releases).
    - **DCS-BIOS serial relay** — the legacy `connect-serial-port.cmd` / `socat` script
      shipped with DCS-BIOS. Windows-only, no GUI, requires manual COM port selection.
- **Basic electronics familiarity** — you should be comfortable with the idea of a
  microcontroller, a serial link, and reading a schematic. You do not need to know CAN bus,
  DCS-BIOS, or STM32 development going in; the docs explain those.

## To build a panel

Fabricating and wiring a panel adds the hardware toolchain:

| Tool | Use | Notes |
|---|-----|---|
| **[KiCad](https://www.kicad.org/)** 8+ | PCB schematic + layout review | Project tooling and CI use **v10.0.1**; open the `.kicad_pro` projects under `PCB/` |
| **[PlatformIO](https://platformio.org/)** + **[VS Code](https://code.visualstudio.com/)** | Firmware build and upload | The firmware build system — see [PlatformIO Setup](../firmware/platformio-setup.md) |
| **ST-Link** (or compatible SWD probe) | Flashing STM32 boards over SWD | The hardware probe. STM32 boards expose a 5-pin SWD header (PA13/PA14/NRST/GND/3.3V); PlatformIO flashes through it directly. Probe firmware must be **V2J24 or newer** — [update it](../guides/flashing.md#st-link-troubleshooting) if uploads fail |
| **[DCS-BIOS](https://github.com/DCS-Skunkworks/dcs-bios)** | DCS ↔ cockpit export stream | Runs on the PC; the firmware speaks its protocol |
| **[JLCPCB](https://jlcpcb.com/) account** | PCB fabrication | Design rules are pre-loaded for JLCPCB's standard 2-layer service |
| **Soldering iron + multimeter** | Assembly and bring-up | Surface-mount rework; continuity and voltage checks |

**CAD (evaluation in progress)** is optional for panel building:

- **Fusion 360 or FreeCAD** — CAD tooling is currently being evaluated (FreeCAD is the
  preferred direction). The `CAD/` sources open in whichever tool is chosen.
- Either tool can open and export **STEP** files for the KiCad fit-check.
- **STL** files for 3D printing are released via **GitHub Releases**, not committed to the repo.

!!! note "RP2040 boards need no special flasher"
    The SimGateway and any HID boards run on off-the-shelf RP2040 modules (e.g. a Raspberry
    Pi Pico). They flash over USB by drag-and-drop UF2 or directly from PlatformIO — no
    ST-Link required. Only the STM32 boards need the SWD programmer.

!!! note "STM32CubeProgrammer is optional"
    [STM32CubeProgrammer](https://www.st.com/en/development-tools/stm32cubeprog.html)
    is ST's standalone GUI flasher — handy for erasing or inspecting a chip, but not
    required. PlatformIO drives the ST-Link directly for normal build-and-upload.

## To contribute firmware

Everything above, plus the bench hardware to develop and verify against real boards:

- **STM32F103 dev board** — an STM32F103C8 Blue Pill is the default for every board and runs
  all of the firmware, including **PanelBridge** (its full DCS-BIOS input map still compiles to
  ~26 KB flash). The **STM32F103CB** (128 KB flash) is a drop-in fallback on the same footprint
  for any future build that exceeds 64 KB — no board currently needs it. Either way the
  firmware requires an **external 8 MHz crystal** for CAN; verify your board has one
  populated.
- **RP2040 module** (Raspberry Pi Pico or similar) — for SimGateway work.
- **USB-to-TTL serial adapter** — for the DiagSerial debug stream. Every STM32 board exposes
  a 3-pin header (GND / RX / TX) on **USART1 at 115200 baud** for human-readable diagnostics.
- **ST-Link** (or compatible SWD probe) — for flashing and debugging STM32 targets.
- **CAN bus analyzer** — *optional but useful*. Lets you watch frames on the bus directly
  when debugging multi-node behaviour.

See [How to Contribute](../contributing/index.md) for conventions, and
[Adding a New Panel Group](../guides/new-panel-group.md) for the end-to-end workflow.

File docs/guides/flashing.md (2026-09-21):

# Flashing Firmware

How to get firmware onto a board. STM32 boards use an ST-Link over SWD; RP2040 boards use USB.
PlatformIO drives both.

## STM32 (PanelBridge, PanelGroup) — ST-Link over SWD

Every custom STM32 board exposes a 5-pin SWD header (PA13/PA14/NRST/GND/3.3 V). Connect an
ST-Link and:

```bash
pio run -t upload          # build + flash the default env
pio run -e PanelGroup -t upload   # a specific env
```

`upload_protocol = stlink` is already set in the templates. No separate flasher GUI is needed —
PlatformIO drives the probe directly (STM32CubeProgrammer is optional). See
[PlatformIO Setup](../firmware/platformio-setup.md).

### ST-Link troubleshooting

!!! warning "Upload fails with 'only supports deprecated HLA'?"
    The ST-Link's own firmware is too old — PlatformIO's OpenOCD needs **V2J24 or newer**, and
    many clones ship older. Update the probe with ST's free
    [STSW-LINK007](https://www.st.com/en/development-tools/stsw-link007.html) updater: plug the
    ST-Link in on its own, click **Open in update mode**, then **Upgrade**, and replug.
    On macOS the updater needs Java (`brew install --cask temurin`); without it the app closes
    as soon as it opens.

!!! warning "Clone reports 'tap not found'?"
    Many Blue Pill clones use JTAG ID `0x2ba01477` (standard is `0x1ba01477`) and ST-Link
    refuses to connect. Uncomment the override in `platformio.ini`:

    ```ini
    upload_flags =
        -c
        set CPUTAPID 0
    ```

    Use `0`, not the clone's actual ID. `0` disables the ID check outright. Setting it to
    `0x2ba01477` gets past the initial check but has been observed to fail part-way through
    the write — the projects under `Firmware/Tests/` all use `0` for this reason.

## RP2040 (SimGateway) — USB

No ST-Link needed, but **put the board into BOOTSEL by hand first**: hold BOOTSEL while plugging
it in (or while tapping RESET), and wait for the `RPI-RP2` drive to appear. Then either:

- **From PlatformIO:** `pio run -t upload`, or
- **By hand:** drag the built `.uf2` onto the `RPI-RP2` drive.

!!! warning "`pio run -t upload` cannot reset the board for you"
    Every SimGateway project builds with `-DUSE_TINYUSB`, which replaces the Pico core's USB
    stack — and the 1200-baud-touch auto-reset goes with it. Without a manual BOOTSEL,
    `picotool` finds no device in bootloader mode and the upload fails.

    Anything holding the CDC port open also blocks the upload — close SkyHawkClient, serial
    monitors, and any browser HID/serial page before flashing. An orphaned Electron process
    is enough to keep the port claimed; check with `lsof /dev/cu.usbmodem*` if BOOTSEL alone
    doesn't fix it.

## After flashing

Watch the board come up on DiagSerial (115200) and check the status LED. See
[Bring-Up & Testing](bring-up.md) and [Debugging on STM32](../firmware/debugging.md).

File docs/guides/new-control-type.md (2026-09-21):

# Adding a New Control Type

Most input and output [control types](../firmware/control-types.md) are specified but not yet
implemented (Phase 4 inputs, Phase 5 outputs). If your panel needs one that doesn't exist, you
may be the one writing it. This guide is the pattern; the per-class spec lives in the
FirmwarePlan TechSpec.

!!! note "Read the spec first"
    Each control type has a detailed specification in the project's TechSpec (value encoding,
    debounce, polling rate, edge cases). Implement to the spec — don't improvise behaviour.
    Before writing a new class, check whether it only changes an existing class's *source* (inputs)
    or *sink* (outputs) — then it's a subclass in that class's family, not a new class. Names
    follow `dcs-bios-arduino-library` where an equivalent exists (`RotaryAcceleratedEncoder` extends
    `RotaryEncoder`; the planned `Dimmer` and `IntegerOutput` extend `AnalogOutput`).

## Where it goes

Control classes live in the **`PanelGroup`** library (`Firmware/Libraries/PanelGroup/`). Inputs
derive from the input base, outputs from the output base.

## The pattern

- **Self-registration.** Constructors register the object into a static linked list — the
  sketch just declares globals; `PanelGroup::loop()` walks the list. No manual registration.
- **Take a `PinRef`, not a raw pin.** Support GPIO / MCP23017 / ADS1115 backends through
  `PinRef`. PWM/servo outputs must check `isGpio()` (only direct GPIO can do PWM).
- **Inputs fire a `ControlPacket`** via `CANProtocol::sendBatched(canIdEvt(NODE_ID), pkt)` — the
  `controlId` (passed to your constructor) decides routing, not the class. Honour the batch
  flush rules (slot B `0x0000`; flush a half-full batch within two `loop()` iterations).
- **Outputs receive `CTRL_BCAST` packets** dispatched by `PanelGroup::loop()`; pick out your
  value by address + mask.
- **Normalise analog to 16-bit (0–65535)** at the source — no rescaling downstream.

## Value encoding and PanelBridge dispatch

Inputs send a numeric `value`; PanelBridge maps it to a DCS-BIOS argument by **dispatch type**
(`SWITCH`, `ACTION`, `ENCODER`, `ACCEL_ENCODER`, `MULTIPOS`). When you add an input class, decide
which dispatch type it uses and make sure the generator/input-map handles it — see
[DCS-BIOS Integration](../firmware/dcsbios-integration.md).

## Tests

Every control type ships with a test project under `Firmware/Tests/`. Add one that exercises the
value semantics and edge cases from the spec, on real hardware where the type needs it.

## Then document it

Update [Control Types](../firmware/control-types.md): move the type from "Planned" to
implemented, and add an example. Honesty in the status table matters.

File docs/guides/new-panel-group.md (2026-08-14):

# Adding a New Panel Group

A panel group is one STM32 CAN node serving one area of the cockpit. This is the step-by-step
for adding one. The [Adding a Controller](../contributing/adding-controller.md) page is the
overview; this is the recipe.

## Step 1 — Claim a NODE_ID

**Always first.** Open `Firmware/NODE_IDS.md`, take the next free number (currently **2**), and
add your row (panel group, console, status). Commit it in the same PR that starts the work.
NODE_IDs are permanent — never reuse one. See [NODE_ID & CAN Addressing](../firmware/node-id.md).

## Step 2 — Create the firmware project

Copy `Firmware/Templates/PanelGroup/` to `Firmware/Panels/<YourPanel>/`. In `platformio.ini`:

- Set `-DNODE_ID=N` to the number you just claimed.
- Set `board` per the [variant policy](../firmware/platformio-setup.md) — `genericSTM32F103C8`
  is the default for every board.

Leave the template's other `build_flags` alone unless you know why you're changing one.
[Build Flags → Starting a new panel](../firmware/build-flags.md#starting-a-new-panel) goes through
the template line by line: which you must set, which are already right, which to add only if your
panel needs them, and which must never appear in a panel.

Don't copy an existing panel's `platformio.ini` — use the template.

## Step 3 — Write the wiring map and controls

At the top of `main.cpp`, define a **wiring map** — one named `PinRef` per physical connection,
matching your schematic net labels:

```cpp
const PinRef PIN_MASTER_ARM(PB5);
const PinRef PIN_GEAR_LED(PB0);
```

Then declare control objects, choosing each control's routing — DCS-BIOS (`DCSIN_*`) or HID
(`CTRL_*`). The decision rule is on [DCS-BIOS vs HID](../architecture/dcsbios-vs-hid.md):

```cpp
OpenSkyhawk::Switch2Pos masterArm(DCSIN_ARM_MASTER, PIN_MASTER_ARM);
OpenSkyhawk::LED        gearLed  (A_4E_C_GEAR_LIGHT, A_4E_C_GEAR_LIGHT_AM, PIN_GEAR_LED);
```

`setup()` calls `PanelGroup::setup()`; `loop()` calls `PanelGroup::loop()`. See
[Your First Panel](first-panel.md) for the minimal shape and [Control Types](../firmware/control-types.md)
for the full catalogue.

!!! note "Most control types aren't implemented yet"
    Today only `LED` and `Switch2Pos` exist. If your panel needs another type, you may be
    implementing it — see [Adding a New Control Type](new-control-type.md).

## Step 4 — Design the PCB

Scaffold the KiCad project with `/new-kicad-project`, capture the schematic, lay out the board.
See [KiCad Workflow](../hardware/kicad-workflow.md) and [PCB Design Rules](../hardware/pcb-design-rules.md).
Order it via [PCB Ordering](pcb-ordering.md).

## Step 5 — Build, flash, bring up

[Assemble](assembly.md) the board, [flash](flashing.md) it, and [bring it up](bring-up.md)
against the bus and DCS.

## Step 6 — Open the PR

Branch `feat/<panel>`, keep it focused, make sure CI passes. Include the `NODE_IDS.md` change.
See [Design Conventions](../contributing/conventions.md).

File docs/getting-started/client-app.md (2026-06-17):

---
status: new
---

# OpenSkyhawk Client

**OpenSkyhawk Client** is the recommended way to connect your cockpit to DCS. It is a
cross-platform GUI that is both the bridge and the monitor — auto-detecting the SimGateway,
relaying the DCS-BIOS stream both ways, and surfacing live connection, aircraft, and
telemetry status.

The alternative is the legacy `connect-serial-port.cmd` / `socat` relay shipped with
DCS-BIOS. That script still works but is Windows-only, has no UI, and requires selecting the
COM port manually. The client replaces it on both Windows and macOS.

Download from [GitHub Releases](https://github.com/OpenSkyHawk/SkyHawkClient/releases).
Windows (`.exe` installer) and macOS (`.dmg`) builds are provided.

!!! note "Windows SmartScreen"
    The installer is currently unsigned. Click **More info → Run anyway** when Windows
    SmartScreen prompts. This is expected for an open-source project without a code-signing
    certificate.

## Source modes

The client runs in one of three modes, selected on the Connection tab:

| Mode | What it does | Use when |
|---|---|---|
| **Bridge** | Relays DCS-BIOS between the sim and the SimGateway serial port. Also reads the HID joystick interface. | Flying with the cockpit connected. |
| **Monitor** | Reads the DCS-BIOS stream off the LAN with no device attached. Relay and HID are inactive. | Inspecting the stream from a second machine, or testing without hardware. |
| **Replay** | Feeds a recorded capture file into the parser and UI with no DCS running. Optionally writes the replay to a connected SimGateway. | Bench-testing panels, debugging without the sim. |

## Getting started

1. Launch the app and go to the **Connection** tab.
2. Select **Bridge**, **Monitor**, or **Replay** mode.
3. In **Bridge** or **Monitor** mode, set the DCS host and transport:
    - *Loopback multicast* — DCS on the same machine as the client (default).
    - *TCP to host* — DCS on a separate PC; enter `<DCS-PC-IP>:7778`. No script needed on
      the DCS host — just open Windows Firewall for inbound TCP 7778.
    - *Unicast listen* — if you've edited `BIOSConfig.lua` to send a unicast export.
4. Press **Start relay** (Bridge/Monitor) or **Start** (Replay).

## Tabs

### Connection

Where you choose how to connect and watch the link come up. The **device card** shows the
auto-detected SimGateway — identity (*A-4E Skyhawk*), USB **VID/PID `0x2E8A / 0x4134`**, the
serial port (`scanning…` until the device is found), the **CDC serial + HID** interfaces, and
a **Relaying / Stopped** indicator. An **Auto-reconnect** toggle re-opens the port
automatically if the cockpit is unplugged and replugged.

!!! tip "Reading the SimGateway LEDs"
    The gateway board has two status LEDs you can read at a glance: **green solid** = DCS-BIOS
    data flowing, **green slow blink** = connected but idle, **red solid** = no PC connected,
    **red fast blink** = a UART link fault. See
    [SimGateway → Status LEDs](../architecture/sim-gateway.md#status-leds) for the full table.

The **Source Mode**, **DCS Link** (host + transport), and **Record** controls live on this
tab too — covered under [Getting started](#getting-started) and
[Recording and replay](#recording-and-replay).

A **Connected nodes** card lists the PanelGroup controllers reported over the CAN bus — node
id, uptime, receive count, and bus-health flags (BOFF / EPVF / TEC / REC). This is **Bridge
mode only** and depends on a firmware node-reporting feature still in progress, so it
currently shows *"No nodes reported"* until that firmware ships.

### Overview

The landing tab — a single glance confirms the cockpit is alive. Three status tiles across
the top show **Link** (idle / connecting / connected), **Aircraft** (the live module name —
from `_ACFT_NAME` metadata, or inferred from the address range when metadata is absent), and
**DCS Link** (the active transport and host).

**Sim Telemetry** below is five live gauges — **RPM, IAS (kt), Flap, Press Alt (ft), Fuel** —
with a command-activity readout alongside (`commands/sec · total · last command sent`). A
gauge reads **—** for any value the sim isn't exporting.

At the bottom, **Stream Health** tracks the relay itself: **Bytes In / Bytes Out** (each
direction), **Frames/s**, parse **Errors**, **Uptime**, and **Reconnects**.

If a non-A-4E module loads, an amber **warning banner** appears — named decode is A-4E-C only,
but **relaying and stats continue** and the log falls back to raw addresses.

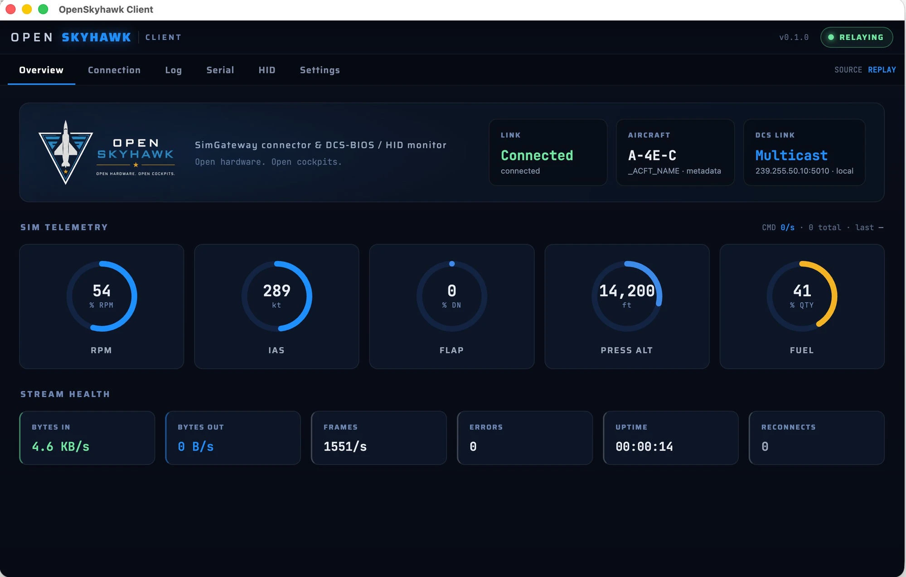
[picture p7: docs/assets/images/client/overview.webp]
Overview tab showing telemetry gauges with A-4E-C connected via multicast


### Log

A decoded DCS-BIOS event stream — control name, address, value, and direction — updated live.
Filter by name or address, pause autoscroll, clear the buffer, export to TSV, or toggle raw
hex mode.

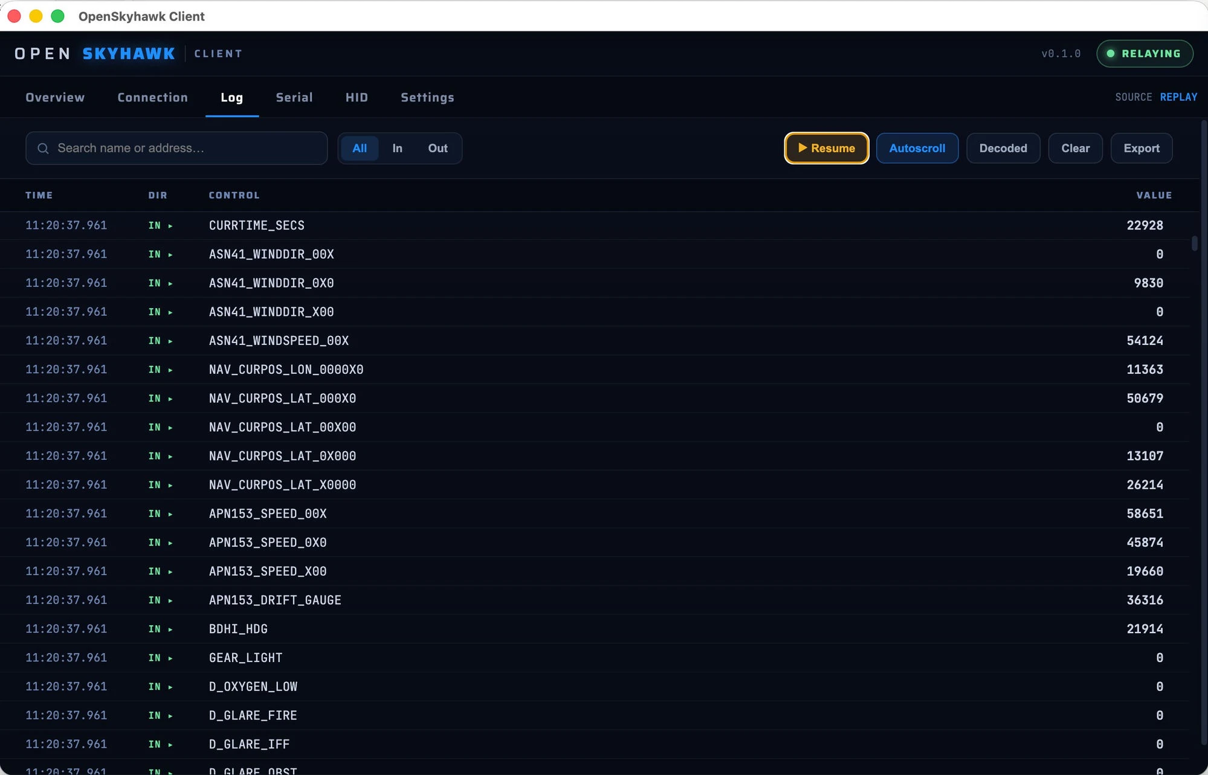
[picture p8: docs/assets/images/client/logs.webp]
Log tab showing decoded DCS-BIOS control names and values


### HID

Live status of every axis, button, and hat switch on the SimGateway's HID interface, plus the
**report rate**. Reports are sent on change, so the panel shows an **idle** state ("no recent
report") when nothing is moving. Useful for verifying the SimGateway is outputting the correct
values before binding in DCS.

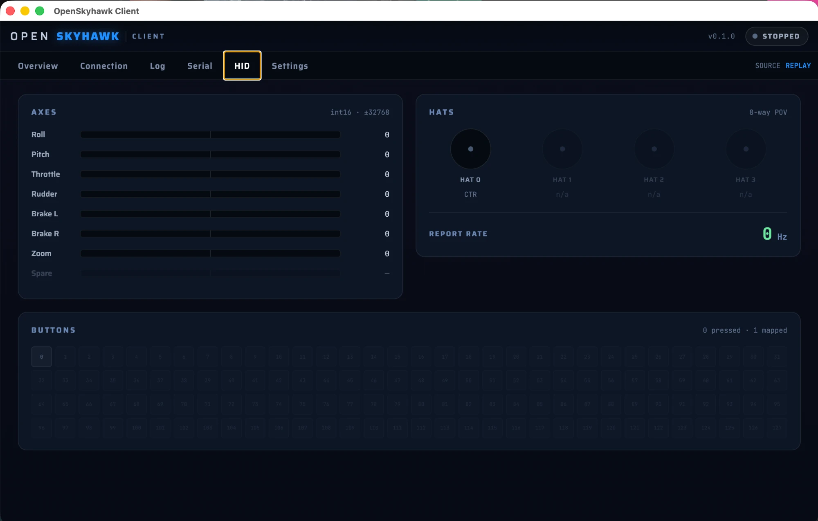
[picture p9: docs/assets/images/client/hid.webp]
HID tab showing axes, hats, and button grid


### Serial

Raw TX/RX hex + ASCII monitor for the CDC serial link (Bridge mode only). Toggle it on to
watch the DCS-BIOS byte stream directly, or to confirm the SimGateway is receiving commands.

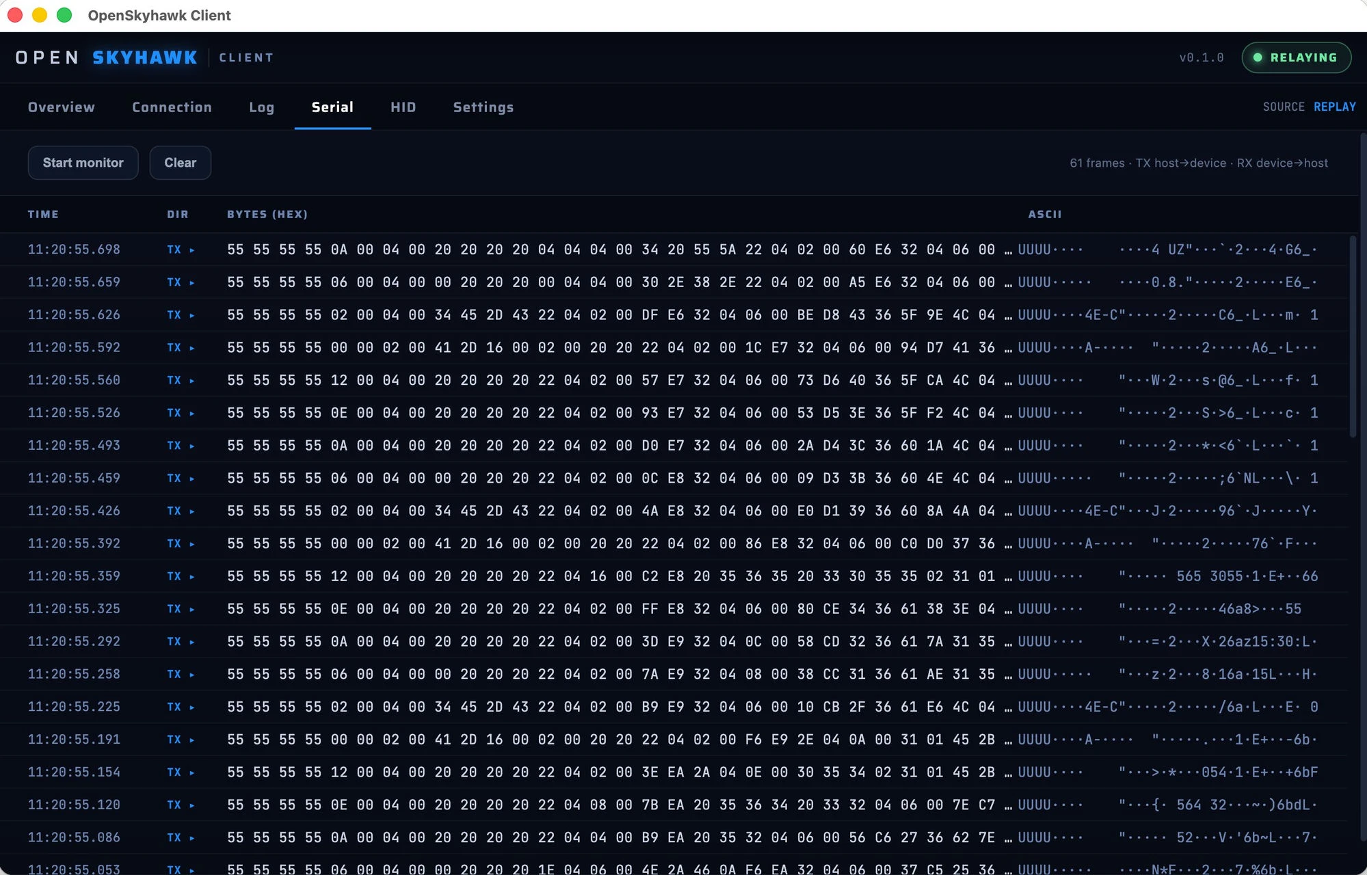
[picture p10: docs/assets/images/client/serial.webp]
Serial tab showing raw DCS-BIOS frames as hex and ASCII


### Settings

Developer and diagnostic controls: debug logging toggle (writes `<userData>/debug.log`),
serial port dump (logs all detected ports and their metadata), and a Reveal button to open
the log file. Most users will never need this tab.

## Recording and replay

While relaying in Bridge or Monitor mode, the **Record** card on the Connection tab lets you
capture the live DCS-BIOS stream to a `.json` file. Stop recording to save. The file can
then be loaded in Replay mode on any machine — no DCS or SimGateway required. Useful for
reproducing a specific flight state on the bench or sharing a session for debugging.

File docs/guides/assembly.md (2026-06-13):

# Assembly & Soldering

How an OpenSkyhawk board goes from bare PCB to populated and inspected. The part choices are all
deliberately reflow-and-inspect friendly, so a hobbyist setup handles them.

!!! note "Photos coming"
    This guide is text-complete but the step-by-step photos are still being produced — image
    placeholders are marked **(photo TBD)**.

## What you need

- Soldering iron (fine tip) and/or a **T962 reflow oven** with solder paste and a stencil
- Multimeter (continuity + voltage)
- Flux, solder wick, tweezers, magnification for inspection

## Why everything is inspectable

Every package on these boards is chosen so the joints are **visible after reflow** — SOIC, SSOP,
TSSOP, HTSSOP, LQFP, SOT-23/223, through-hole. No QFN/DFN/BGA. That means you can verify every
critical joint by eye (and the HTSSOP thermal pad by continuity). See
[Hardware Standards](../hardware/standards.md).

## Placement

- **LEDs on the front face; everything else on the back** — ICs, passives, connectors, MOSFETs.
- Through-hole connectors are vertical and accessible from the panel side.
- *(photo TBD — populated front and back)*

## Order of work

1. **Paste + reflow the back-side SMD** (ICs, passives, MOSFETs, regulator). *(photo TBD)*
2. **Inspect** every joint — bridges, tombstones, the AMS1117 and any HTSSOP thermal pad
   (continuity-check the pad to GND). *(photo TBD)*
3. **Hand-solder through-hole** — connectors, headers, crystal.
4. **Front-side LEDs** last (5050 strings; mind the anode notch — the chamfered corner is the
   anode on the project's 5050 part).
5. **Power-on check before anything else** — verify the 3.3 V rail and look for shorts before
   the first flash. Continue at [Bring-Up & Testing](bring-up.md).

## Connectors & harnesses

Crimp harnesses per the [Connector & Harness Guide](../hardware/connectors.md) — Molex Mini-Fit
Jr for power/bus, JST-XH for signal. 24 AWG throughout.

!!! warning "Don't power a board you haven't inspected"
    A solder bridge on the 3.3 V rail can take out the regulator or the MCU. Inspect and
    continuity-check first, then power.

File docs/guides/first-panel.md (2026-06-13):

# Your First Panel

The fastest way to understand OpenSkyhawk is to run the reference example. `E2E_DCS_Test` is a
minimal, working PanelGroup sketch — **one LED and one switch**, wired to real A-4E-C DCS-BIOS
IDs. Get this blinking and you understand the whole input/output path.

## What it does

The example lives at `Firmware/Examples/E2E_DCS_Test/PanelGroup/`. The entire sketch:

```cpp
#include <OpenSkyhawk.h>

const PinRef PIN_LED(PC13);   // dev-board built-in LED (active-LOW) — use an external LED in production
const PinRef PIN_BTN(PB0);    // pushbutton to GND; 10 kΩ pull-up to 3.3V

OpenSkyhawk::LED        gearLight (A_4E_C_GEAR_LIGHT, A_4E_C_GEAR_LIGHT_AM, PIN_LED, /*reverse=*/true);
OpenSkyhawk::Switch2Pos masterTest(DCSIN_MASTER_TEST, PIN_BTN);

void setup() {
    STM32Board::setDebug(true);
    PanelGroup::setup();
}

void loop() {
    PanelGroup::loop();
}
```

Two control objects, declared at global scope (they self-register), and a two-line
`setup()`/`loop()`. That's a panel.

- **Output:** `gearLight` watches the DCS-BIOS gear-light address (`A_4E_C_GEAR_LIGHT` + its mask
  `_AM`) and drives the LED. `reverse=true` because the dev-board LED is active-LOW.
- **Input:** `masterTest` reads the button and fires the compact `DCSIN_MASTER_TEST` command — in
  DCS, holding Master Test illuminates the gear light, so pressing the button lights the LED
  through the full round trip.

## Wiring

| Signal | Pin | Notes |
|---|-----|---|
| LED | PC13 | dev-board built-in, active-LOW (use an external LED + resistor on a real panel) |
| Button | PB0 | other side to GND; **10 kΩ pull-up to 3.3 V** |

## Run it

1. Open `Firmware/Examples/E2E_DCS_Test/PanelGroup/` in PlatformIO.
2. Confirm `-DNODE_ID=1` in `platformio.ini` (this example is NODE 1).
3. Flash over ST-Link — see [Flashing Firmware](flashing.md).
4. Watch DiagSerial at 115200 (`STM32Board::setDebug(true)` is on) — see
   [Debugging on STM32](../firmware/debugging.md).
5. With the full stack (PanelBridge + SimGateway) connected and DCS-BIOS running, press the
   button: the LED follows Master Test. See [Bring-Up & Testing](bring-up.md).

## Then go further

You've now seen the two halves — an `LED` output and a `Switch2Pos` input, routed by their IDs.
To build your own panel group from here, follow
[Adding a New Panel Group](new-panel-group.md). For what each control class can do, see
[Control Types](../firmware/control-types.md).

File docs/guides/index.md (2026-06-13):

# Build Guides

The how-to section: step-by-step recipes for getting hardware built, flashed, and talking to
DCS. Where the [reference sections](../firmware/index.md) explain *what* things are, these
guides walk you through *doing* them.

## Start here

- **[Your First Panel](first-panel.md)** — the end-to-end walkthrough using the working
  `E2E_DCS_Test` example: one LED, one switch, real DCS-BIOS IDs. Do this first.

## Building a panel

- **[PCB Ordering (JLCPCB)](pcb-ordering.md)** — export fab files and place an order
- **[Assembly & Soldering](assembly.md)** — populate and inspect a board
- **[Flashing Firmware](flashing.md)** — get firmware onto STM32 and RP2040 boards
- **[Bring-Up & Testing](bring-up.md)** — first power-on through a verified DCS connection

## Extending the project

- **[Adding a New Panel Group](new-panel-group.md)** — a new CAN node, NODE_ID first
- **[Adding a New Control Type](new-control-type.md)** — a new input/output firmware class

!!! note "Some guides are partial"
    The assembly and bring-up guides need real build photos, which are still being produced —
    photo placeholders are marked TBD. Kit-specific assembly lives separately under
    [Kit Assembly](../kits/index.md).

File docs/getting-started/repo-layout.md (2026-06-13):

---
status: new
---

# Repo Layout

!!! warning "This reflects the target structure"
    The repository is being restructured. Some directories shown here are in the process of
    being moved, renamed, or created. This page describes the **target state** — where things
    are headed — so contributors orient against the intended layout, not transient cruft.

```
OpenSkyhawk/
├── .github/
│   └── workflows/          ← CI: docs, firmware, KiCad, A4EC generator
├── CAD/                    ← panel enclosures, bezels, knobs (scaffolded, early stage)
│   ├── Center_Console/
│   ├── Left_Console/
│   ├── Right_Console/
│   └── Shared/             ← reusable knobs, guards, light rings
├── Firmware/
│   ├── Examples/
│   │   └── E2E_DCS_Test/   ← working reference sketch (LED + Switch2Pos + real DCS-BIOS)
│   ├── Libraries/          ← production shared libraries
│   ├── Panels/             ← panel-group sketches (one folder per group)
│   ├── PanelBridge/        ← STM32 PanelBridge sketch
│   ├── SimGateway/         ← RP2040 SimGateway sketch
│   ├── Templates/          ← PlatformIO project templates for new boards
│   ├── Tests/              ← test projects
│   └── NODE_IDS.md         ← pointer to the NODE_ID registry docs
├── PCB/
│   ├── Center_Console/     ← KiCad projects, by console then controller group
│   ├── Left_Console/
│   ├── Right_Console/
│   └── Libraries/          ← shared symbols, footprints, sheet templates
├── docs/                   ← this MkDocs site (docs_dir = ".")
├── tools/
│   └── gen_a4ec/           ← Python A4EC DCS-BIOS header generator (maintainer tooling)
├── CONTRIBUTING.md
├── CODE_OF_CONDUCT.md
├── AGENTS.md
└── README.md
```

## Top-level directories

| Directory | What's in it |
|---|---|
| `.github/workflows/` | CI pipelines — docs build/deploy, firmware builds, KiCad ERC/DRC, and the A4EC generator. |
| `CAD/` | Panel enclosures, bezels, and shared printed parts. Source files committed; STL/STEP exports generated, not committed. Scaffolded, early stage. |
| `Firmware/` | All firmware — shared libraries, the three tier sketches, panel groups, templates, and tests. |
| `PCB/` | One KiCad project per physical board, organised by console then controller group. Shared parts live in `PCB/Libraries/`. |
| `docs/` | This documentation site. |
| `tools/gen_a4ec/` | The Python generator that turns A-4E-C DCS-BIOS definitions into firmware headers. Maintainer-only — see below. |

!!! note "CAD source vs exports"
    CAD source files (`.f3d` or `.FCStd`) are committed to the repo under `CAD/`. **STL and
    STEP exports are gitignored** and published via **GitHub Releases**. CAD tooling is
    currently being evaluated between Fusion 360 and FreeCAD.

## Key directories for contributors

Three places matter most if you're writing firmware:

- **`Firmware/Libraries/`** — the production shared code: `CANProtocol`, `STM32Board`,
  `HIDControls`, `PanelGroup`, `PanelBridge`, `SimGateway`, and the generated `A4EC` headers.
  This is the **authoritative source** for any constant or API. When docs and a header
  disagree, the header wins.
- **`Firmware/Examples/E2E_DCS_Test/`** — a working, hardware-verified reference sketch that
  exercises an LED output and a Switch2Pos input against real DCS-BIOS IDs. The best starting
  point for understanding a PanelGroup sketch end to end. It's used as the worked example in
  [Your First Panel](../guides/first-panel.md).
- **`Firmware/Templates/`** — PlatformIO project templates for PanelBridge, SimGateway, and
  PanelGroup. Start a new panel group by copying from here.

!!! warning "Don't copy a panel sketch as a template"
    Use `Firmware/Templates/` to start a new board — **not** an existing panel group's
    `platformio.ini`. Some in-tree panel sketches carry stale dependencies.

## A note on the A4EC generator

`tools/gen_a4ec/` parses the A-4E-C DCS-BIOS JSON and emits the `A4EC_*` headers committed
under `Firmware/Libraries/`. The generated headers are committed — **contributors do not run
the generator**. Refreshing it when a new A-4E-C release ships is a maintainer task. See the
maintainer documentation for that workflow.

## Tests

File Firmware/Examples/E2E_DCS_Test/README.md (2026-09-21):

# E2E_DCS_Test — live-DCS integration rig

A three-board chain that drives one live instance of **every control class** with real DCS-BIOS
data, both directions:

```
DCS ⇄ SimGateway (RP2040, USB↔UART) ⇄ PanelBridge (STM32 NODE 0, CAN master) ⇄ PanelGroup (NODE 1)
```

- **`SimGateway/`** — RP2040, transparent DCS-BIOS-ASCII relay. **Never re-flashed** for input work;
  it demuxes by frame type, not command content.
- **`PanelBridge/`** — STM32 NODE 0, `main` firmware (DcsBios + the #147 dispatch + collapsed map).
- **`PanelGroup/`** — STM32 NODE 1, the ongoing integration node. Outputs (Master-Test LED,
  APN-153 DRIFT needle, two OLED drums) were bench-verified 2026-06-15; the **inputs below were
  added for the #147 live-DCS acceptance**.

## Bench sketches (PanelGroup side)

| Sketch | Use |
|---|---|
| `PanelGroup/` | the full "every control class" node — needs **all** its hardware present (LED, stepper, mux + 2 OLEDs) |
| `PanelGroupInputs/` | inputs-only node (4 inputs, no outputs) — use when only the inputs are wired |
| `WiringCheck/` | standalone raw GPIO/ADC diagnostic (no CAN/sim) — verify input wiring before the full chain |

> **Gotcha — don't flash the full `PanelGroup` node with its OLEDs absent.** It drives the OLED
> DrumDisplays every loop; with the OLEDs unplugged, the live DCS export keeps triggering renders to
> the missing devices, each I2C transaction blocks on the HAL timeout, the loop stalls, and the node
> flaps online/offline (heartbeat starved). On a partial-hardware bench use `PanelGroupInputs`. The
> proper fix — a non-blocking circuit breaker so a dead I2C device can't stall the loop — is #164.

## Inputs under test (PanelGroup node)

The four DCS-routed input **dispatch forms**, end-to-end — and the first **real-pot → DCS** run for
the analog ABS classes (previously only `debugSetRaw`-seam-verified):

| Control | Class | Pins | Form | Frame | DCS reaction |
|---|---|---|---|---|---|
| `DEST_LAT_KNB` | `RotaryEncoder` REL | PA8 / PB5 | `±step` → `%+d` | `canIdEvtRel` | Destination-latitude knob steps |
| `ARC51_FREQ_10MHZ` | `RotaryEncoder` DIR | PB3 / PB4 | `±1` → `INC`/`DEC` | `canIdEvtDir` | 10 MHz digit steps (and the ch1 drum tracks it) |
| `ARC51_VOL` | `AnalogInput` | PA2 (pot) | 16-bit → `%u` | `canIdEvt` | ARC-51 volume sweeps |
| `ARC51_MODE` | `AnalogMultiPos` | PA3 (pot) | index → `%u` | `canIdEvt` | ARC-51 mode selector steps (4 positions) |

> **PB3 / PB4 are JTAG-DP pins.** `STM32Board::begin()` (inside `PanelGroup::setup()`) releases JTAG
> while keeping SWD (PA13/PA14), so they are plain GPIO and ST-Link still flashes. The node is already pin-dense (stepper coils
> on PA0/PA1/PA4/PA5, button PB0, mux PB8/PB9), so the DIR encoder lands on the remapped JTAG pair.

## Wiring (PanelGroup node side)

```
ENCODER REL  DEST_LAT_KNB (EC11)         ENCODER DIR  ARC51_FREQ_10MHZ (EC11)
  A  → PA8   + [10kΩ] → 3V3                A  → PB3   + [10kΩ] → 3V3   (JTAG pin, remapped)
  B  → PB5   + [10kΩ] → 3V3                B  → PB4   + [10kΩ] → 3V3   (JTAG pin, remapped)
  C  → GND                                 C  → GND
  switch pins ×2 → unconnected             switch pins ×2 → unconnected

POT 1  AnalogInput  ARC51_VOL (10kΩ)     POT 2  AnalogMultiPos  ARC51_MODE (10kΩ)
  end → 3V3 ,  wiper → PA2 ,  end → GND     end → 3V3 ,  wiper → PA3 ,  end → GND
  (no resistors)                           (no resistors)
```

**Pull-resistor rules:**
- **Encoders need 10 kΩ pull-UPs** on A and B → **3V3** (the class sets plain `INPUT`, no internal
  pull-up; an open contact would otherwise float). Common → GND. No pull-downs.
- **Pots need none** — a pot is already a divider. **High end → 3V3, not 5 V** (PA2/PA3 are ADC pins,
  *not* 5 V-tolerant; 5 V damages them).
- Direction only: if a knob turns the wrong way, swap that one's two signal pins (or pot end
  terminals); nothing else changes.

## Flash

| Board | Flash | Notes |
|---|---|---|
| PanelGroup STM32 (NODE 1) | `pio run -d Firmware/Examples/E2E_DCS_Test/PanelGroup -t upload` | this node, ~79 % of a C8 |
| PanelBridge STM32 (NODE 0) | `pio run -d Firmware/Examples/E2E_DCS_Test/PanelBridge -t upload` | DcsBios + #147 dispatch |
| SimGateway RP2040 | — | unchanged transparent relay |

CAN bus between the two STM32s, **120 Ω** terminator at each end, shared GND.

## Verify chain (per input)

1. **Node diag** (USART1 PA9/PA10, 115200): `[ENC] 0x… REL +3200` / `DIR +1`, `[ANA] …`, `[MUL] …`.
2. **Bridge diag** (its USART1): `[BRIDGE] DCS -> "DEST_LAT_KNB" "+3200"`.
3. **DCS cockpit**: the control in the table above moves. For DIR, the ch1 drum re-renders the new
   frequency — input and output close the loop on one node.

## Pass criteria

- **REL** — turning steps `DEST_LAT_KNB` smoothly both ways; `±3200` per detent (tune the ctor `step`
  for feel).
- **DIR** — steps the 10 MHz digit `INC`/`DEC`; **clamps at the band ends** (no wrap); a malformed
  value never moves it (bridge guards `±1`).
- **AnalogInput** — sweeping pot 1 moves volume continuously, settles without flicker.
- **AnalogMultiPos** — sweeping pot 2 steps cleanly through the 4 positions (deadband = no boundary
  flicker).
- **Preset-safety** — set a value in DCS, power-cycle the node: the encoders do **not** reset it on
  reconnect (relative, `forceReport()`-noop). The pots *do* re-assert on SYNC (absolute) — expected.

## Troubleshooting

- Wrong direction → swap that control's two signal pins (encoder A/B, or pot end terminals).
- One physical detent emits two EVTs → drop the encoder to `EncoderStepsPerDetent::Two`.
- Node not `CONNECTED` on the bridge → check CAN wiring + the 120 Ω terminators + a shared GND.

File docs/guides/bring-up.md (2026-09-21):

# Bring-Up & Testing

First power-on to a verified DCS connection, in order. Don't skip ahead — each step gates the
next. Use the [status LED](../firmware/debugging.md#the-status-led) and DiagSerial as your
instruments throughout.

!!! note "Photos coming"
    The textual procedure is complete; bench photos are still being produced — **(photo TBD)**.

## 1. Power and rails

Before flashing anything, power the board from the bench supply (or bus) and confirm:

- The **3.3 V rail** is at 3.3 V (AMS1117 output).
- No part is getting hot. If anything is, kill power — recheck assembly.

*(photo TBD — multimeter on the 3.3 V test point)*

## 2. Flash and watch the status LED

[Flash](flashing.md) the firmware, then read the bi-color status LED:

| LED | Meaning |
|-----|---|
| Red blinking | Booting / initialising |
| Green blinking | Normal — CAN bus healthy |
| Red fast blink | TEC > 0 — transmit errors |
| Red solid | Bus-off |
| Amber flicker | Warning / degraded |

Red-solid or red-fast on a single board usually means **no other node / no termination** — CAN
needs 120 Ω at the two end nodes. Confirm bus wiring before chasing firmware.

## 3. DiagSerial

Attach a USB-to-TTL adapter to the 3-pin debug header, open the monitor at **115200**. With
`STM32Board::setDebug(true)`, the board narrates boot, NODE_ID, and CAN status. Confirm the
NODE_ID matches what you claimed.

## 4. Join the bus

Connect PanelBridge and the SimGateway. On a healthy bus the node settles to **green blinking**.
PanelBridge broadcasts `SYNC_REQ`; the node completes its input poll and replies `READY`, then
re-sends its current input state. Gauge steppers home to position 0 at boot (mechanical-stop
homing) before any DCS data arrives — so no random needle motion.

## 5. End-to-end in DCS

Start DCS-BIOS export and load the A-4E-C. Then:

- **Outputs:** trigger the sim state (e.g. a caution light) and confirm the LED/gauge follows.
- **Inputs:** flip a switch and confirm the cockpit state changes in the sim.

The [E2E_DCS_Test](first-panel.md) example is the simplest case — Master Test lights the gear
light through the full loop.

## Troubleshooting

| Symptom | Likely cause |
|---|---|
| Red solid, single board | No bus partner / missing 120 Ω termination |
| Upload: "only supports deprecated HLA" | ST-Link firmware older than V2J24 — [update the probe](flashing.md#st-link-troubleshooting) |
| ST-Link "tap not found" | Clone JTAG ID — set `CPUTAPID 0` ([details](flashing.md#st-link-troubleshooting)) |
| Nothing on DiagSerial | `setDebug(false)`, wrong baud, or TX/RX swapped |
| Output never updates | DCS-BIOS export not running, or wrong `A_4E_C_*` address/mask |
| Input does nothing | Wrong `controlId` (DCS-BIOS vs HID), or pull-up missing |

!!! note "Full diagnostics reference"
    Heartbeats, error counters, and the `SYNC_REQ`/`READY` handshake are detailed under the CAN
    protocol — see [CAN Bus Protocol](../architecture/can-bus.md).

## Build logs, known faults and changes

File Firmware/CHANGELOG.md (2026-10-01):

# Changelog

## [0.1.0](https://github.com/OpenSkyHawk/OpenSkyhawk/compare/625e581f...firmware-v0.1.0) (2026-10-01)

### Features

* **firmware:** AnalogOutput family — abstract base, Dimmer and IntegerOutput ([#288](https://github.com/OpenSkyHawk/OpenSkyhawk/issues/288)) ([#301](https://github.com/OpenSkyHawk/OpenSkyhawk/issues/301)) ([b49fb91](https://github.com/OpenSkyHawk/OpenSkyhawk/commit/b49fb9157424a8779acf31b370d682cba13b8b2c))
* **firmware:** AngleSensorInput — absolute angle sensor on a PinRef ([#294](https://github.com/OpenSkyHawk/OpenSkyhawk/issues/294)) ([#303](https://github.com/OpenSkyHawk/OpenSkyhawk/issues/303)) ([11c31c0](https://github.com/OpenSkyHawk/OpenSkyhawk/commit/11c31c065be5a7dc4cb03a1dc76206b16153fc01))
* **firmware:** RotaryAcceleratedEncoder — DCS-BIOS-parity subclass of RotaryEncoder ([#287](https://github.com/OpenSkyHawk/OpenSkyhawk/issues/287)) ([#296](https://github.com/OpenSkyHawk/OpenSkyhawk/issues/296)) ([ce38c07](https://github.com/OpenSkyHawk/OpenSkyhawk/commit/ce38c076a12549ebbc97d3b7dba66be6b7df1e88))
* **firmware:** STM32Board releases JTAG at boot, keeping SWD ([#299](https://github.com/OpenSkyHawk/OpenSkyhawk/issues/299)) ([#300](https://github.com/OpenSkyHawk/OpenSkyhawk/issues/300)) ([9b4673f](https://github.com/OpenSkyHawk/OpenSkyhawk/commit/9b4673fe9cf3bce81fb120d8c3646edbc2be383d))
* **firmware:** SwitchWithCover2Pos — cover and switch from one pin ([#293](https://github.com/OpenSkyHawk/OpenSkyhawk/issues/293)) ([#311](https://github.com/OpenSkyHawk/OpenSkyhawk/issues/311)) ([9cad7d7](https://github.com/OpenSkyHawk/OpenSkyhawk/commit/9cad7d7ce5bd0d1fa166fb1cd1abb8a8fb6ae331))

### Bug Fixes

* **firmware:** harden StepperMotor recal and fix DrumDisplay decode ([#137](https://github.com/OpenSkyHawk/OpenSkyhawk/issues/137)) ([#313](https://github.com/OpenSkyHawk/OpenSkyhawk/issues/313)) ([f5930b5](https://github.com/OpenSkyHawk/OpenSkyhawk/commit/f5930b5cf8a3ec305681ac6eea4c4822727ca415))

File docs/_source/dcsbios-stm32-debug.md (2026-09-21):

# DCS-BIOS STM32 Debug Session Notes

Findings from initial DCS-BIOS integration testing with a Blue Pill prototype.
These notes apply to any STM32 node that will run DCS-BIOS — in this project
that is the **STM32 CAN master node**, not individual panel nodes like
Center_Armament.

## Architecture Context

Panel nodes (e.g. Center_Armament) are CAN-only. They never touch DCS-BIOS
directly. The data flow is:

```
PC ──USB CDC── RP2040 (gateway) ──UART── STM32 CAN master ──CAN bus── panel nodes
```

During prototyping, a Tiny2040 stood in for the RP2040 gateway and a Blue Pill
stood in for the STM32 CAN master. The bridge firmware (`DCS_BIOS_Bridge`) was
removed in the prototype cleanup — see git history if needed.

## Blue Pill (STM32F103C8T6) Gotchas

### JTAG ID — Chinese clone

Standard STM32 JTAG ID: `0x1ba01477`  
Chinese Blue Pill clone: `0x2ba01477`

ST-Link refuses to connect without overriding the ID. Add to `platformio.ini`:

```ini
upload_flags =
    -c
    set CPUTAPID 0
```

Use `0`, not the clone's ID: `0` disables the check outright, while `0x2ba01477` has been
observed to fail part-way through the write.

Flag ordering matters — the `-c set CPUTAPID` pair must appear before the
OpenOCD target config loads.

### USB CDC crashes under DCS-BIOS

`PIO_FRAMEWORK_ARDUINO_ENABLE_CDC` enables STM32 native USB. Under sustained
DCS-BIOS data flow the port crashes: socat exits with "Permission denied" and
the port is unusable until replug. This happened consistently — it is not a
fluke.

**Do not use STM32 USB CDC for DCS-BIOS.** Use UART and bridge via RP2040.

### UART1 redefinition conflicts

Attempting to remap `Serial` to `Serial1` (PA9/PA10) via `#define Serial
Serial1` causes "multiple definition of Serial2" compile errors or runtime
failures depending on the STM32duino version in use.

## What Works — UART2 + RP2040 Bridge

On `board = genericSTM32F103C8` with **no CDC flag**, `Serial` maps to
**UART2**:

| Object | UART | TX pin | RX pin |
|---|---|---|---|
| `Serial` | UART2 | PA2 | PA3 |

Required defines before `#include <DCSBIOS.h>`:

```cpp
#define DCSBIOS_FOR_STM32
#define DCSBIOS_DEFAULT_SERIAL
```

Baud rate: **250000** (fixed by DCS-BIOS protocol).

### Arduino Mega 2560 bridge wiring (used in this session)

STM32 UART2 connects to Mega UART1. Mega relays traffic between UART1 and
its USB Serial (`Serial` / UART0) at 250000 baud on both sides.

| Arduino Mega | Direction | STM32 |
|---|---|---|
| Pin 18 (TX1 / UART1) | → | PA3 (UART2 RX) |
| Pin 19 (RX1 / UART1) | ← | PA2 (UART2 TX) |
| GND | — | GND |

⚠️ STM32 is 3.3 V; Mega is 5 V. The STM32 RX pin (PA3) receives 5 V from
the Mega TX — this is out-of-spec for STM32 GPIO. It worked on the bench
but a 5 V→3.3 V voltage divider or level shifter on that line is recommended
for anything beyond a one-off proto session.

The Mega's TX line (Mega Pin 18 → STM32 PA3) drives 5 V into a 3.3 V input.

**Planned replacement:** Tiny2040 (or any RP2040 module) — both sides 3.3 V,
no level shifter needed.

### PC13 onboard LED

Active-low on Blue Pill:

```cpp
digitalWrite(PC13, LOW);   // on
digitalWrite(PC13, HIGH);  // off
```

## DCS-BIOS Verified Addresses

| Signal | Address | Mask | Shift |
|---|---|---|---|
| Master caution | `0x7408` | `0x0200` | 9 |

## Status at End of Session

- Connection stable under sustained DCS-BIOS flow (no drops vs. constant USB CDC crashes)
- Master caution LED toggled correctly on bench
- End-to-end verification in DCS (sim running) not yet done

## Open Concern — CAN Bus Under DCS-BIOS Load

Not yet tested. The STM32 CAN master must process incoming UART bytes from the
RP2040 and simultaneously handle CAN interrupts. Under high DCS-BIOS throughput,
UART buffer overrun or CAN message loss is possible.

Mitigations to evaluate when CAN integration begins:

- Use DMA for UART Rx on STM32 (frees CPU from byte-by-byte polling)
- Throttle DCS-BIOS subscriptions to only outputs actually needed
- Increase UART baud rate (115200 → 500000+) to reduce buffer accumulation
- Verify CAN interrupt latency under worst-case DCS-BIOS burst traffic

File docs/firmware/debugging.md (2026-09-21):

# Debugging on STM32

Two things tell you what an STM32 board is doing: the **DiagSerial** debug stream and the
**bi-color status LED**. Neither touches the DCS data path, so you can watch a board in
isolation. This page covers both, plus the bench gotchas that cost the most time.

## DiagSerial — the debug stream

Every STM32 board exposes a debug UART, standard across the project:

| Setting | Value |
|---|---|
| Peripheral | USART1 (`Serial1`) |
| Pins | PA9 (TX) / PA10 (RX) |
| Baud | 115200 |
| Header | 3-pin (GND / RX / TX) on every board |

Connect a USB-to-TTL adapter to the 3-pin header and open a serial monitor at 115200
(`pio device monitor`). Enable output by calling `STM32Board::setDebug(true)` in `setup()`;
production builds leave it `false` (default) — the pins stay available but silent.

USART1 is used because PanelBridge already uses UART2 (`Serial`, PA2/PA3) for the RP2040 link —
the two never conflict.

## The status LED

Each custom OpenSkyhawk STM32 board has a bi-color red/green LED on fixed pins (**PB14 = red,
PB15 = green**), initialised automatically by `STM32Board::begin()`. Read the board's state at
a glance:

| LED | Meaning |
|-----|---|
| Off | Not powered |
| Red blinking | Booting / initialising |
| Green blinking | Normal — CAN healthy, no data flowing |
| **Green solid** | **Connected — CAN healthy and data flowing** (DCS exports on PanelBridge; `CTRL_BCAST` on PanelGroup) |
| Red fast blink | TEC > 0 — transmit errors accumulating |
| Red solid | Bus-off — CAN controller halted |
| Amber flicker (alternating) | Warning / degraded state |

The state machine is shared (`STM32Board`); only the triggers differ per role. **Green solid
(connected)** appears while data is actively flowing and decays back to green-blinking after
~½ s of quiet. **Amber (warning)** means a tracked PanelGroup node died (PanelBridge), the
master heartbeat was lost (PanelGroup), or the board's **clock failed to lock** (any STM32
node — see below).

CAN faults are driven from the `CanStatus` callback. For non-CAN faults (dead node, lost
master, SYNC timeout, I²C hang), the firmware calls `STM32Board::setWarning(true)` and clears
it with `setWarning(false)` on recovery.

One warning source outranks all others: a **clock fault**. If `SystemClock_Config` can't lock
the 72 MHz HSE tree (dead crystal, cold joint, or an inconsistent config), `STM32Board` latches
it, falls back to internal RC, and drives amber at **top precedence** — above CAN faults — so a
bad clock isn't misdiagnosed as a bus problem. A clock-faulted node also comes up **CAN
listen-only** (never transmits at the wrong rate). Latched once at boot (query
`STM32Board::clockFault()`); `begin()` logs
`CLOCK OK/FAULT: SYSCLK=.. PCLK1=.. CAN=..bps ADC=..kHz` on DiagSerial. This detects a missing/dead crystal, not a wrong-value one. See issue #245 /
[Design Decisions](../architecture/design-decisions.md).

!!! note "PB14/PB15 are reserved"
    The status-LED pins are owned by `STM32Board` — don't use PB14/PB15 for panel I/O or
    MCP23017 interrupts. PC13/PC14/PC15 are also off-limits on custom boards.

## Bench gotchas

!!! warning "ST-Link won't upload or connect"
    Old probe firmware ("only supports deprecated HLA") or a clone's non-standard tap ID
    ("tap not found") — see [Flashing → ST-Link troubleshooting](../guides/flashing.md#st-link-troubleshooting).

!!! warning "Don't use STM32 USB CDC for DCS-BIOS"
    Enabling STM32 native USB CDC (`PIO_FRAMEWORK_ARDUINO_ENABLE_CDC`) and running DCS-BIOS
    traffic over it **crashes the port** consistently — it becomes unusable until replug. This
    is the whole reason the [SimGateway](../architecture/sim-gateway.md) exists. Use UART; let
    the RP2040 handle USB. (Also: USB and CAN share PA11/PA12 and can't both be active.)

- **Don't remap `Serial` to `Serial1`** via `#define Serial Serial1` — it causes "multiple
  definition of Serial2" or runtime failures depending on the STM32duino version. With no CDC
  flag, `Serial` maps to UART2 (PA2/PA3) natively, which is what PanelBridge uses for the
  RP2040 link.

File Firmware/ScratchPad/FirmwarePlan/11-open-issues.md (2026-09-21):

# 11 — Open Issues

**Owns:** resolved-design index and historical review notes.
**Does not own:** active requirements. Active requirements live in the owning contract files.

---

## Status

✅ **No active open issues.**

All previously listed items have been resolved and moved into the documents that own the
actual contract. This file is now a pointer map so resolved issues do not get re-opened by
accident during later review passes.

---

## Resolved Decisions

| Item | Resolution | Owner |
|---|---|---|
| PanelBridge heartbeat on CAN | **Implemented in #93.** PanelBridge transmits `HB_0` / `canIdHb(0)` every 500 ms as a master-liveness beacon; PanelGroup accepts it (`filterAcceptId(canIdHb(0))`) and raises WARNING if it stops for > 1500 ms after a master has been seen. | `02-can-protocol.md`, `06-panelbridge-api.md`, `08-hardware-firmware-contracts.md` |
| `ERROR_PASSIVE` status | No separate public `CanStatus` for now. `TX_ERROR` maps to STM32Board `CAN_ERROR`; `BUS_OFF` maps to `BUS_OFF`. EPVF remains available in heartbeat flags. (Re-confirmed #93 — deferred again.) | `02-can-protocol.md`, `STM32Board TechSpec` |
| CAN batching | `ControlPacketPair` batching is part of CANProtocol, not a conditional optimization. PanelBridge and PanelGroup submit individual `ControlPacket`s; single-packet frames use slot B `controlId = 0x0000` as the null sentinel. | `02-can-protocol.md`, `06-panelbridge-api.md` |
| New node state request | READY and dead/unseen → alive recovery both trigger a `SYNC_REQ` broadcast so the node re-polls and sends its current input state. | `06-panelbridge-api.md`, `09-startup-resync-diagnostics.md` |
| `SwitchWithCover2Pos` | **Re-resolved (D16):** follows `DcsBios::SwitchWithCover2Pos` — one pin, sequences the cover. The A-4E-C uses it 0× (its only cover, `AFCS_1N2_COVER`, guards a 3-position switch the mod doesn't gate, and has its own `DCSIN_*`); kept for DCS-BIOS parity and scheduled in v0.1.0 (#293). | `05-panelgroup-api.md`, `10-implementation-plan.md`, `TechSpec/PanelGroup/Inputs/SwitchWithCover2Pos.md` |
| `GENERATOR_GAPS.md` | A4EC generator always emits this file alongside generated headers. All skipped controls must be listed with a reason. | `A4ECGenerator TechSpec`, `10-implementation-plan.md` |
| RotarySwitch boot position | **Superseded (D16): class dropped.** Starting at position 0 and re-syncing at an end stop can jump the sim away from a mission preset; `RotaryEncoder` DIR drives bounded selectors statelessly instead. | `05-panelgroup-api.md`, `00-decisions.md` |
| DRV8833 `~SLEEP` | `~SLEEP` is HIGH from setup for homing torque and remains HIGH. | `05-panelgroup-api.md`, `08-hardware-firmware-contracts.md` |
| PS3/PS4 thumbstick prototype | Allowed for early stick tests; replace with AS5600/MT6701 for final hardware. | This file, prototyping note below |
| Stale `DCSInput` references | Cleanup task during implementation: scan headers and remove stale names. | `10-implementation-plan.md` |
| Accel encoder value encoding | **Superseded (#147, D16):** acceleration is a larger `±step` on the REL frame — no arg strings, no bridge change. Thresholds follow DCS-BIOS: 175 ms fast, 500 ms momentum reset. | `04-dcs-bios-integration.md`, `05-panelgroup-api.md` |
| SimGateway boot sequence | TinyUSB silently drops HID before enumeration; no special handling required. | `07-simgateway-api.md`, `09-startup-resync-diagnostics.md` |
| DIAG destination | DiagSerial only on each STM32 board; no SimGateway diagnostic multiplexing. | `09-startup-resync-diagnostics.md` |
| AngleSensorInput range | Inherited from `AnalogInput` (D16): 0–65535 on both routes; HID-routed axes are calibrated and converted to the signed joystick range in SimGateway. | `05-panelgroup-api.md`, `07-simgateway-api.md` |

---

## PS3/PS4 Thumbstick Module — Prototyping Note

A PS3/PS4 replacement thumbstick module (Alps RKJXU/RKJXV series) can substitute for
AS5600/MT6701 sensors for initial stick sub-node testing.

**Pinout (5-pin, left to right with pins facing down):** VCC · VRx · VRy · SW · GND

- Run at **3.3 V** — output range 0–3.3 V maps directly to STM32 ADC.
- Resting position outputs ~VCC/2 (~1.65 V = ~32767 out of 65535). Sketch dead-band must
  account for mid-scale centre, not zero.
- Wire VRx / VRy as `AnalogInput` via `PinRef(STM32_ADC_PIN)`. SW as `Switch2Pos`.
- **Limitation:** mechanical wear over time. Replace with AS5600/MT6701 for the final build.

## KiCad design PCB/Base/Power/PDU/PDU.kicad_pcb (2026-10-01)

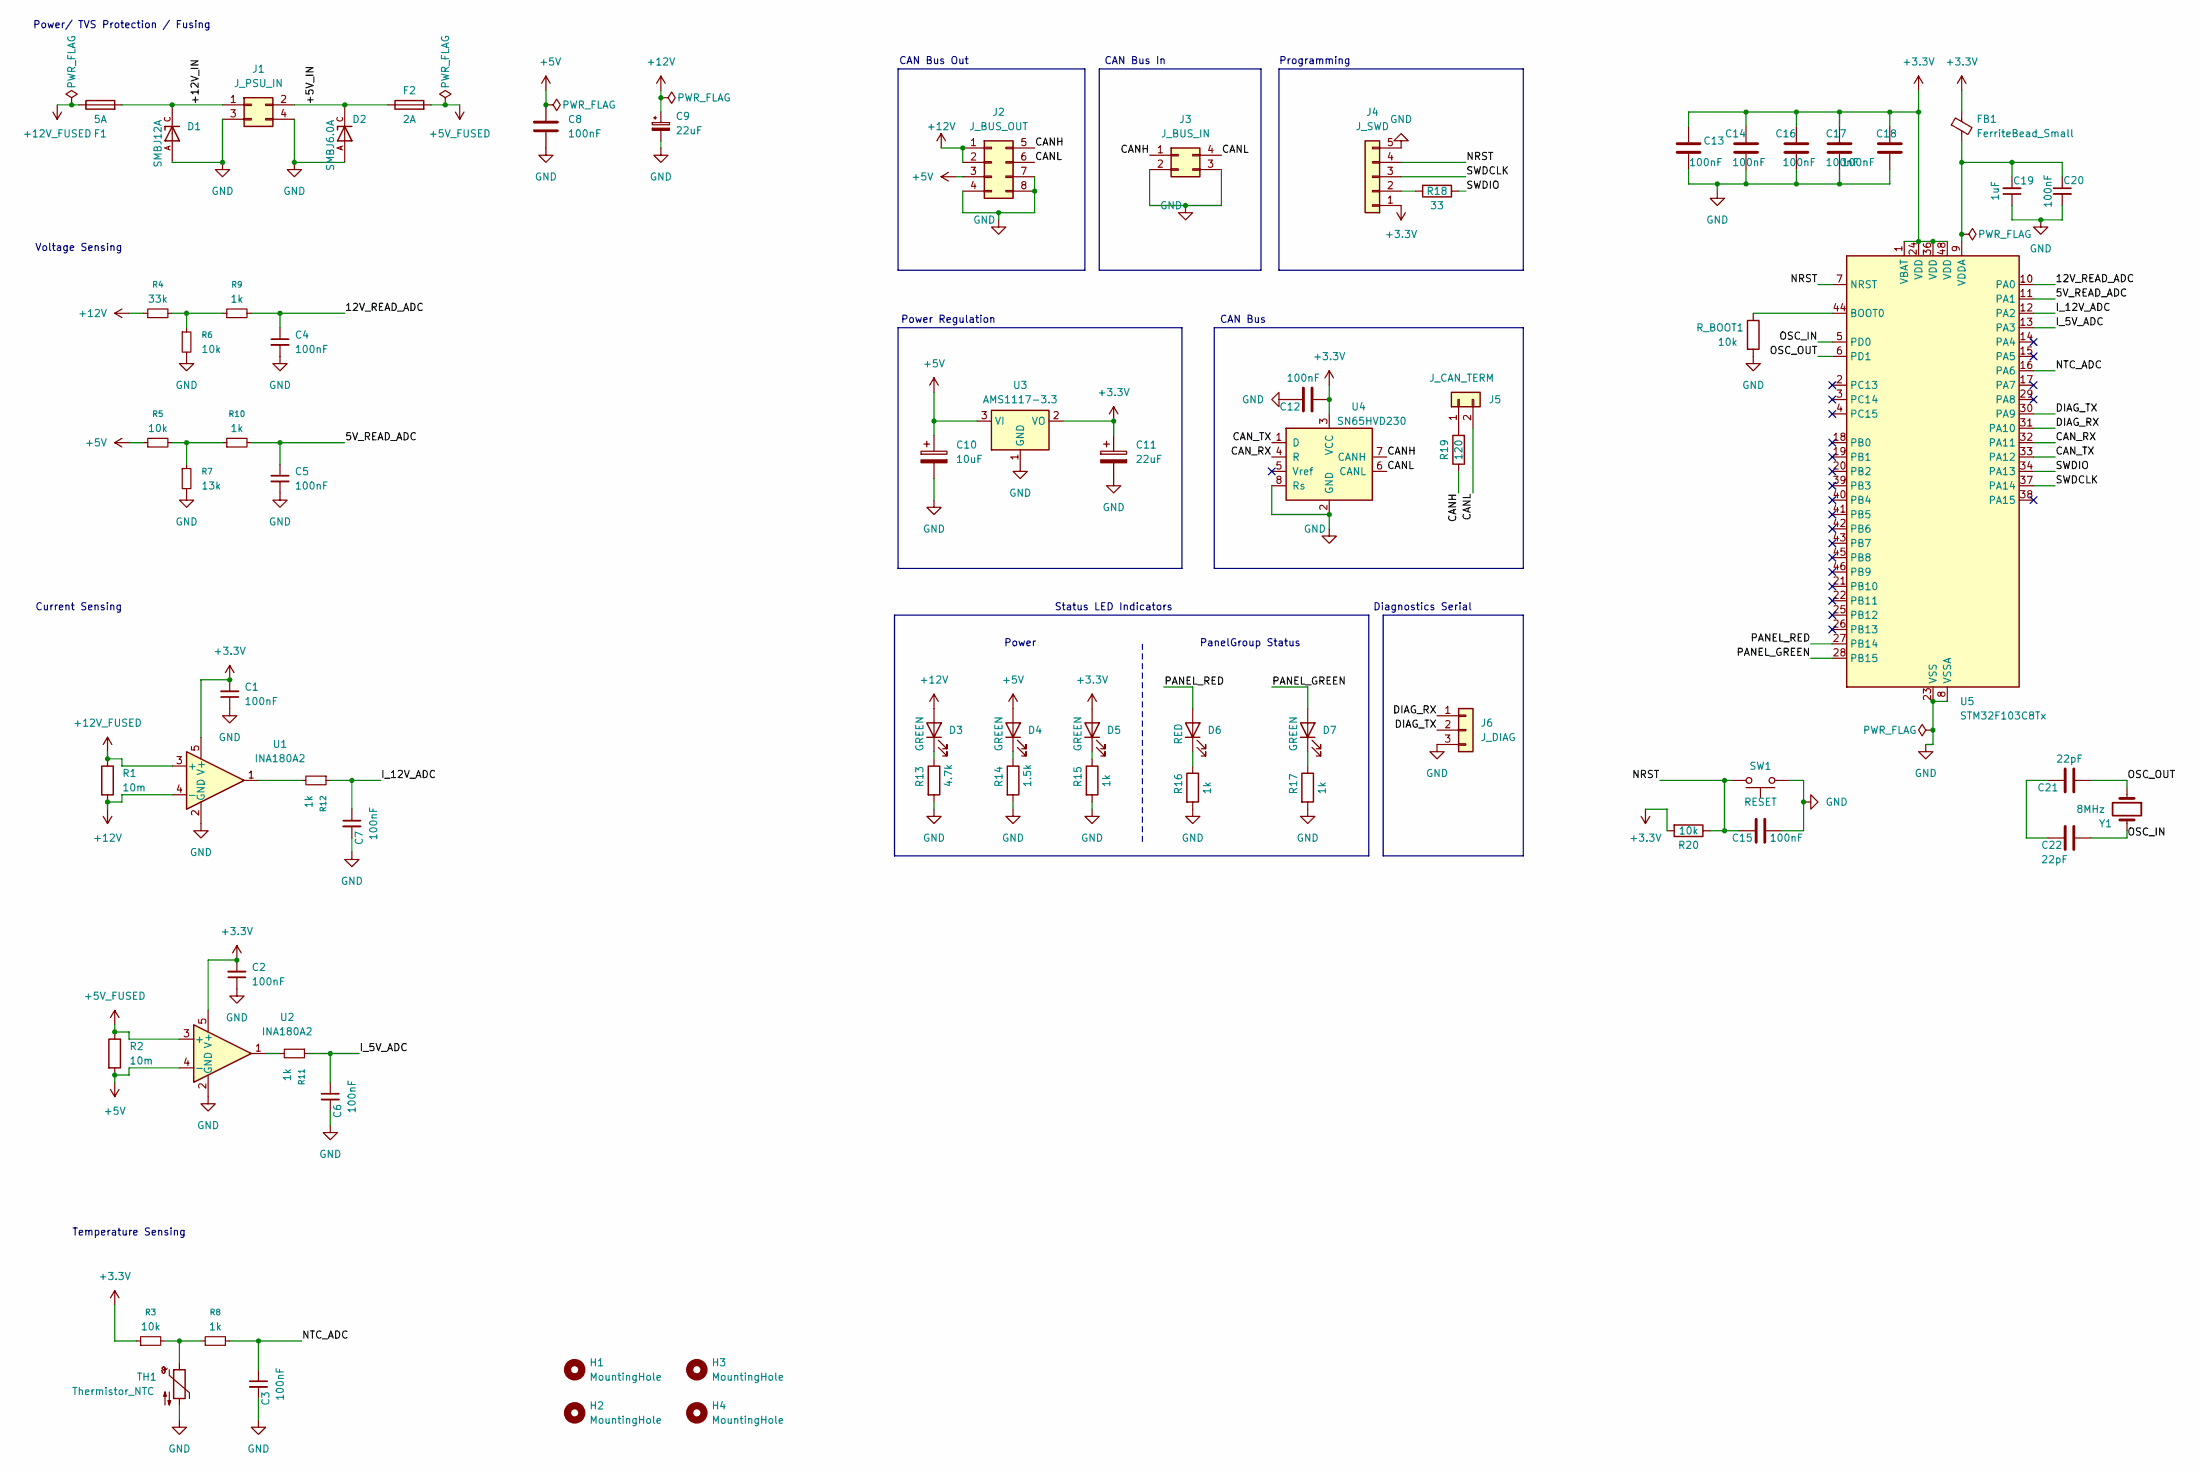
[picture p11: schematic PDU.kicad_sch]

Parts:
C1, C2, C3, C4, C5, C6, C7, C8, C12, C13, C14, C15, C16, C17, C18, C20: 100nF; C_0805_2012Metric; Rating 50V; Tolerance 10%; LCSC C1711
C9: 22uF; CP_Elec_5x5.4; Rating 35V; Tolerance 20%; LCSC C48971029
C10: 10uF; CP_Elec_4x5.4; Rating 25V; Tolerance 20%; LCSC C3343
C11: 22uF; CP_Elec_4x5.4; Rating 16V; Tolerance 20%; LCSC C72502
C19: 1uF; C_0805_2012Metric; Rating 50V; Tolerance 10%; LCSC C28323
C21, C22: 22pF; C_0805_2012Metric; Rating 50V; Tolerance 5%; LCSC C1804
D1: SMBJ12A; DIOM4336X265N; PARTREV F2102; LCSC C42368008
D2: SMBJ6.0A; DIOM4336X265N; PARTREV NA; LCSC C5331096
D3, D4, D5, D7: GREEN; LED_0805_2012Metric; LCSC C19171393
D6: RED; LED_0805_2012Metric; LCSC C19171391
F1: 5A; FUSE-TH_4P-L16.0-W6.7; LCSC C19727305
F2: 2A; FUSE-TH_4P-L16.0-W6.7; LCSC C19727305
FB1: FerriteBead_Small; L_0805_2012Metric; LCSC C21519
H1, H2, H3, H4: MountingHole; MountingHole_2.7mm_M2.5
J1: J_PSU_IN; Molex_Mini-Fit_Jr_5566-04A_2x02_P4.20mm_Vertical; LCSC C20608114
J2: J_BUS_OUT; Molex_Mini-Fit_Jr_5566-08A_2x04_P4.20mm_Vertical; LCSC C20608116
J3: J_BUS_IN; Molex_Mini-Fit_Jr_5566-04A_2x02_P4.20mm_Vertical; LCSC C20608114
J4: J_SWD; PinHeader_1x05_P2.54mm_Vertical
J5: J_CAN_TERM; PinHeader_1x02_P2.54mm_Vertical
J6: J_DIAG; JST_XH_B3B-XH-A_1x03_P2.50mm_Vertical; LCSC C51940188
R1, R2: 10m; R_2512_6332Metric; Rating 3W; Tolerance 1%; LCSC C2903468
R3, R5: 10k; R_0805_2012Metric; Rating 1/8W; Tolerance 1%; LCSC C844937
R4: 33k; R_0805_2012Metric; Rating 1/8W; Tolerance 0.1%; LCSC C2828767
R6, R20: 10k; R_0805_2012Metric; Rating 1/8W; Tolerance 0.1%; LCSC C406725
R7: 13k; R_0805_2012Metric; Rating 1/8W; Tolerance 0.1%; LCSC C865184
R8, R9, R10, R11, R12, R15, R16, R17: 1k; R_0805_2012Metric; Rating 1/8W; Tolerance 1%; LCSC C844939
R13: 4.7k; R_0805_2012Metric; Rating 1/8W; Tolerance 1%; LCSC C844941
R14: 1.5k; R_0805_2012Metric; Rating 1/8W; Tolerance 1%; LCSC C49254235
R18: 33; R_0805_2012Metric; Rating 1/8W; Tolerance 1%; LCSC C2090807
R19: 120; R_0805_2012Metric; Rating 1/8W; Tolerance 1%; LCSC C844816
R_BOOT1: 10k; R_0805_2012Metric; Rating 1/8W; Tolerance 1%; LCSC C844937
SW1: RESET; SW_PUSH_6mm; LCSC C2939600
TH1: Thermistor_NTC; R_1206_3216Metric; Tolerance 1%; LCSC C52155460
U1, U2: INA180A2; SOT-23-5; LCSC C192764
U3: AMS1117-3.3; SOT-223-3_TabPin2; LCSC C347222
U4: SN65HVD230; SOIC-8_3.9x4.9mm_P1.27mm; LCSC C12084
U5: STM32F103C8Tx; LQFP-48_7x7mm_P0.5mm; LCSC C8734
Y1: 8MHz; Crystal_SMD_5032-2Pin_5.0x3.2mm; LCSC C20617997

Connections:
+3.3V: C1.2, C2.2, C11.1, C12.1, C13.1, C14.1, C16.1, C17.1, C18.1, D5.2 (A), FB1.1, J4.1, R3.1, R20.2, U1.5 (V+), U2.5 (V+), U3.2 (VO), U4.3 (VCC), U5.1 (VBAT), U5.24 (VDD), U5.36 (VDD), U5.48 (VDD)
+5V: C8.1, C10.1, D4.2 (A), J2.3, R2.2, R5.1, U2.4 (-), U3.3 (VI)
+5V_FUSED: F2.2, R2.1, U2.3 (+)
+12V: C9.1, D3.2 (A), J2.1, J2.2, R1.2, R4.1, U1.4 (-)
+12V_FUSED: F1.1, R1.1, U1.3 (+)
/5V_READ_ADC: C5.1, R10.2, U5.11 (PA1)
/12V_READ_ADC: C4.1, R9.2, U5.10 (PA0)
/+5V_IN: D2.C, F2.1, J1.2
/+12V_IN: D1.C, F1.2, J1.1
/CANH: J2.5, J3.1, R19.1, U4.7 (CANH)
/CANL: J2.6, J3.4, J5.2, U4.6 (CANL)
/CAN_RX: U4.4 (R), U5.32 (PA11)
/CAN_TX: U4.1 (D), U5.33 (PA12)
/DIAG_RX: J6.1, U5.31 (PA10)
/DIAG_TX: J6.2, U5.30 (PA9)
/I_5V_ADC: C6.1, R11.1, U5.13 (PA3)
/I_12V_ADC: C7.1, R12.1, U5.12 (PA2)
/NRST: C15.1, J4.4, R20.1, SW1.2, U5.7 (NRST)
/NTC_ADC: C3.1, R8.2, U5.16 (PA6)
/OSC_IN: C22.1, U5.5 (PD0), Y1.2
/OSC_OUT: C21.2, U5.6 (PD1), Y1.1
/PANEL_GREEN: D7.2 (A), U5.28 (PB15)
/PANEL_RED: D6.2 (A), U5.27 (PB14)
/SWDCLK: J4.3, U5.37 (PA14)
/SWDIO: R18.1, U5.34 (PA13)
GND: C1.1, C2.1, C3.2, C4.2, C5.2, C6.2, C7.2, C8.2, C9.2, C10.2, C11.2, C12.2, C13.2, C14.2, C15.2, C16.2, C17.2, C18.2, C19.1, C20.2, D1.A, D2.A, J1.3, J1.4, J2.4, J2.7, J2.8, J3.2, J3.3, J4.5, J6.3, R6.2, R7.2, R13.2, R14.2, R15.2, R16.2, R17.2, R_BOOT1.2, SW1.1, TH1.2, U1.2 (GND), U2.2 (GND), U3.1 (GND), U4.2 (GND), U4.8 (Rs), U5.8 (VSSA), U5.23 (VSS), U5.35 (VSS), U5.47 (VSS)
unnamed: C21.1, C22.2
unnamed: D3.1 (K), R13.1
unnamed: D4.1 (K), R14.1
unnamed: D5.1 (K), R15.1
unnamed: D6.1 (K), R16.1
unnamed: D7.1 (K), R17.1
unnamed: J4.2, R18.2
unnamed: J5.1, R19.2
unnamed: R3.2, R8.1, TH1.1
unnamed: R4.2, R6.1, R9.1
unnamed: R5.2, R7.1, R10.1
unnamed: R11.2, U2.1
unnamed: R12.2, U1.1
unnamed: R_BOOT1.1, U5.44 (BOOT0)
unnamed: C19.2, C20.1, FB1.2, U5.9 (VDDA)

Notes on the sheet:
Current Sensing
CAN Bus
Programming
Temperature Sensing
Diagnostics Serial
PanelGroup Status
Power Regulation
Power
Power/ TVS Protection / Fusing
Status LED Indicators
CAN Bus In
CAN Bus Out
Voltage Sensing

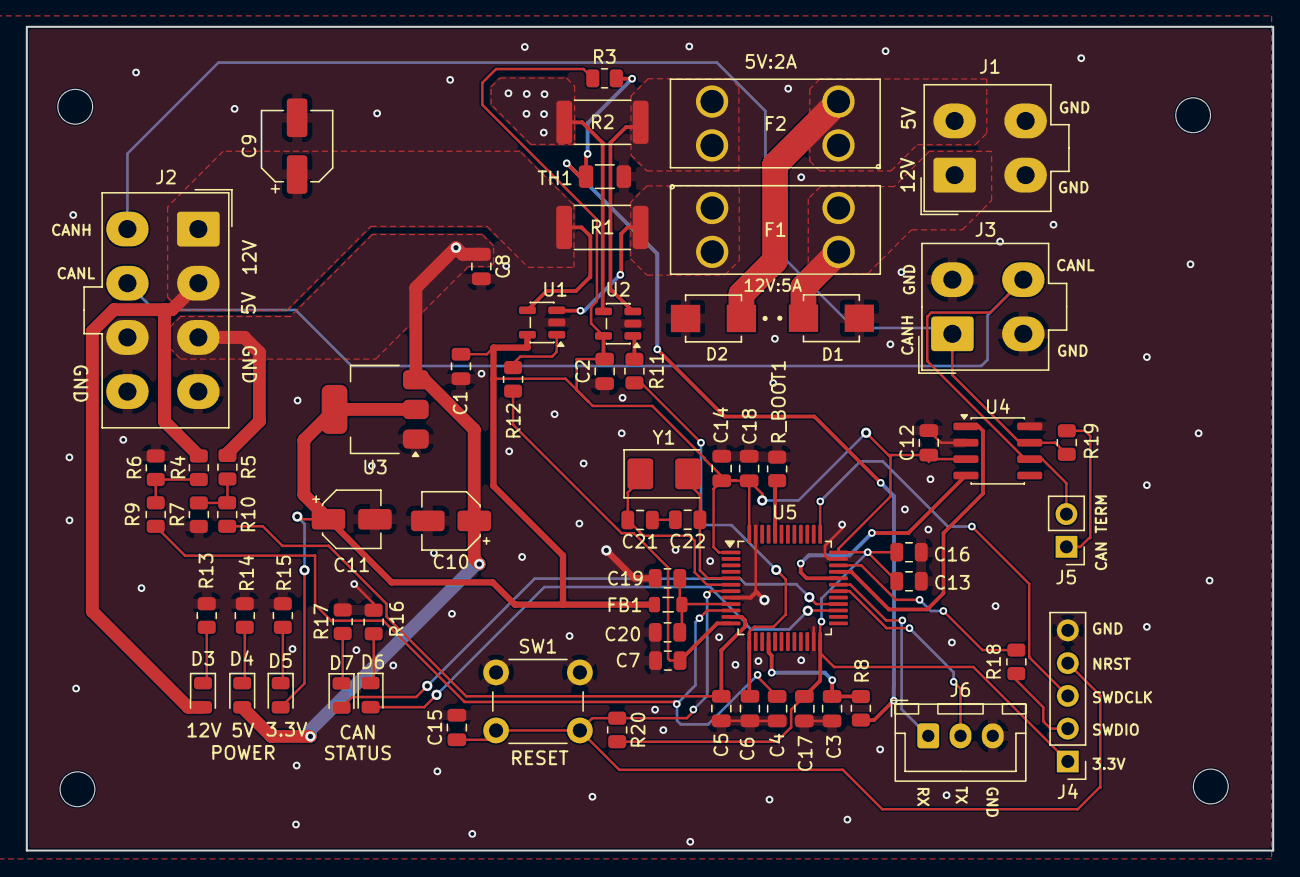
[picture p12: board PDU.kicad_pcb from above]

Board: 2 copper layers, 96.6 x 63.9 mm, 71 parts (0 on the bottom side), 41 nets.

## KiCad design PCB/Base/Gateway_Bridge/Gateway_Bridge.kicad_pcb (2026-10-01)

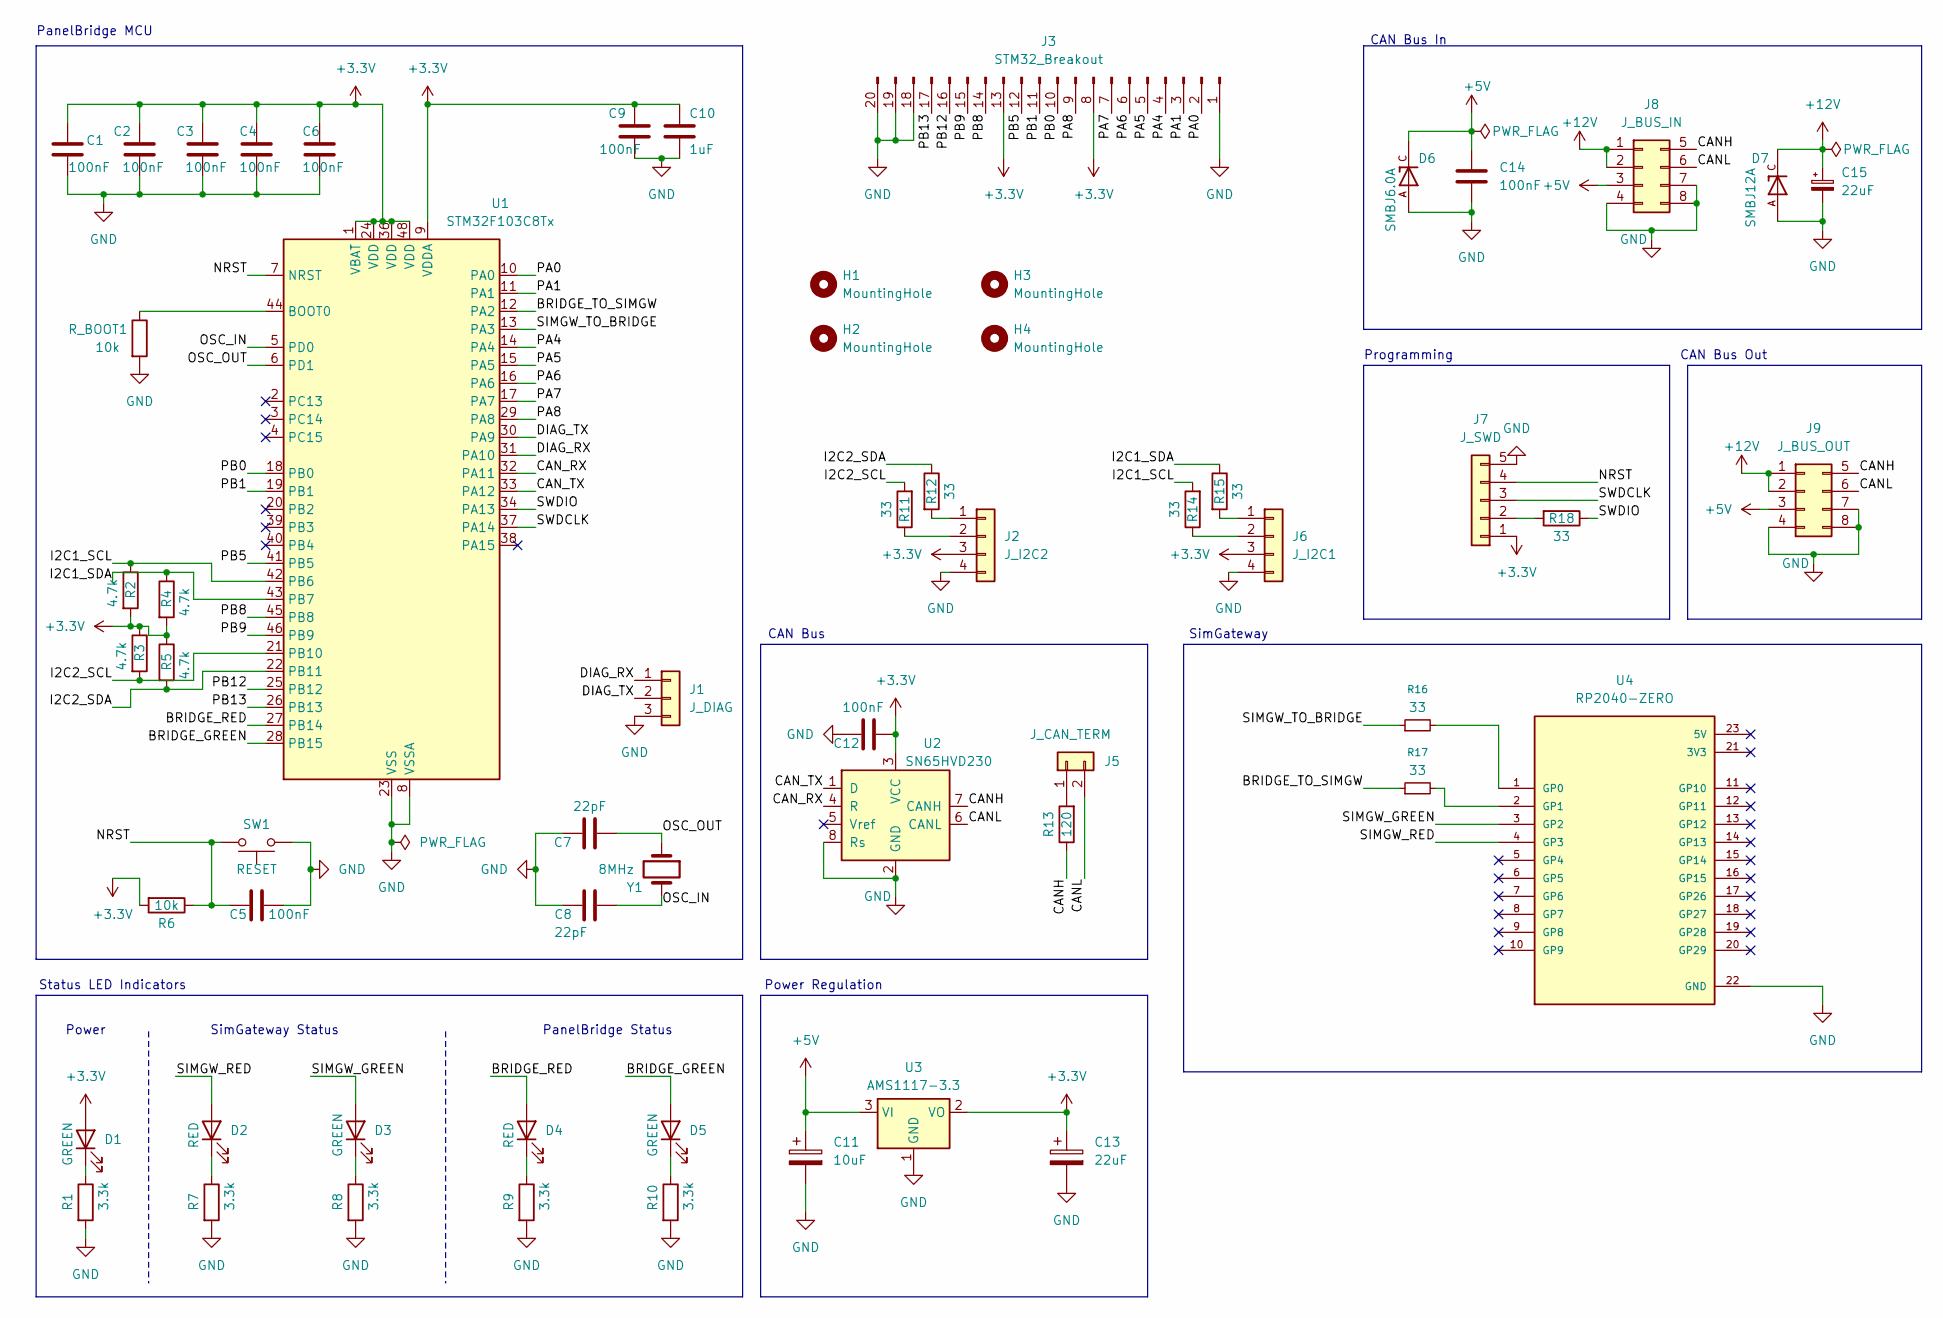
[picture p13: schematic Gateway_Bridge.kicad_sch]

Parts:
C1, C2, C3, C4, C5, C6, C9, C12, C14: 100nF; C_0805_2012Metric; Rating 50V; Tolerance 10%; LCSC C1711
C7, C8: 22pF; C_0805_2012Metric; Rating 50V; Tolerance 5%; LCSC C1804
C10: 1uF; C_0805_2012Metric; Rating 50V; Tolerance 10%; LCSC C28323
C11: 10uF; CP_Elec_4x5.4; Rating 25V; Tolerance 20%; LCSC C3343
C13: 22uF; CP_Elec_4x5.4; Rating 16V; Tolerance 20%; LCSC C72502
C15: 22uF; CP_Elec_5x5.4; Rating 35V; Tolerance 20%; LCSC C48971029
D1, D3, D5: GREEN; LED_0805_2012Metric; LCSC C19171393
D2, D4: RED; LED_0805_2012Metric; LCSC C19171391
D6: SMBJ6.0A; DIOM4336X265N; PARTREV NA; LCSC C5331096
D7: SMBJ12A; DIOM4336X265N; PARTREV F2102; LCSC C42368008
H1, H2, H3, H4: MountingHole; MountingHole_2.7mm_M2.5
J1: J_DIAG; JST_XH_B3B-XH-A_1x03_P2.50mm_Vertical; LCSC C51940188
J2: J_I2C2; JST_XH_B4B-XH-A_1x04_P2.50mm_Vertical; LCSC C23067544
J3: STM32_Breakout; PinHeader_1x20_P2.54mm_Vertical
J5: J_CAN_TERM; PinHeader_1x02_P2.54mm_Vertical
J6: J_I2C1; JST_XH_B4B-XH-A_1x04_P2.50mm_Vertical; LCSC C23067544
J7: J_SWD; PinHeader_1x05_P2.54mm_Vertical
J8: J_BUS_IN; Molex_Mini-Fit_Jr_5566-08A_2x04_P4.20mm_Vertical; LCSC C20608116
J9: J_BUS_OUT; Molex_Mini-Fit_Jr_5566-08A_2x04_P4.20mm_Vertical; LCSC C20608116
R1, R7, R8, R9, R10: 3.3k; R_0805_2012Metric; Rating 1/8W; Tolerance 1%; LCSC C844412
R2, R3, R4, R5: 4.7k; R_0805_2012Metric; Rating 1/8W; Tolerance 1%; LCSC C844941
R6: 10k; R_0805_2012Metric; Rating 1/8W; Tolerance 1%; LCSC C844937
R11, R12, R14, R15, R16, R17, R18: 33; R_0805_2012Metric; Rating 1/8W; Tolerance 1%; LCSC C2090807
R13: 120; R_0805_2012Metric; Rating 1/8W; Tolerance 1%; LCSC C844816
R_BOOT1: 10k; R_0805_2012Metric; Rating 1/8W; Tolerance 1%; LCSC C844937
SW1: RESET; SW_PUSH_6mm; LCSC C2939600
U1: STM32F103C8Tx; LQFP-48_7x7mm_P0.5mm; LCSC C8734
U2: SN65HVD230; SOIC-8_3.9x4.9mm_P1.27mm; LCSC C12084
U3: AMS1117-3.3; SOT-223-3_TabPin2; LCSC C347222
U4: RP2040-ZERO; MODULE_RP2040-ZERO; PARTREV NA
Y1: 8MHz; Crystal_SMD_5032-2Pin_5.0x3.2mm; LCSC C20617997

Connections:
+3.3V: C1.1, C2.1, C3.1, C4.1, C6.1, C9.1, C10.1, C12.1, C13.1, D1.2 (A), J2.3, J3.8, J3.13, J6.3, J7.1, R2.2, R3.1, R4.2, R5.1, R6.2, U1.1 (VBAT), U1.9 (VDDA), U1.24 (VDD), U1.36 (VDD), U1.48 (VDD), U2.3 (VCC), U3.2 (VO)
+5V: C11.1, C14.1, D6.C, J8.3, J9.3, U3.3 (VI)
+12V: C15.1, D7.C, J8.1, J8.2, J9.1, J9.2
/BRIDGE_GREEN: D5.2 (A), U1.28 (PB15)
/BRIDGE_RED: D4.2 (A), U1.27 (PB14)
/BRIDGE_TO_SIMGW: R17.1, U1.12 (PA2)
/CANH: J8.5, J9.5, R13.1, U2.7 (CANH)
/CANL: J5.2, J8.6, J9.6, U2.6 (CANL)
/CAN_RX: U1.32 (PA11), U2.4 (R)
/CAN_TX: U1.33 (PA12), U2.1 (D)
/DIAG_RX: J1.1, U1.31 (PA10)
/DIAG_TX: J1.2, U1.30 (PA9)
/I2C1_SCL: R2.1, R14.2, U1.42 (PB6)
/I2C1_SDA: R4.1, R15.1, U1.43 (PB7)
/I2C2_SCL: R3.2, R11.2, U1.21 (PB10)
/I2C2_SDA: R5.2, R12.1, U1.22 (PB11)
/NRST: C5.1, J7.4, R6.1, SW1.2, U1.7 (NRST)
/OSC_IN: C8.1, U1.5 (PD0), Y1.2
/OSC_OUT: C7.2, U1.6 (PD1), Y1.1
/PA0: J3.2, U1.10 (PA0)
/PA1: J3.3, U1.11 (PA1)
/PA4: J3.4, U1.14 (PA4)
/PA5: J3.5, U1.15 (PA5)
/PA6: J3.6, U1.16 (PA6)
/PA7: J3.7, U1.17 (PA7)
/PA8: J3.9, U1.29 (PA8)
/PB0: J3.10, U1.18 (PB0)
/PB1: J3.11, U1.19 (PB1)
/PB5: J3.12, U1.41 (PB5)
/PB8: J3.14, U1.45 (PB8)
/PB9: J3.15, U1.46 (PB9)
/PB12: J3.16, U1.25 (PB12)
/PB13: J3.17, U1.26 (PB13)
/SIMGW_GREEN: D3.2 (A), U4.3 (GP2)
/SIMGW_RED: D2.2 (A), U4.4 (GP3)
/SIMGW_TO_BRIDGE: R16.1, U1.13 (PA3)
/SWDCLK: J7.3, U1.37 (PA14)
/SWDIO: R18.1, U1.34 (PA13)
GND: C1.2, C2.2, C3.2, C4.2, C5.2, C6.2, C7.1, C8.2, C9.2, C10.2, C11.2, C12.2, C13.2, C14.2, C15.2, D6.A, D7.A, J1.3, J2.4, J3.1, J3.18, J3.19, J3.20, J6.4, J7.5, J8.4, J8.7, J8.8, J9.4, J9.7, J9.8, R1.2, R7.2, R8.2, R9.2, R10.2, R_BOOT1.2, SW1.1, U1.8 (VSSA), U1.23 (VSS), U1.35 (VSS), U1.47 (VSS), U2.2 (GND), U2.8 (Rs), U3.1 (GND), U4.22 (GND)
unnamed: D1.1 (K), R1.1
unnamed: D2.1 (K), R7.1
unnamed: D3.1 (K), R8.1
unnamed: D4.1 (K), R9.1
unnamed: D5.1 (K), R10.1
unnamed: J2.1, R12.2
unnamed: J2.2, R11.1
unnamed: J5.1, R13.2
unnamed: J6.1, R15.2
unnamed: J6.2, R14.1
unnamed: J7.2, R18.2
unnamed: R_BOOT1.1, U1.44 (BOOT0)
unnamed: R16.2, U4.1 (GP0)
unnamed: R17.2, U4.2 (GP1)

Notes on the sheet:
Power Regulation
PanelBridge Status
SimGateway Status
Programming
SimGateway
PanelBridge MCU
CAN Bus Out
Power
CAN Bus In
CAN Bus
Status LED Indicators

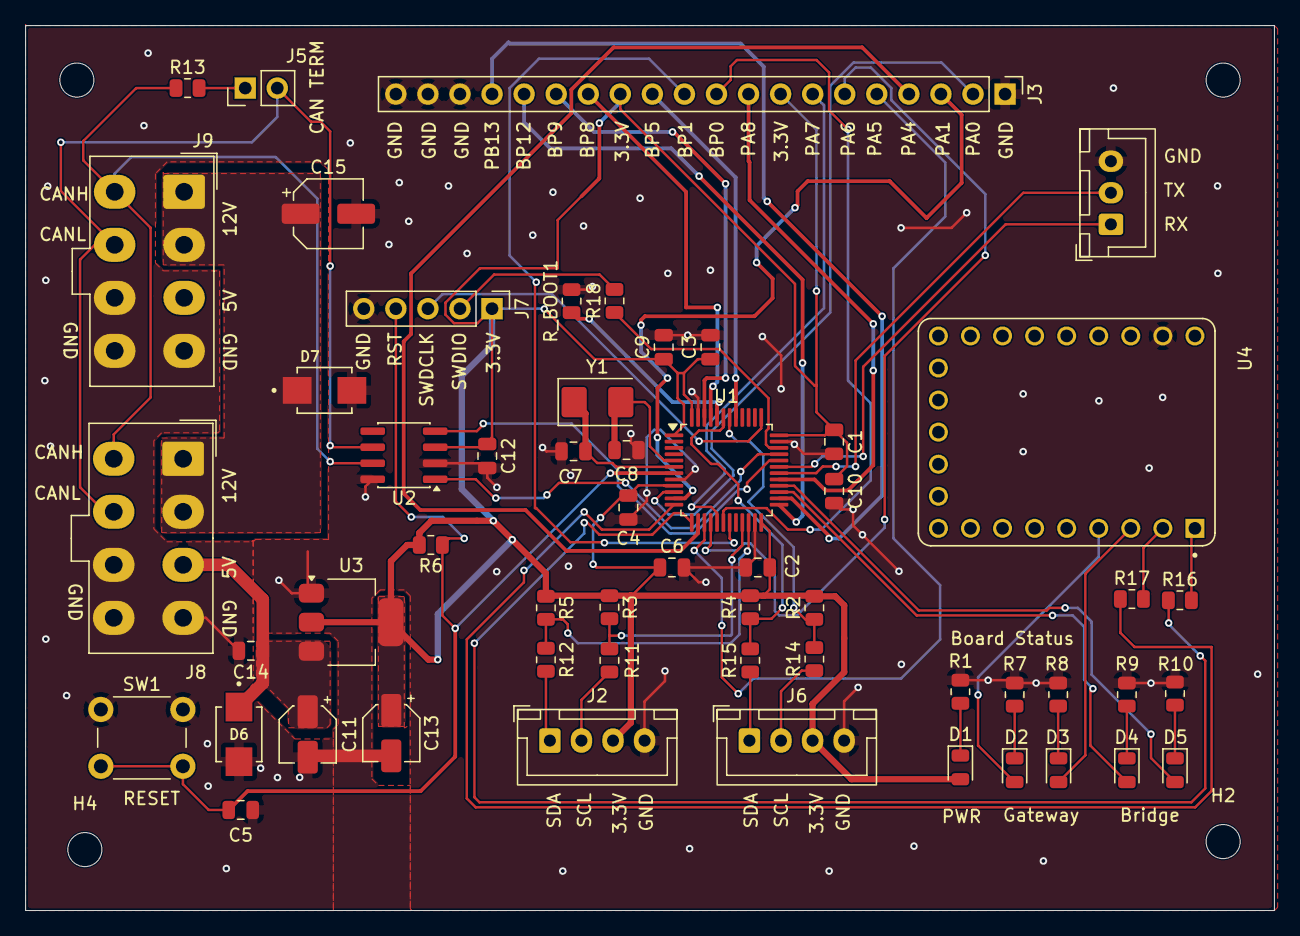
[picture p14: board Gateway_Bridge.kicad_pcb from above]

Board: 2 copper layers, 98.9 x 70.1 mm, 59 parts (0 on the bottom side), 53 nets.

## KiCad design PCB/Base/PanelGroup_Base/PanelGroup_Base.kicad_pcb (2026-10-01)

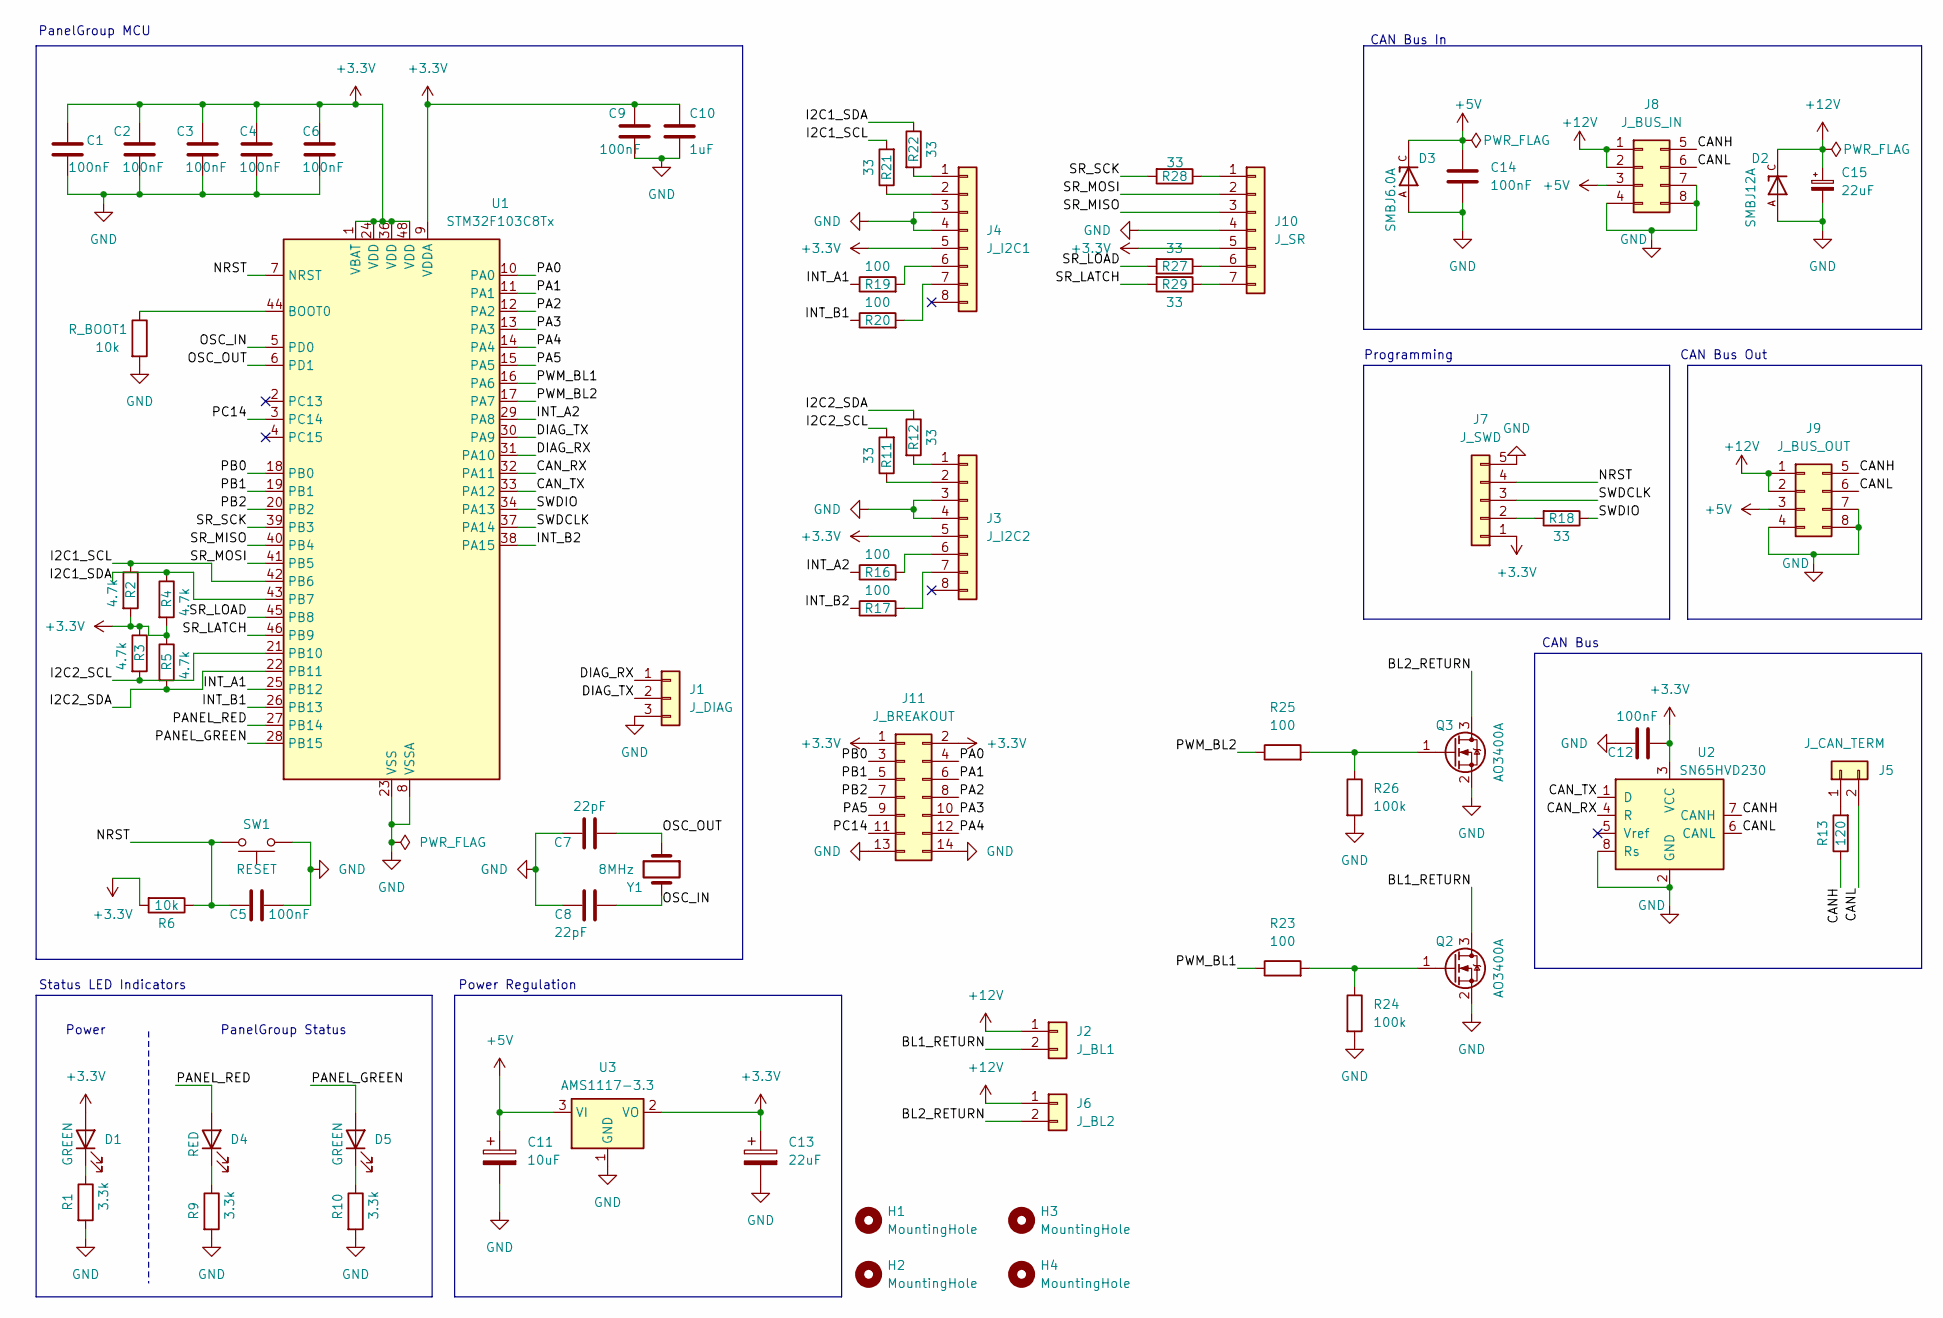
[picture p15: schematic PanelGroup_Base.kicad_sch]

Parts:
C1, C2, C3, C4, C5, C6, C9, C12, C14: 100nF; C_0805_2012Metric; Rating 50V; Tolerance 10%; LCSC C1711
C7, C8: 22pF; C_0805_2012Metric; Rating 50V; Tolerance 5%; LCSC C1804
C10: 1uF; C_0805_2012Metric; Rating 50V; Tolerance 10%; LCSC C28323
C11: 10uF; CP_Elec_4x5.4; Rating 25V; Tolerance 20%; LCSC C3343
C13: 22uF; CP_Elec_4x5.4; Rating 16V; Tolerance 20%; LCSC C72502
C15: 22uF; CP_Elec_5x5.4; Rating 35V; Tolerance 20%; LCSC C48971029
D1, D5: GREEN; LED_0805_2012Metric; LCSC C19171393
D2: SMBJ12A; DIOM4336X265N; PARTREV F2102; LCSC C42368008
D3: SMBJ6.0A; DIOM4336X265N; PARTREV NA; LCSC C5331096
D4: RED; LED_0805_2012Metric; LCSC C19171391
H1, H2, H3, H4: MountingHole; MountingHole_2.7mm_M2.5
J1: J_DIAG; JST_XH_B3B-XH-A_1x03_P2.50mm_Vertical; LCSC C51940188
J2: J_BL1; Molex_Mini-Fit_Jr_5566-02A_2x01_P4.20mm_Vertical; LCSC C20608113
J3: J_I2C2; JST_XH_B8B-XH-A_1x08_P2.50mm_Vertical; LCSC C23067548
J4: J_I2C1; JST_XH_B8B-XH-A_1x08_P2.50mm_Vertical; LCSC C23067548
J5: J_CAN_TERM; PinHeader_1x02_P2.54mm_Vertical
J6: J_BL2; Molex_Mini-Fit_Jr_5566-02A_2x01_P4.20mm_Vertical; LCSC C20608113
J7: J_SWD; PinHeader_1x05_P2.54mm_Vertical
J8: J_BUS_IN; Molex_Mini-Fit_Jr_5566-08A_2x04_P4.20mm_Vertical; LCSC C20608116
J9: J_BUS_OUT; Molex_Mini-Fit_Jr_5566-08A_2x04_P4.20mm_Vertical; LCSC C20608116
J10: J_SR; JST_XH_B7B-XH-A_1x07_P2.50mm_Vertical; LCSC C144398
J11: J_BREAKOUT; PinHeader_2x07_P2.54mm_Vertical
Q2, Q3: AO3400A; SOT-23; Rating 30V; LCSC C49195711
R1, R9, R10: 3.3k; R_0805_2012Metric; Rating 1/8W; Tolerance 1%; LCSC C844412
R2, R3, R4, R5: 4.7k; R_0805_2012Metric; Rating 1/8W; Tolerance 1%; LCSC C844941
R6: 10k; R_0805_2012Metric; Rating 1/8W; Tolerance 1%; LCSC C844937
R11, R12, R18, R21, R22, R27, R28, R29: 33; R_0805_2012Metric; Rating 1/8W; Tolerance 1%; LCSC C2090807
R13: 120; R_0805_2012Metric; Rating 1/8W; Tolerance 1%; LCSC C844816
R16, R17, R19, R20, R23, R25: 100; R_0805_2012Metric; Rating 1/8W; Tolerance 1%; LCSC C844936
R24, R26: 100k; R_0805_2012Metric; Rating 1/8W; Tolerance 1%; LCSC C844935
R_BOOT1: 10k; R_0805_2012Metric; Rating 1/8W; Tolerance 1%; LCSC C844937
SW1: RESET; SW_PUSH_6mm; LCSC C2939600
U1: STM32F103C8Tx; LQFP-48_7x7mm_P0.5mm; LCSC C8734
U2: SN65HVD230; SOIC-8_3.9x4.9mm_P1.27mm; LCSC C12084
U3: AMS1117-3.3; SOT-223-3_TabPin2; LCSC C347222
Y1: 8MHz; Crystal_SMD_5032-2Pin_5.0x3.2mm; LCSC C20617997

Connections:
+3.3V: C1.1, C2.1, C3.1, C4.1, C6.1, C9.1, C10.1, C12.1, C13.1, D1.2 (A), J3.5, J4.5, J7.1, J10.5, J11.1, J11.2, R2.2, R3.1, R4.2, R5.1, R6.2, U1.1 (VBAT), U1.9 (VDDA), U1.24 (VDD), U1.36 (VDD), U1.48 (VDD), U2.3 (VCC), U3.2 (VO)
+5V: C11.1, C14.1, D3.C, J8.3, J9.3, U3.3 (VI)
+12V: C15.1, D2.C, J2.1, J6.1, J8.1, J8.2, J9.1, J9.2
/BL1_RETURN: J2.2, Q2.3
/BL2_RETURN: J6.2, Q3.3
/CANH: J8.5, J9.5, R13.1, U2.7 (CANH)
/CANL: J5.2, J8.6, J9.6, U2.6 (CANL)
/CAN_RX: U1.32 (PA11), U2.4 (R)
/CAN_TX: U1.33 (PA12), U2.1 (D)
/DIAG_RX: J1.1, U1.31 (PA10)
/DIAG_TX: J1.2, U1.30 (PA9)
/I2C1_SCL: R2.1, R21.2, U1.42 (PB6)
/I2C1_SDA: R4.1, R22.1, U1.43 (PB7)
/I2C2_SCL: R3.2, R11.2, U1.21 (PB10)
/I2C2_SDA: R5.2, R12.1, U1.22 (PB11)
/INT_A1: R19.1, U1.25 (PB12)
/INT_A2: R16.1, U1.29 (PA8)
/INT_B1: R20.1, U1.26 (PB13)
/INT_B2: R17.1, U1.38 (PA15)
/NRST: C5.1, J7.4, R6.1, SW1.2, U1.7 (NRST)
/OSC_IN: C8.1, U1.5 (PD0), Y1.2
/OSC_OUT: C7.2, U1.6 (PD1), Y1.1
/PA0: J11.4, U1.10 (PA0)
/PA1: J11.6, U1.11 (PA1)
/PA2: J11.8, U1.12 (PA2)
/PA3: J11.10, U1.13 (PA3)
/PA4: J11.12, U1.14 (PA4)
/PA5: J11.9, U1.15 (PA5)
/PANEL_GREEN: D5.2 (A), U1.28 (PB15)
/PANEL_RED: D4.2 (A), U1.27 (PB14)
/PB0: J11.3, U1.18 (PB0)
/PB1: J11.5, U1.19 (PB1)
/PB2: J11.7, U1.20 (PB2)
/PC14: J11.11, U1.3 (PC14)
/PWM_BL1: R23.1, U1.16 (PA6)
/PWM_BL2: R25.1, U1.17 (PA7)
/SR_LATCH: R29.2, U1.46 (PB9)
/SR_LOAD: R27.2, U1.45 (PB8)
/SR_MISO: J10.3, U1.40 (PB4)
/SR_MOSI: J10.2, U1.41 (PB5)
/SR_SCK: R28.2, U1.39 (PB3)
/SWDCLK: J7.3, U1.37 (PA14)
/SWDIO: R18.1, U1.34 (PA13)
GND: C1.2, C2.2, C3.2, C4.2, C5.2, C6.2, C7.1, C8.2, C9.2, C10.2, C11.2, C12.2, C13.2, C14.2, C15.2, D2.A, D3.A, J1.3, J3.3, J3.4, J4.3, J4.4, J7.5, J8.4, J8.7, J8.8, J9.4, J9.7, J9.8, J10.4, J11.13, J11.14, Q2.2, Q3.2, R1.2, R9.2, R10.2, R24.2, R26.2, R_BOOT1.2, SW1.1, U1.8 (VSSA), U1.23 (VSS), U1.35 (VSS), U1.47 (VSS), U2.2 (GND), U2.8 (Rs), U3.1 (GND)
unnamed: D1.1 (K), R1.1
unnamed: D4.1 (K), R9.1
unnamed: D5.1 (K), R10.1
unnamed: J3.1, R12.2
unnamed: J3.2, R11.1
unnamed: J3.6, R16.2
unnamed: J3.7, R17.2
unnamed: J4.1, R22.2
unnamed: J4.2, R21.1
unnamed: J4.6, R19.2
unnamed: J4.7, R20.2
unnamed: J5.1, R13.2
unnamed: J7.2, R18.2
unnamed: J10.1, R28.1
unnamed: J10.6, R27.1
unnamed: J10.7, R29.1
unnamed: Q2.1, R23.2, R24.1
unnamed: Q3.1, R25.2, R26.1
unnamed: R_BOOT1.1, U1.44 (BOOT0)

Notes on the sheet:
Programming
Status LED Indicators
Power Regulation
PanelGroup MCU
CAN Bus In
CAN Bus
Power
PanelGroup Status
CAN Bus Out

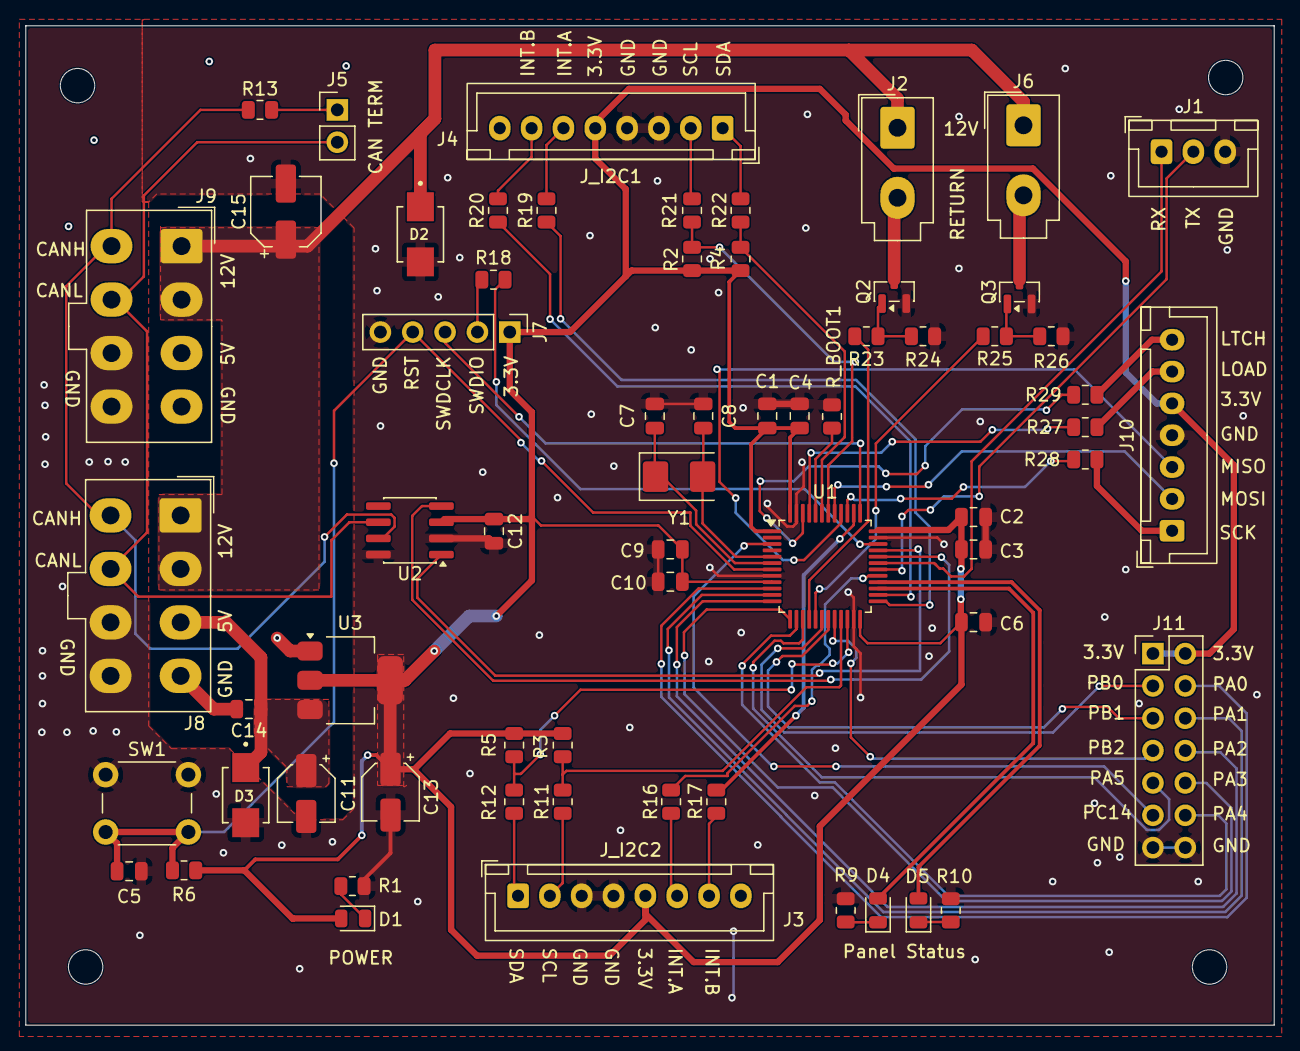
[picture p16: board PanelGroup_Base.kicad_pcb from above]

Board: 2 copper layers, 98.0 x 78.5 mm, 68 parts (0 on the bottom side), 63 nets.

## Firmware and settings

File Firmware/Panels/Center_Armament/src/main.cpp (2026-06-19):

// Center_Armament controller — STM32F103CBT6
// See docs/_source/controllers/Center_Armament.md for pinout, I2C addresses, and DCS-BIOS mappings.
// See docs/_source/architecture.md for firmware architecture.

#include <Arduino.h>

void setup() {
    // TODO: implement Center_Armament controller
}

void loop() {
}

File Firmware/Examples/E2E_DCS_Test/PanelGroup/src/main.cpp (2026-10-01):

// E2E_DCS_Test — PanelGroup node (STM32F103C8, NODE_ID=1)
//
// ONGOING integration node: one live instance of every control class we build, driven by real
// DCS-BIOS over CAN (SimGateway → PanelBridge → this node via CTRL_BCAST). Add new controls to
// the wiring-map sections below as they land; PanelGroup::setup()/loop() drive them all.
//
// Digital I/O:
//   LED    PC13 (built-in, active-LOW)            → A_4E_C_D_GLARE_WHEELS (Master Test lamp)
//   Button PB0  (active-LOW, 10kΩ pull-up to 3V3) → DCSIN_MASTER_TEST
// Needle gauge — X27 air-core stepper via DRV8833 (coils PA0/PA1/PA4/PA5):
//   APN-153 DRIFT needle ← A_4E_C_APN153_DRIFT_GAUGE (centre-zero)
// OLED drum readouts — TCA9548A @ 0x70 on J_I2C2 (I2C2: SCL=PB10, SDA=PB11), each panel @ 0x3C:
//   ch0 → current longitude  (NAV_CURPOS_LON, 6 digits + E/W flag)
//   ch1 → ARC-51 UHF frequency (ARC51_FREQ, 5 digits + '.', e.g. 225.50)
// DCS-routed inputs (bench: 2 EC11 encoders + 2 pots — see README.md for wiring + pull-ups):
//   RotaryEncoder REL  DEST_LAT_KNB     PA8/PB5  → ±step  / canIdEvtRel / "%+d"
//   RotaryEncoder DIR  ARC51_FREQ_10MHZ PB3/PB4  → ±1     / canIdEvtDir / INC-DEC (steps ch1 drum)
//   AnalogInput        ARC51_VOL        PA2 pot  → 16-bit / canIdEvt    / "%u"
//   AnalogMultiPos     ARC51_MODE       PA3 pot  → index  / canIdEvt    / "%u"
//   (PB3/PB4 are JTAG-DP pins — STM32Board::begin() releases JTAG, keeping SWD, so they're plain GPIO.)

#include <Wire.h>
#include <OpenSkyhawk.h>
#include <DrumDisplay.h>            // separate opt-in library (not in the OpenSkyhawk umbrella)
#include <Helpers/I2cMux/I2cMux.h>

using namespace OpenSkyhawk;

// ── Digital I/O ───────────────────────────────────────────────────────────────
const PinRef PIN_LED(PC13);
const PinRef PIN_BTN(PB0);

LED        wheelsLight(A_4E_C_D_GLARE_WHEELS, A_4E_C_D_GLARE_WHEELS_AM, PIN_LED, /*reverse=*/true);
Switch2Pos masterTest (DCSIN_MASTER_TEST, PIN_BTN);

// ── APN-153 DRIFT needle — X27 air-core stepper via DRV8833 ─────────────────────
// Centre-zero gauge: DCS 0 → full-left, 32768 → centre, 65535 → full-right. NeedleGauge
// auto-registers like the LED/drums, so PanelGroup::setup() homes it and loop() drives it
// from CTRL_BCAST — the needle tracks live DRIFT data over CAN with no extra code here.
// Homing: into the full-left stop (assigned -150), then park at centre (0); home direction /
// offset are per-gauge bench-tuned. DRV8833 ~SLEEP tied HIGH in hardware (or wire to a spare
// GPIO + pass as the StepperMotor sleepEn arg). makeX27Config bakes the air-core defaults
// (1080 steps/rev, rangeSteps 945, gentle homing); set rangeSteps 960 for a 320° BKA-30.
static const StepperConfig DRIFT_MOTOR =
    makeX27Config(/*home*/-150, /*park*/0, /*minPos*/-150, /*maxPos*/150);
StepperMotor driftMotor(PinRef(PA0), PinRef(PA1), PinRef(PA4), PinRef(PA5), DRIFT_MOTOR);
static const GaugeCal DRIFT_CAL = { -150, 150, /*reverse=*/false, nullptr, nullptr, 0 };
NeedleGauge driftGauge(A_4E_C_APN153_DRIFT_GAUGE, A_4E_C_APN153_DRIFT_GAUGE_AM,
                       driftMotor, DRIFT_CAL);

// ── OLED drum readouts (two panels behind a TCA9548A @ 0x70 on I2C1) ────────────
U8G2_SH1106_128X64_NONAME_F_HW_I2C oledLon  (U8G2_R0, U8X8_PIN_NONE);
U8G2_SH1106_128X64_NONAME_F_HW_I2C oledRadio(U8G2_R0, U8X8_PIN_NONE);
I2cMux drumMux(0x70, Wire);

// Current longitude — XXX.YY plus an E/W hemisphere flag.
//
// Settled against the A-4E-C mod source (#137): the rightmost output is the hemisphere ONLY, never
// a digit. Nav/nav.lua sets NAV_CURPOS_LON_nnnnnX to E_W (0.5 = East, 0.0 = West) and
// NAV_CURPOS_LAT_nnnnX to N_S (0.0 = North, 0.5 = South); ASN41_MAGVAR_xxxxX is the same flag at
// full scale (1 = East, 0 = West). So longitude is 5 digits + flag, latitude 4 + flag, MagVar
// 4 + flag — and a hemisphere that arrives at half scale never reaches the second face through a
// 0xFFFF mask.
//
// The descriptor below now matches: five digit drums, with the hemisphere as the flag at half
// scale (steps = 2, faces ordered W then E).
static const DrumSource LON_SRC[] = {
    { A_4E_C_NAV_CURPOS_LON_X00000, A_4E_C_NAV_CURPOS_LON_X00000_AM, 1, 4 },
    { A_4E_C_NAV_CURPOS_LON_0X0000, A_4E_C_NAV_CURPOS_LON_0X0000_AM, 1, 3 },
    { A_4E_C_NAV_CURPOS_LON_00X000, A_4E_C_NAV_CURPOS_LON_00X000_AM, 1, 2 },
    { A_4E_C_NAV_CURPOS_LON_000X00, A_4E_C_NAV_CURPOS_LON_000X00_AM, 1, 1 },
    { A_4E_C_NAV_CURPOS_LON_0000X0, A_4E_C_NAV_CURPOS_LON_0000X0_AM, 1, 0 },
};
static const DrumReadout LON_READOUT = {
    .sources = LON_SRC, .nSources = 5, .nDigits = 5,
    .digitWidthMm = 4.5f, .digitHeightMm = 8.0f, .interDigitGapMm = 1.0f,
    .flag = { .enabled = true, .address = A_4E_C_NAV_CURPOS_LON_00000X, .mask = A_4E_C_NAV_CURPOS_LON_00000X_AM, .faces = "WE", .atVisualCol = 5, .widthMm = 5.5f, .steps = 2 },
};

// ARC-51 UHF displayed frequency — XXX.XX, so five digits with the dot after the third. The dot
// position below is confirmed correct.
//
// Settled against the mod source (#137): these three outputs are selector POSITIONS, not a grouped
// 00–99 value each. radio_controls2.lua drives ARC51_FREQ_XX000 from the 10 MHz selector (0.00–0.85
// in 0.05 steps, 18 positions → displayed 22–39), ARC51_FREQ_00X00 from the 1 MHz digit (digit/10),
// and ARC51_FREQ_000XX from the 50 kHz selector (0.00–0.95 in 0.05 steps → 00, 05 … 95). Only the
// last is declared {0, 0.95} in DCS-BIOS, so only it normalises to full scale.
// (Raw manual-selector knobs live at A_4E_C_ARC51_FREQ_10MHZ/_1MHZ/_50KHZ, bit-packed — swap to
//  those if you want the knob positions instead of the displayed frequency.)
static const DrumSource ARC51_SRC[] = {
    // Bands, confirmed by pairing each float against its selector's exported position index in a
    // sim capture: 22937 ↔ 10 MHz position 7, 58981 ↔ 1 MHz 9, 62085 ↔ 50 kHz 18, i.e. 299.90.
    // Note the 10 MHz float spans its declared {0,1} range in 0.05 steps — 20 bands, of which the
    // switch only uses 18 — while the selector INTEGER has 18 positions. Band count follows the
    // declared range, not the switch.
    { A_4E_C_ARC51_FREQ_XX000, A_4E_C_ARC51_FREQ_XX000_AM, 2, 3, /*steps*/ 20, /*mul*/ 1, /*offset*/ 22 },
    { A_4E_C_ARC51_FREQ_00X00, A_4E_C_ARC51_FREQ_00X00_AM, 1, 2, /*steps*/ 10 },
    { A_4E_C_ARC51_FREQ_000XX, A_4E_C_ARC51_FREQ_000XX_AM, 2, 0, /*steps*/ 20, /*mul*/ 5 },
};
static const DrumGlyph ARC51_DOT[] = { { '.', 3, 1.8f } };
static const DrumReadout ARC51_READOUT = {
    .sources = ARC51_SRC, .nSources = 3, .nDigits = 5,
    .digitWidthMm = 4.5f, .digitHeightMm = 8.0f, .interDigitGapMm = 1.0f,
    .glyphs = ARC51_DOT, .nGlyphs = 1,
};

DrumDisplay lonDrum  (oledLon,   LON_READOUT,   drumMux, /*channel*/ 0, DrumFont::LARGE);
DrumDisplay radioDrum(oledRadio, ARC51_READOUT, drumMux, /*channel*/ 1, DrumFont::LARGE);
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

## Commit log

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2026-05-17 Fix project setup issues and document confirmed hardware decisions
    - Remove hardcoded absolute path from Misc_Switch_Panel fp-lib-table
    - Narrow .gitignore to settings.local.json; track shared settings.json
    - Rewrite README to reflect OpenSkyhawk name, STM32/CAN/PlatformIO architecture
    - Fill in Center_Armament.md TBDs: STM32F103CBT6, SN65HVD230, AP63205+AMS1117, I2C addresses (0x20-0x22, 0x48), ADC pin assignments
    - Resolve JST-XH harness pin 5 (switched 12V) and pin 6 (3.3V) in architecture.md and hardware-standards.md
    - Add CAN transceiver standard: SN65HVD230, SOIC-8, 3.3V, 120 ohm end termination
    - Add LED backlighting standard: bench-tested resistor table, 120 ohm default, IRLML2502 zo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
    [main.cpp]
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2026-05-17 Complete Misc Switch Panel schematic and establish shared PCB infrastructure
    Misc Switch Panel schematic (3 sheets, 0 ERC violations):
    - Controls sheet: MCP23017 @ 0x22, 8-pin JST-XH harness (J1), address/reset
    resistors, I2C series (33Ω) and interrupt protection (100Ω) resistors
    - Switches sheet: J2/J3 8-pin JST-XH connectors, all panel-mounted switch and
    pot symbols (exclude_from_board)
    - Backlighting sheet: 3× 5-LED series strings, 120Ω per string, hierarchical
    labels +12V_BACKLIGHT / BACKLIGHT_SW_RETURN
    - LED zone switching: IRLML2502 N-ch low-side MOSFET, gate driven directly by
    STM32 3.3V PWM; LED power on separate 2-pin Mini-Fit Jr (J4), not on signal
    harness — elimina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
    [LedBackLight.kicad_sch, Misc_Switch_Panel.kicad_sch, switches.kicad_sch]
2026-05-17 Fix LED_5050_Red symbol polarity: K=pin1, A=pin2
    Symbol body was mirrored vs standard Device:LED convention — pin 1 was
    labelled A and pin 2 K. Flipped triangle/bar to point left and swapped
    pin names so K=1 (left) and A=2 (right), matching the generic KiCad LED
    symbol.
    Physical LED verified: notched/chamfered corner is the ANODE. Footprint
    pad positions unchanged — pad2 (left, where the silkscreen marker sits)
    is now correctly the anode. Updated kicad.md to document this.
    Also includes Misc_Switch_Panel schematic edits from current KiCad session.
    [LedBackLight.kicad_sch, Misc_Switch_Panel.kicad_sch, switches.kicad_sch]
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2026-05-17 Armament_MCU schematic prep: docs, library symbols, root sheet
    - Center_Armament.md: correct J2 pinout, GPIO allocation, power
    architecture, remove wrong gate pull-up and NPN driver rows
    - hardware-standards.md: clarify 12V+5V bus / local AMS1117-3.3
    architecture; AP63205WU only for future high-current boards
    - kicad.md: mark IRLML2502, DRV8835 Ready; SN65HVD230 → built-in
    - OpenSkyhawk.kicad_sym: add IRLML2502 (SOT-23 N-MOSFET) and
    DRV8835 (HTSSOP-16 dual H-bridge) symbols
    - Armament_MCU.kicad_sch: add 4 hierarchical sub-sheet references
    (MCU_CAN, Switches, Backlighting, Gauges)
    - Armament_MCU.kicad_pro: update project settings
    [Armament_MCU.kicad_sch]
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2026-05-18 Document DCS-BIOS STM32 debug findings and Tiny2040 bridge
    STM32 native USB CDC is unusable for DCS-BIOS (crashes under load).
    The working path is UART2 (PA2/PA3) + RP2040 bridge. Chinese Blue Pill
    clones also need a JTAG ID override (0x2ba01477) for ST-Link.
    - Docs/claude/dcsbios-stm32-debug.md: canonical findings — what failed,
    what works, DCS-BIOS defines, verified addresses, open CAN bus concern
    - Firmware/HID_Controllers/DCS_BIOS_Bridge/: Tiny2040 bridge firmware
    (proto stand-in for RP2040 gateway; connects to STM32 CAN master, not
    panel nodes)
    - Firmware/Center_Armament/README.md: CAN-node scope clarification + Blue
    Pill JTAG ID tip; DCS-BIOS content removed (belongs to CAN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
    [main.cpp]
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2026-05-18 Fix CAN error register bugs and sync README with firmware
    ESR/MSR fixes (STM32F103 RM0008):
    - TEC is ESR[23:16], REC is ESR[31:24] — were swapped in both files
    - BOFF/EPVF/EWGF are ESR bits 2/1/0, not MSR bits — were reading wrong register
    in CAN_Test_Master monitorErrors() and CAN_Test_SubNode sendHeartbeat()/updateLed()
    Sub-node canTx() now counts mailbox-full failures in txDrops; bit 2 of the
    heartbeat flags byte is set when any TX drop has occurred since boot.
    README corrections:
    - Commands go over Serial2 USB-TTL (115200), not Arduino USB Serial Monitor
    - Two USB-TTL adapters required (PA9 diagnostic + Serial2 console)
    - Fast burst interval is 2 ms (~500 pkts/sec), not 1.6 ms/62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
    [main.cpp]
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2026-05-18 Fix RTT measurement correctness and T-mode double-count
    Sub-node: echo TEST_SEQ bytes 0-7 unchanged. Previously bytes 4-7 were
    overwritten with sub-node millis(), which made the master's [RTT] log
    meaningless (cross-clock subtraction). Arduino send timestamp now passes
    through intact, letting the Arduino compute RTT within its own clock domain.
    Master: split ECHO_1/ECHO_2 handling. Only ECHO_1 is forwarded to the
    Arduino via DIAG_RTT, so tEchoed reaches exactly T_COUNT (1000) with any
    number of sub-nodes on the bus. ECHO_2 is logged on PA9 but not counted.
    Relabeled [RTT] → [ECHO] on PA9 diagnostic and removed the meaningless
    cross-clock rtt value from that log line.
    Arduino: update head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
    [main.cpp]
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2026-05-19 Switch stepper driver DRV8835 → DRV8833PW; rework IRLML2502 symbol
    DRV8835 is only available in WSON-12 (bottom-terminated, not inspectable
    post-reflow). Replaced throughout with DRV8833PW (HTSSOP-16) which is
    already placed in Gauges.kicad_sch as the placeholder.
    Library: remove DRV8835 symbol block from OpenSkyhawk.kicad_sym; rework
    IRLML2502 symbol body with proper N-channel MOSFET graphical elements
    (was a plain rectangle).
    Docs: update hardware-standards.md stepper driver section (DRV8833PW,
    VINT/VCP/AISEN/FAULT handling); update kicad.md library table; update
    Center_Armament.md MCU board component list.
    Schematics: KiCad project file and sub-sheets updated from Symbol Editor
    sessi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
    [Backlighting.kicad_sch, Gauges.kicad_sch, MCU_CAN.kicad_sch]
2026-05-19 Fix DRV8833PW wiring in Gauges sheet
    - VINT (pin 14): remove +3V3 connection; C18 (100nF) now bypasses VINT
    to GND only (VINT is an output, not a power input)
    - VCP (pin 11): add C19 (100nF) from +5V to VCP for internal charge pump
    - Add PWR_FLAG on VINT net to satisfy ERC
    - Replace VM net label with +5V throughout sheet (same net, cleaner)
    [Gauges.kicad_sch]
2026-05-19 Add AWRS_Panel schematic; refresh symbol caches
    AWRS_Panel: 2-sheet hierarchical breakout board schematic.
    Root sheet: ADS1115 @ 0x48 (ADDR→GND), three RC-filtered analog inputs
    (A0=QTY, A1=DROP INTVL, A2=MODE SEL), 1kΩ+100nF per input, three 4-pin
    JST-XH pot connectors (J1/J3/J5), 6-pin JST-XH MCU harness (J2), VDD
    decoupling (C1 100nF + C2 10µF), status LED (D1+R22), PWR_FLAGs.
    Backlighting sheet: 3 LED strings × 5 LEDs, 3×120Ω resistors, 2-pin
    Mini-Fit Jr (J_LED). Controls sheet: placeholder — panel-mounted switch
    types and position counts deferred until extracted from DCS sim.
    MCU_CAN.kicad_sch, Misc_Switch_Panel.kicad_sch: symbol cache refresh
    from IRLML2502 library rework.
    [AWRS_Panel.kicad_sch, Backlighting.kicad_sch, Controls.kicad_sch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]
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2026-05-19 chore: ignore .claire/ and .vscode/ dirs; save AWRS_Panel schematic state
    - Expand .gitignore: add .claire/ (Claude Code worktrees), consolidate
    scattered .vscode/ file rules into a single **/.vscode/ glob
    - AWRS_Panel.kicad_sch / Controls.kicad_sch: KiCad expanded embedded
    lib_symbols on open/save (Device:C_Small etc.)
    - AWRS_Panel.kicad_pro: used_designators reset by KiCad on save
    [AWRS_Panel.kicad_sch, Controls.kicad_sch]
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2026-05-20 prototype: replace Arduino Mega injector with RP2040 (MicroPython + PlatformIO)
    Switch the CAN bus test injector from Arduino Mega 2560 to an RP2040 module.
    The RP2040 is 3.3V native so no voltage divider is needed on the UART line to
    the STM32 master. It also drives the OLED status display and acts as the
    DCS-BIOS bridge in Experiment C — a single device covers all three experiments.
    - Add CAN_Test_RP2040/main.py — MicroPython: UART packet injection, byte-stream
    relay (Experiment A), OLED status (node alive, TEC/REC, last RTT), analytics
    over USB serial REPL
    - Add CAN_Test_RP2040_PIO/ — PlatformIO variant of the same injector for
    builders who prefer C++ over MicroPython; functi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
    [main.cpp]
2026-05-20 Prototype CAN bus working — SJW=4 fixes crystal tolerance on Blue Pills
    Full end-to-end test confirmed: RP2040 → UART → STM32 master → CAN (125 kbps)
    → sub-node → CAN echo → master → UART → RP2040. RTT = 2 ms, zero packet loss.
    Key fixes:
    - SJW: 1TQ → 4TQ on both master and sub-node (marginal crystal tolerance on
    Blue Pill clones caused CRC errors at SJW=1; SJW=4 gives sufficient
    resynchronisation headroom)
    - Sub-node: add DiagSerial on PA9/PA10 for CAN state visibility (TEC/REC/BOFF)
    - Sub-node: AutoRetransmission DISABLE to prevent runaway bus-off cycle during
    debug; txDrop logging in canTx()
    - Master: handle CAN_ID_HB_2 and CAN_ID_ECHO_2 (sub-node straps as node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
    [main.cpp]
2026-05-20 Prototype CAN bus validated at 500 kbps — 21 min soak, zero errors
    Restore Prescaler=4 (500 kbps) on master and sub-node. SJW=4TQ retained for
    crystal tolerance. 20-minute soak test result: 1257 pings, RTT=1 ms avg/min/max,
    lost=0, TEC=0 REC=0 BOFF=0 throughout.
    Also add CAN_Test_RP2040_PIO project and .gitignore files for prototype builds.
    [main.cpp]
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2026-05-21 firmware: fix six code review findings (P1 × 3, P2 × 3)
    P1 — Sweep IDs 0x0001–0x0004 rejected by PanelBridge: moved to 0x8001–0x8004
    (DCS-BIOS range, always accepted) in both CAN_Test_RP2040/main.py and
    CAN_Test_Arduino. No range filter change needed.
    P1 — Sub-node EVT frames silently dropped: added DIAG_EVT=0x04 to CANProtocol.h;
    PanelBridge now forwards CAN_ID_EVT_1/2 upstream as 8-byte DIAG_EVT frames;
    SimGateway dispatches them via new onDiagEvt(controlId, value, nodeId) callback;
    MicroPython test client prints received events.
    P1 — MicroPython DCS mode consumed stdin as commands: _check_cmd() is now
    skipped when mode == MODE_DCS, preventing binary DCS-BIOS bytes from being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
    [main.cpp]
2026-06-10 firmware: add PlatformIO templates; fix compile errors (Phase 0 complete)
    Three templates now compile clean against their target toolchains:
    - PanelGroup (STM32F103CBT6): PanelGroup.h now includes STM32Board.h so
    STM32Board::setDebug() is available without a direct include in main.cpp
    - PanelBridge (STM32F103CBT6): pass Serial2 to setup() to match current
    library signature; arg will be removed in Phase 2 when DCS-BIOS owns Serial
    - SimGateway (RP2040): remove multigamesystem/MGS-Pico-Joystick lib_dep —
    Joystick.h is provided by earlephilhower/arduino-pico platform natively
    Also add STM32Board.h to PanelBridge.h include chain for the same reason.
    [main.cpp]
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2026-06-11 refactor(firmware): migrate PanelGroup/PanelBridge to CANProtocol API
    PanelGroup and PanelBridge no longer call STM32Board CAN stubs or HAL
    directly. All CAN bus interaction now goes through CANProtocol.
    PanelGroup:
    - processCan() removed; replaced by onCanRx() callback via onReceive()
    - drain() handles TEST_SEQ echo automatically (drops _echoTxId)
    - sendHeartbeat() uses makeHeartbeatPayload() instead of CAN1->ESR reads
    - Dispatches ControlPacketPair (slot A + B) from CTRL_BCAST frames
    - filterAcceptId calls replaced by start() which adds mandatory IDs
    - canStart() -> CANProtocol::start()
    PanelBridge:
    - processCan() removed; replaced by onCanRx() callback via onReceive()
    - tec/rec/busOff()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
    [main.cpp]
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2026-06-11 feat(firmware): PanelBridge Phase 2 — DCS-BIOS integration, CAN cluster master, full test suite
    Implements PanelBridge Phase 2 per FirmwarePlan/06 and TechSpec/PanelBridge.md:
    Library (Firmware/Libraries/PanelBridge/):
    - Rewrites PanelBridge.cpp/h from Phase 1 prototype to full Phase 2 spec
    - DCS-BIOS integration via DCSBIOS_DEFAULT_SERIAL; undef trick prevents ODR violations
    when PanelBridge.cpp and sketch TU both include DcsBios.h
    - BridgeExportListener (file-scope static) intercepts 0x8000–0x86FF exports and
    submits each as ControlPacket to CANProtocol::sendBatched(CAN_ID_CTRL_BCAST)
    - DCS session change detection via StringBuffer on CommonData_MOD_TIME_A (0x0440);
    model-time d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
    [main.cpp]
2026-06-11 fix(firmware): fix CI build failures — broken README link and stale prototype API
    - PanelBridge/README.md: fix relative link to CANProtocol (no README exists, link now points to CANProtocol.h)
    - CAN_Test_Master: update to current PanelBridge API (setup() takes no args; add DcsBios include + setup/loop calls); add DCS-BIOS and A4EC to lib_deps; add -DHSE_VALUE=8000000
    [main.cpp]
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2026-06-12 fix(firmware): add missing STM32Board.h include to PanelGroup template
    main.cpp calls STM32Board::setDebug() directly; PanelGroup.h does not
    pull in STM32Board.h, so the include must be explicit in the sketch.
    [main.cpp]
2026-06-12 fix(firmware): replace PanelGroup::sendEvent with CANProtocol::sendBatched
    sendEvent is not part of the PanelGroup API (not in TechSpec). Use the
    correct path: CANProtocol::sendBatched(canIdEvt(NODE_ID), ControlPacket{...}).
    [main.cpp]
2026-06-12 refactor(firmware): align PanelGroup with TechSpec — LED own files, remove IntegerOutput, private NO_INT_PIN
    - Move LED into LED.h/LED.cpp; PanelGroup no longer defines concrete output classes
    - Remove IntegerOutput (TechSpec status: Not started — deferred to own PR)
    - Make NO_INT_PIN private to PanelGroup.cpp anonymous namespace; expose polling
    overload registerExpander(chip) instead of public sentinel constant
    - Fix ADS1115 registerADC pattern: Adafruit_ADS1115 takes address/bus via begin(),
    not constructor; store addr+wire in ADCEntry, call begin() in setup()
    - Fix ADS1115.h comment to match correct begin() pattern
    - Add CTRL_BCAST DLC guard: early-return if len != sizeof(ControlP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
    [configure.cpp, controlid_filter.cpp, main.cpp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]
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2026-06-12 test(firmware): clarify hardware requirements in configure and reverse LED tests
    Both tests use PB0 and PB1 as output pins read back via digitalRead().
    No external connections needed — updated comments make this explicit so
    the tester knows no wiring is required for these two pins.
    [configure.cpp, reverse.cpp]
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2026-06-12 fix(firmware): replace Serial with STM32Board::diagSerial() in all test files
    UART boards (CH340/CP2102) use HardwareSerial on PA9/PA10 — same as
    STM32Board::diagSerial(). Using Serial directly caused no output because
    the board init path wasn't coordinated. Also removes delay(3000) startup
    wait in favour of STM32Board::begin() which initialises USART1 directly.
    Pattern matches all existing working tests (CANProtocol, STM32Board, PanelBridge).
    All 17 test envs build clean (5 PinRef + 7 PanelGroup + 5 LED).
    [configure.cpp, controlid_filter.cpp, reverse.cpp]
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2026-06-13 feat(firmware): implement Switch2Pos input class
    Debounced 2-position switch on PinRef. Fixed 20 ms wall-clock debounce
    via millis(). Emits CAN EVT via CANProtocol::sendBatched() on confirmed
    state change. poll() is a no-op until forceReport() initialises baseline.
    Supports active-LOW (default) and active-HIGH (reverse=true) polarity.
    6 test envs under Firmware/Tests/Switch2Pos/: configure, force_report,
    debounce, value_encoding, reverse, no_duplicate_evt. Tests use GPIO
    loopback (PB0->PA0 jumper) and CAN silent loopback for EVT verification.
    [configure.cpp, debounce.cpp, force_report.cpp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]
2026-06-13 test(firmware): address Switch2Pos review findings
    reverse: remove dead gFwdCount/gRevCount counters and unused
    prevFwdVal/prevRevVal variables.
    debounce: fix elapsed-time comment (was "25 ms", actual ~29 ms due
    to flushDrain overhead); add Phase C covering bounce-through-confirmed
    then settle at new state — verifies _debounceStartMs resets on each
    raw change, not just on first direction change.
    [debounce.cpp, reverse.cpp]
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2026-06-13 fix(template): restore _AM suffix corrupted by replace_all in LED comment
    replace_all on 'A_4E_C_<ID>_A' also replaced the _A prefix inside _AM,
    turning A_4E_C_<ID>_AM into A_4E_C_<ID>M. Fix: restore the mask suffix.
    Correct comment format:
    A_4E_C_<ID> — address (no _A suffix; matches generated A4EC_OutputIds.h)
    A_4E_C_<ID>_AM — mask (matches generated _AM suffix)
    [main.cpp]
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2026-06-13 chore: move E2E_DCS_Test from Prototype/ to Examples/
    Promotes the three-board end-to-end sketch (SimGateway + PanelBridge +
    PanelGroup) to a permanent reference example. All three sketches compile
    clean against current Libraries. Library paths unchanged — both locations
    sit 3 levels deep under Firmware/ so ${PROJECT_DIR}/../../../Libraries
    resolves correctly.
    Closes #32
    [main.cpp]
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2026-06-15 fix(examples): E2E_DCS_Test LED uses MASTER_TEST readback, not GEAR_LIGHT
    GEAR_LIGHT stays 0 during Master Test in the A-4E-C community mod.
    MASTER_TEST readback (0x8512, AM=0x0004) mirrors the switch position via
    DCS-BIOS export, confirming the full EVT→PanelBridge→DCS→CTRL_BCAST→LED
    round-trip.
    [main.cpp]
2026-06-15 fix(examples): E2E_DCS_Test LED → D_GLARE_WHEELS (illuminates during Master Test)
    GEAR_LIGHT (bit 15, 0x8000) never sets during Master Test.
    D_GLARE_WHEELS (0x845c, bit 8, 0x0100) confirmed lit during Master Test via
    SkyHawkClient log — better E2E signal as it tests a real cockpit output.
    [main.cpp]
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2026-06-17 feat(pcb): complete PanelGroup base board + CI fixes
    PanelGroup_Base: schematic (ERC clean) + PCB layout (DRC clean).
    Generic STM32F103C8 CAN sub-node - I2C with INT lines (8-pin),
    backlight MOSFET drivers (Q2/Q3, PWM_BL1/BL2 on PA6/PA7), 2x7
    breakout, 4x M2.5 mounting holes. Built by copy-paste from the
    Gateway/Bridge base block. Prototype ordered from JLCPCB (red).
    Gateway/Bridge: layout refinements (still ERC 0 / DRC 0).
    Docs: base-boards.md backlight section synced to schematic naming
    (PWM_BL1/BL2, BLn_RETURN, J_BL pin order). Added combined order BOM
    CSV (both boards, deduped, for the LCSC order).
    CI fixes:
    - .gitattributes: mark 3D-model assets (*.STEP etc.) binary so
    `git diff --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
    [Gateway_Bridge.kicad_pcb, PanelGroup_Base.kicad_pcb, PanelGroup_Base.kicad_sch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]
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2026-06-17 fix(pcb): make Armament_MCU and AWRS_Panel ERC-clean
    Two WIP prototype KiCad projects had ERC violations that fail the
    strict all-projects KiCad CI check (kicad-cli sch erc runs on every
    project when PCB/Libraries/** changes), keeping the base-board PR red.
    Armament_MCU (MCU_CAN.kicad_sch) — 4 -> 0:
    - Deleted two dead stub wires whose far ends dangled at the PB10/PB11
    (U1 pin 21/22) connection points.
    - Added no_connect flags on pins 21/22, which are unused on this
    prototype (matches the existing NC pattern on that pin column).
    AWRS_Panel (Controls.kicad_sch) — 24 -> 0:
    - Snapped 23 off-grid wire endpoints in the SW1 rotary staircase to the
    50 mil grid (half-grid jog vertices, sh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
    [Controls.kicad_sch, MCU_CAN.kicad_sch]
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2026-06-18 A1: AN/ASN-41 inventory, Right_Navigation grouping, base pin reference
    - Recategorize NAV_DEAD (PNT_255) from Doppler Nav to MCL — it physically
    lives on the AN/ARA-63 MCL panel, not ASN-41
    - Add LCSC part numbers to hardware-standards: ADS1115IDGSR (C37593),
    DRV8833PWPR (C50506), MCP23017-E/SS (C506653)
    - Claim NODE_ID 2 for Right_Navigation controller
    - panel-pipeline skill: A-phase research checklist (drop B-phase coords/dims
    items); cache PanelGroup base fixed-resource reference (reserved pins,
    13 breakout GPIO, I2C/INT layout, backlight)
    [a4ec-control-inventory.csv]
2026-06-18 NeedleGauge: generic pointer-gauge class; APN-153 A1 prereq
    Rename the needle/pointer gauge output to a backend-agnostic class:
    - SwitecX25Output → NeedleGauge (constructor-selected backend: Switec X25 /
    AccelStepper / servo). Supersedes the planned ServoOutput +
    AccelStepperOutput, which become backends.
    - TechSpec: consolidate the three output stubs under NeedleGauge.md; note the
    shared low-level motor/servo driver base shared with DrumDisplay.
    - CSV: rename 119 SwitecX25Output → NeedleGauge; fix the 3 APN153_SPEED drum
    digits to DrumDisplay (drum readout, not a needle). Broader NeedleGauge vs
    DrumDisplay vs lighting/flag reclassification of the remaining gauge rows is
    def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
    [a4ec-control-inventory.csv]
2026-06-18 ARC-51A UHF: A1 control classification fixes
    CSV fw_class corrections from DCS-BIOS + A1 review of the AN/ARC-51A UHF
    radio control panel:
    - ARC51_XMIT_MODE: SwitchMultiPos → Switch3Pos (define3PosTumb: PRESET/MAN/GD-XMIT)
    - ARC51_MODE: SwitchMultiPos/enc/ladder → SwitchMultiPos (4-pos function selector;
    one-hot GPIO — VOL is the panel's only ADC input)
    - ARC51_FREQ_PRE / _10MHZ / _1MHZ / _50KHZ: AnalogMultiPos → RotaryEncoder
    (18–20 position counts make a resistor ladder marginal; encoders send
    DCS-BIOS fixed_step, display reflects sim state)
    - ARC51_FREQ_XX000 / _00X00 / _000XX / _PRESET: NeedleGauge → DrumDisplay
    (frequency "220.00 MC" + preset-channel windows are dig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
    [a4ec-control-inventory.csv]
2026-06-18 Center_Armament A1: Armament + AWRS panel classification fixes
    - ARM_EMERG_SEL, ARM_FUNC_SEL: SwitchMultiPos/enc/ladder → AnalogMultiPos (7-pos ladders)
    - AWRS_QUANT: drop (>7) flag → AnalogMultiPos (12-pos on 16-bit ADS1115)
    - AWRS_MODE: SwitchMultiPos/enc/ladder → AnalogMultiPos (6-pos)
    Armament Panel: 10 inputs + CABIN_ALT NeedleGauge (710); cabin gauge is
    motorized. AWRS: 4 inputs all on ADS1115 @ 0x48, POWER LED on harness spare.
    [a4ec-control-inventory.csv]
2026-06-18 Misc Switch Panel A1: BDHI_MODE → Switch3Pos, SHRIKE_SEL_KNB → SwitchMultiPos
    BDHI_MODE (724) is define3PosTumb (NAV PAC/TACAN/NAV CMPTR); SHRIKE_SEL_KNB
    (725) is a 5-pos one-hot selector. CONT/NORM (727) stays ticket-only
    (no DCS binding). All 3 Center_Armament sub-panels now A1-classified.
    [a4ec-control-inventory.csv]
2026-06-19 docs: publish base-boards hardware page; fix renamed docs/claude links
    From the week-ending 2026-06-19 docs-drift review (#127).
    New published page:
    - docs/hardware/base-boards.md — feature-led overview of the Gateway/Bridge
    and PanelGroup base boards (promoted from the docs/_source engineering
    reference), with per-board at-a-glance specs, highlights, and board-render
    placeholders. Deep electrical detail (pinouts, net labels, BOM) is left to
    the public PCB/Base KiCad projects, not the private docs/_source space.
    - Embeds the two board schematic SVGs under assets/images/diagrams.
    - Adds the page to the Hardware Reference nav.
    Dead-link fixes (docs/claude/ was renamed to docs/_sour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
    [main.cpp]
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
